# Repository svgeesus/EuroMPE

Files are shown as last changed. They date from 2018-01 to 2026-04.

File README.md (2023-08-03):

# EuroMPE

There are my notes-in-progress on a Eurorack MPE implementation (MIDI to control voltage). There are currently two parts:

- [Polyphonic](./Polyphonic/Design%20notes.md), 4 to 8 voices (historical)
- [Duophonic](./Duophonic/readme.md), 2 voices

The **polyphonic** one was the first thing I explored, but it was eventually abandoned for two reasons. Firstly an eight-voice polyphonic system would be very expensive to build, and the quality I wanted. But more importantly I realised the sheer impracticality of a four or eight voice polyphonic system in Eurorack. Yes, there are quad modules aplenty. But they all have to be set identically which also means, unless you are an octopus, that they all have to be wiggled in unison and that is just nt feasible. And freakishly expensive. So this was shelved.

Somewhat later, after I had got myself a duophonic synth (ARP Odyssey) I came to realise that **duophonic** is a separate thing from fully polyphonic and from monophonic. It makes sense to use two hands and multiple fingers, because as keys lift other notes sound and this is an entirely different playing style. And I figured that MIDI Polyphonic Expression (MPE), which had always interested me, would work well with that. So the [duophonic](./Duophonic) part is where all current development is happening.

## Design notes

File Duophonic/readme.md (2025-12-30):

# Eurorack Duophonic MIDI

Inspired by the use of duophony on the ARP 2600 and Odyssey,
this is a MIDI to CV Eurorack module
with twin outputs:
low-note priority and high-note priority.

Re-utilising designs from the polyphonic Euro-MPE project,
this aims to be a high-precison, flexible, and performance oriented
duophonic MIDI to Eurorack CV module.
It's MPE compatible, so there is independent expression on each of the two notes.

## MIDI connection

There are three MIDI inputs

1. DIN MIDI in
2. USB device in, for DAW
3. USB Host in, for USB keyboards

## Analog voice CV

There are two voice channels, each with:

- color LED for gate and to indicate note played (12 color scale)
- Gate and Trigger, see [Gate/LED](./Gate-LED.md).
- Tuning **input** (from oscillator), see [calibration](./calibration.md)
- Oscillator pitch CV, highly linear [18bit, low tempco DAC](./pitch-dac.md)
  - includes pitchbend (Glide) and any microtuning
  - See [Pitch DAC](./pitch-dac.md)
- Second (identical, but separately buffered) pitch CV output (for dual oscillator voices, or for filter cutoff)
- Four MPE-compatible expression outputs (14bit) per voice, see [Performance DAC](./performance-dac.md)
    1. Strike (attack velocity)
    2. Lift (release velocity)
    3. Slide (forward-back, CC 74)
    4. Press (aftertouch)

Any per-channel calibration curves are still applied, so in monophonic mode two different oscillators which have each been calibrated will play in unison.

## Analog general CC CV

There are also eight general CV outputs (14bit), re-using the same board design that produces the two channels of performance outputs. See [Performance DAC](performance-dac.md). Perhaps (considering mainly the Roli Seaboard):

Top row

- Slider1 (CC107)
- Slider2 (CC109)
- Slider3 (CC111)
- XY Pad X (CC114)

Bottom row

- Modulation Wheel (CC01+CC33)
- Expression Controller (CC11+CC43)
- Breath (CC02+CC34)
- XY Pad Y (CC113)

## MIDI Modes

Probably, only Duophonic MPE mode is needed. See [MIDI](./MIDI.md)

### Monophonic (unison MPE)

Last received note is output on channel one. Any new note overides the previous note.  Channel two duplicates channel one.
Monophonic is MPE-enabled, just outputting to a single voice.

### Monophonic (unison)

Configurable for MIDI channel, or all channels.

### Duophonic (duo MPE)

Lowest received note is output on channel one; highest received on channel two. Duo MPE is MPE-enabled,allocating MPE channels to voices based on lowest and highest note priority.

### Duophonic (duo)

Configurable for MIDI channel, or all channels.

### Harmonic

Like unison MPE, but channel two osc CV is offset (for exampe, by a fifth)

Not clear that the two non-MPE modes are needed. Better if the module accepts either MPE or non-MPE.

## Tuning

Like the original polyphonic EuroMPE, there is a [tuning input](./calibration.md) per channel, which displays the current note; an auto-tuning mode can use this to calculate a linearising calibration curve. Because this is setup not playing, it's okay to go to a menu for this.

?? Because the tuner is in the same module as the MIDI interface, it knows when the gates are low and can do auto-tuning for drift control after x minutes of inactivity ??

## Voltage reference

For the pitch DAC, a Max 6226 hermetic ceramic was originally planned, see [Vref MAX6226](./voltage-ref-MAX6226.md). As that prototype had problems, thee replacement is the [Vref LT1236](./voltage-ref-LT1236.md).

For the performance DACs, the internal reference on the octal DAC is easily sufficient.

## Main MPU board

See [MPU board](./MPU-board.md).

## Power

See [Power](./Power.md)

## Panel

Not settled, but this is the [current panel concept](./mock-channel-front-v2-bigscreen-wider.svg) (SVG)

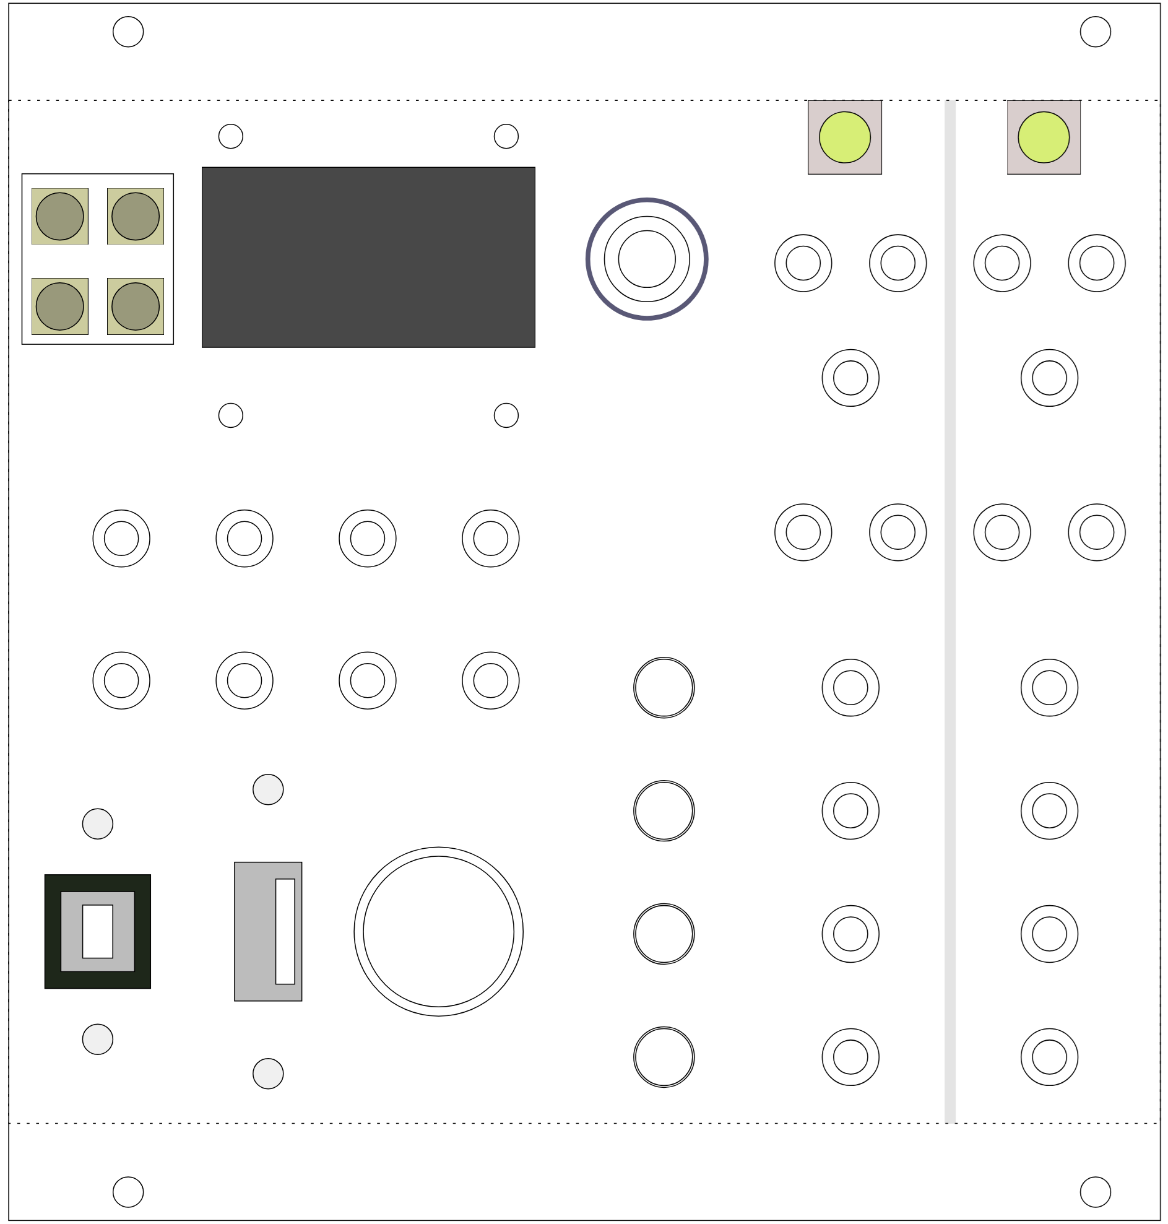
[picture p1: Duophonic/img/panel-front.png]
panel


and also [current panel with boards and components](./panel-layout.svg) (SVG)

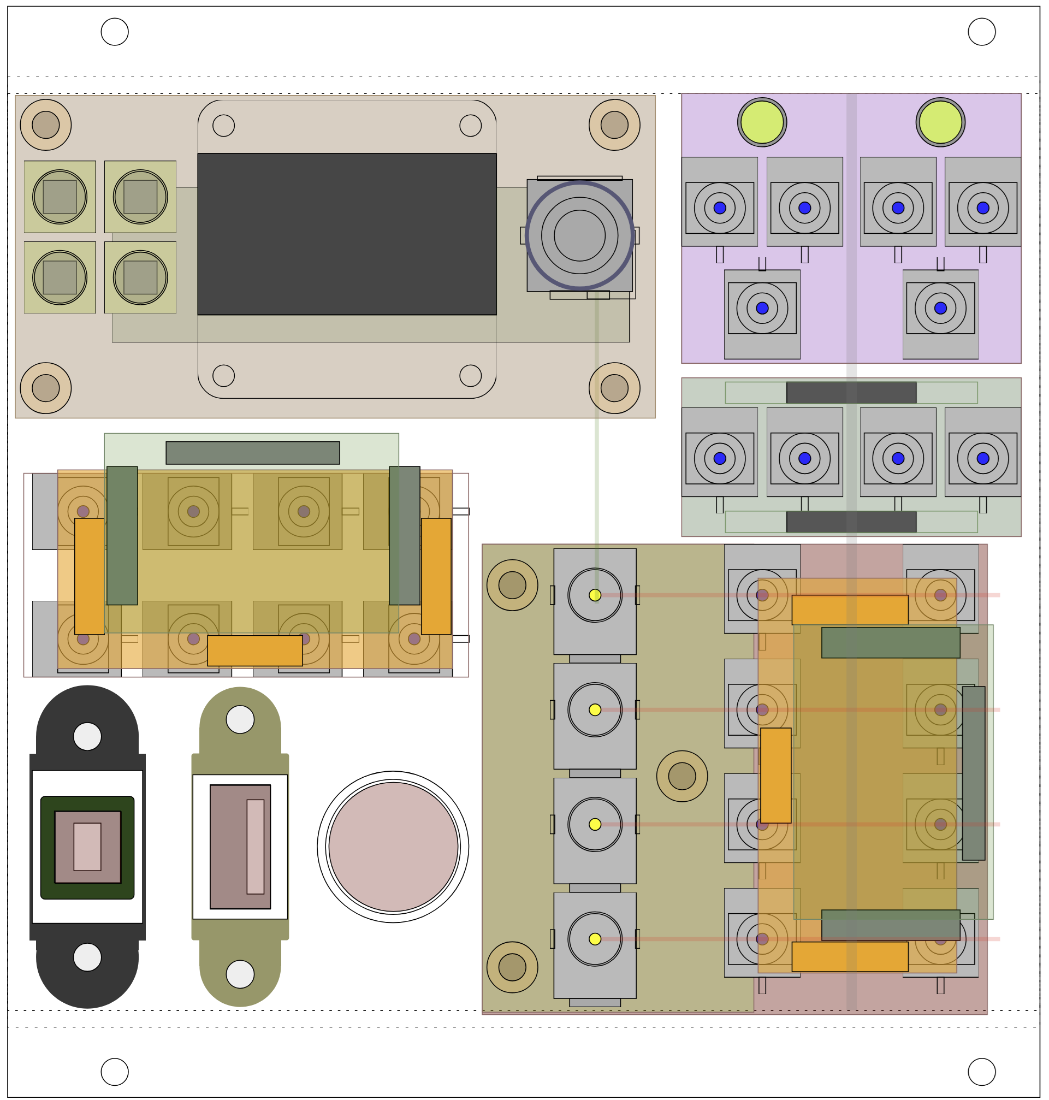
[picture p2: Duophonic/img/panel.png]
panel


## Notes

- [Slide: Absolute vs. Relative](https://support.roli.com/support/solutions/articles/36000025050-slide-absolute-vs-relative)

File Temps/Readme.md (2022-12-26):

# Temps

A multichannel temperature monitoring and datalogging module in 4HP (20mm) or 5HP (25mm). Reads sensors mounted directly on the back of oscillators.

Small, vertical-mounted screen displays currently selected value and stripchart of trend over time.

Pushbuttons select displayed channel. 6 for temps, plus +12V -12V +5V and a reset. Originally thought of RGB LED buttons, to give feedback on status. If non-illuminated then maybe a status RGB LED for green/amber/red temperature stability?

Teensy-LC is fine for the logging, SPI or I2C temp sensors plus display on the other SPI bus; RGB LEDs requires 27 pwm channels, seems like a lot? Depends on availability of RGB LED tact buttons.

Micro-USB on panel for serial datalogging of timestamped measurements.

- Six channels of temperature sensors (4 VCOs, PSU, case for example)
- Voltage monitoring of the three rails
- Relative humidity and atmospheric pressure (not on display, just logged)

## Display

Maybe [Monochrome 128x32 SPI OLED graphic display](https://www.adafruit.com/product/661). Board is 23mm so too wide for 4HP, fits in 5HP. 33mm long, so leaves 77mm for switches and USB. Actual display area 7mm x 25mm, 32x128 pixels, monochrome OLED. SSD1306 driver chip. Uses around 20mA.

## Buttons

Adafruit only has [non-illuminated tact switches](https://www.adafruit.com/category/759) or [huge illuminated switches](https://www.adafruit.com/category/758)

## USB

Maybe [Panel Mount Extension USB Cable - Micro B Male to Micro B Female](https://www.adafruit.com/product/3258) 25.3mm wide. Still not fitting in 4HP or even 5HP. Or [MUSB-K152-30 ](https://eu.mouser.com/ProductDetail/Amphenol-Commercial-Products/MUSB-K152-30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) 20mm wide, has 90-degree PCB mount connection.

## Temperature sensors

[TMP36 - Analog Temperature sensor](https://www.adafruit.com/product/165) $1.50

- analog, 10 mV/°C scale factor (20 mV/°C on TMP37)
- ±2°C accuracy over temperature (typ)
- ±0.5°C linearity (typ)

Needs analog input per channel, so 6 of them. Accuracy seems poor. Cheap.

[DS18B20 Digital temperature sensor](https://www.adafruit.com/product/374) $3.95

- digital (onewire)
- -55 to 125°C
- ±0.5°C from -10°C to +85°C
- 9 to 12 bit selectable resolution

Check the Dallas Temp library plus the Oneire library actually fits on a Teensy LC :(

## Relative Humidity

Maybe [Adafruit BME280 I2C or SPI Temperature Humidity Pressure Sensor](https://www.adafruit.com/product/2652) $19.95. Board is 19.0 x 18.0mm. Bosch BME280 sensor (I2C or SPI) has

- humidity with ±3% accuracy
- barometric pressure with ±1 hPa absolute accuracy, 12 Pascal resolution
- temperature with ±1.0°C accuracy (use for ambient case temp)

Or (humidity and temperature, no pressure)  [Adafruit Sensirion SHT31-D - Temperature & Humidity Sensor](https://www.adafruit.com/product/2857) $13.95. I2C, 2 addresses supported. Board 12.7mm x 18mm.

- relative humidity ±2% accuracy
- temperature  ±0.3°C accuracy

## Atmospheric pressure

Seems newer than BME280, also cheaper, but no humidity) [Adafruit BMP388 - Precision Barometric Pressure and Altimeter](https://www.adafruit.com/product/3966) $9.95. Board is 21.6mm x 16.6mm. Bosch BMP388 sensor (I2C or SPI) has

- barometric pressure with  ±1 hPa absolute accuracy, 8 Pascal resolution, 300 hPa to 1250 hPa
- temperature with ±0.5°C accuracy,  0-65°C

Looks like SHT31-D for humidity and temp, plus BMP388 for pressure (and check on temp) is best solution.

## Voltage rails

A 10V ref plus some op-amps to shift and scale to a 0 to 3V3 range. Jumpers to switch between rails and test points, for calibration. Software calibration based on known voltages. Interesting range is 12.5 to 11.0V

Duplicates functionality of an existing module, but may be better for logging.

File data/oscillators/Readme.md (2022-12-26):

# Oscillators

A study of the tuning accuracy and stability of several analog voltage controlled oscillators.

## Materials & Methods

* Keysight 34465A 6.5 digit bench multimeter
  * instrument ID 869657
  * Cal date: 28 Nov 2017
  * Cal type: Accredited 17025 with uncertainties
  * Cal temp: 23.0C
  * Cal humidity: 23.0% RH

## Notes

Expo converters will have their own errors, so will not give a perfect curve

Oscillators may display self-heating, especially at higher frequencies where currents through the expo converter are higher

Oscillators which use a voltage rail or a voltage regulator as a voltage reference will display very poor line regulations, which will manifest as stability drift over time.

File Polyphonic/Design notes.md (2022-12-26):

# Euro-MPE notes

Goal is a Multidimensional Polyphonic Expression (MPE) implementation for Eurorack, with a focus on
high precision CV generation (especially for pitch) and complete MIDI 1.0 & MPE implementation.

Secondary aim is one-control-per-function, avoiding menu diving for normal operation.

Per-note, that means:

- 16bit pitch CV (for oscillators) from NoteOn, accurate to better than 1 cent over 10 octaves. -3V to +8V
- secondary pitch output (for filters) with both global offset and per-note CV input
- gate and LED from NoteOn/NoteOff
- 4 x 14bit CV for Attack Velocity, Release Velocity, Aftertouch and Glide

Initial design gives four-note polyphony; expander adds another 4 notes to max of 8. (Spec limit is 15, but that seems way high for Eurorack). Plan to build as 4-voice.

## Pitch accuracy and error budget

MPE 14bit glide with 48 semitone range is 4800/16384 = 0.29 cent resolution (244μV).

At ±5V, 16bit, 1LSB = 152μV. 833μV is 1 cent at 1V/oct (5.4 LSB).
    Aim is better than 2LSB (300 μV, 60 ppm, 0.4 cent) overall system performance. Idealy 1 LSB so better than 0.29 cent, but that seems hard.

## Voltage ref

See [Voltage ref](voltage-ref-LM399.md) precise 5.000 0V ref, stable over time and temperature better than 25ppm (125 μV).

## DAC driving

Use one SPI channel for the pitch DACs and a second channel for the performance DACs. There is a third SPI channel, but it is inconvenient to use because it connects via the inner Teensy pads, not the outer pins.

## Pitch DAC

See [Pitch DAC](pitch-dac.md) 16-bit high linearity DAC per voice, with 10 octave (10V) range.

## Secondary pitch output

Global pitch shift (via another AD5542CRZ board) is combined [OP-glob-A, Vishay or LT .01% or .025% quad resistor array] with the main pitch output and a buffered [OP-glob-B, half a quad resistor array] per-note external input to give a secondary pitch output for driving filters.

Pitch shift selected by a rotary encoder with LED and pushbutton. Left to decrease, right to increase in 1 semitone steps and push to reset to zero. I2C is fine as this is low speed, manual use and not rapid use.
[Rotary Encoder - Illuminated (RGB)](https://www.sparkfun.com/products/10982)
[SparkFun Rotary Encoder Breakout](https://www.sparkfun.com/products/11722)
[Teensy Encoder Library](https://www.pjrc.com/teensy/td_libs_Encoder.html)
and an option for hardware quadrature decode
[Hardware Quadrature Code for Teensy 3.x](https://forum.pjrc.com/threads/26803-Hardware-Quadrature-Code-for-Teensy-3-x)

Ideally the external input would have an attenuator, except that needs to be the same value for all 8 voice channels. This can have a slightly more relaxed error budget. Options:

- include a per-note VCA, drive with the Teensy DAC out?
- use digital pots? No, only 5V operation
- rely on an external 2,4,6,8 channel VCA with a single DAC providing the CV to all VCAs. And external multichannel CV mixers.

Or, assuming one of the performance controls is connected to the external input, attenuate those instead:

- rely on digital-domain attenuation on the 14bit per-note outputs (probably sufficient).
- use digital pots? No, lots of pots (4 per note)

## Gate output

Requires 8-10V drive to a gate output; also switch to allow +5V to flow through an LED as indicator (both high side swiching, npn driving pnp). Driven from 3V3 logic high, transition should be 1.5 to 2V. 3-terminal variable regulator to give 6 to 10V from +12V rail.

- [Hinton two-transistor gate, no LED](https://www.muffwiggler.com/forum/viewtopic.php?p=2720659#2720659)
- [PNP high-side switching](http://www.w9xt.com/page_microdesign_pt12_hv_pnp_switching.html)
- [gate buffers](https://synthnerd.wordpress.com/2016/03/17/synth-diy-gate-buffer/)

Pirhana diffuse 5mm rgb, through hole, 7.6mm sq, 20mA max,  $9.95 for 10
experiment, likely good at half power. 3 pins per led.
fixed resistors better than pwm in terms of interference.
8 colors for the 8 voices, easier to set up in software to allow for 4-voice or 8-voice builds.
10mA is 320R red, 200R green & blue. Adjust for desired color.
Or use an external 16-channel PWM chip driven over I2C to offload PWMing the LEDs.

## Performance (Control Change) DAC

See [Performance DAC](performance-dac.md). Provides four performance controls per voice (attack velocity, release velocity, pressure, glide) with 0 to 5V at 12-13ENOB.

## Display, UI

Aim for direct manipulation style. Normal operation requires no menu diving.

Display used for tuning, calibration, and setting of uncommon options.

Simplest to use a second Teensy (LC, or possibly 3.2) to drive the display and handle user interaction. That keeps the code and control flow separate, also frees up an SPI bus for controlling the display. Use I2C or Serial to send commands to the main Teensy 3.6, primarily to go into calibration mode.

The 3.2/LC can also handle oven control duties if those are needed.

## MIDI

Full MIDI 1.0 (including tuning control) and MPE implementation at 14bit accuracy.
See [MIDI notes](midi-notes.md)

## Calibration

Initial setup (trimming), oscillator tuning. See [Calibration details](calibration.md).

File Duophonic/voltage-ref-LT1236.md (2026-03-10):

# Voltage ref

Linear LT1236LS8 has become the alternative to [MAX6226](./voltage-ref-MAX6226.md) which could not be made to work reliably.

[EEVBlog thread on LT1236LS8 internals](https://www.eevblog.com/forum/metrology/decapping-the-lt1236ls8/msg2933682/#msg2933682) and [detailed photos and description (in German)](https://www.richis-lab.de/REF05.htm)

Both use ceramic LS8 package with copper pads underneath the device. This gives improved stability, particularly to moisture and PCB flex, but makes soldering difficult without a reflow oven. Hot air tends to blow the lightweight ceramic chip off the board, so holding in place with tweezers is required.

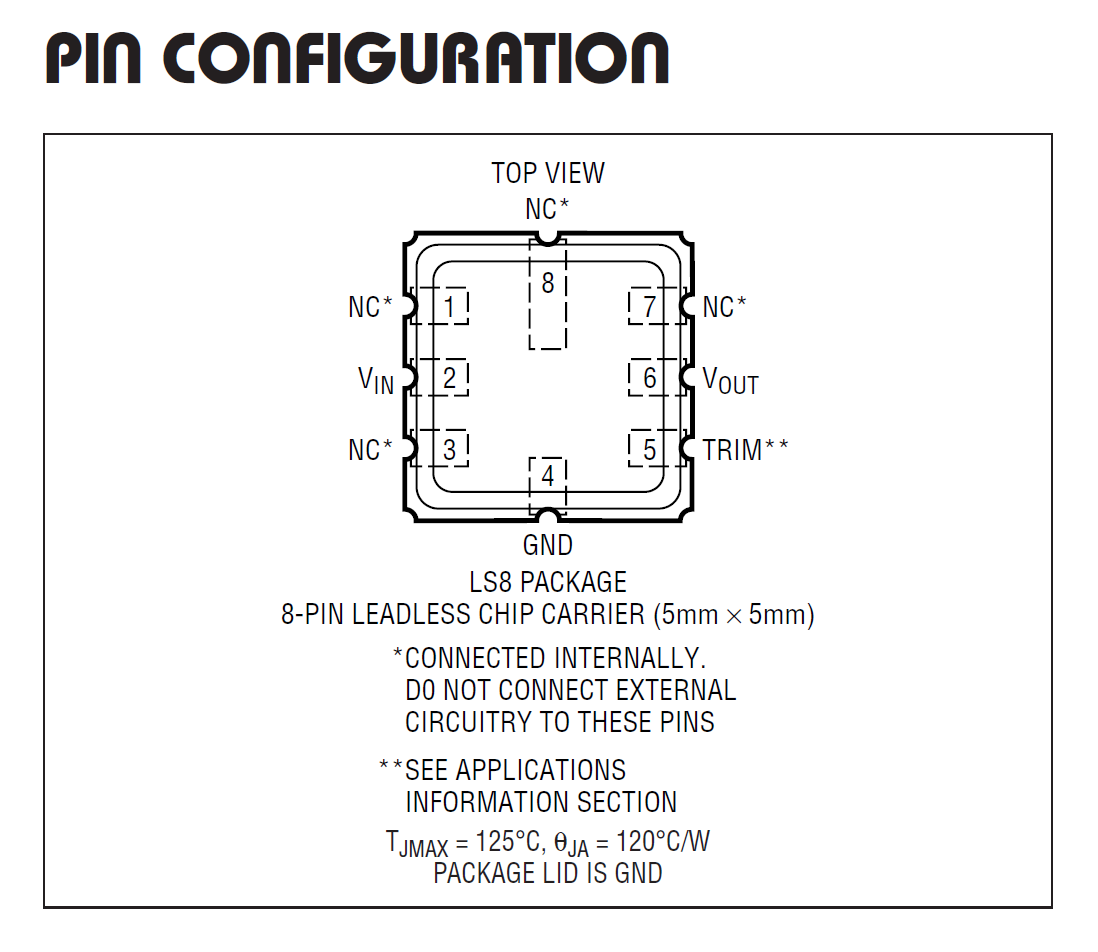
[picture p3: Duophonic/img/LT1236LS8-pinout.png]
pinout


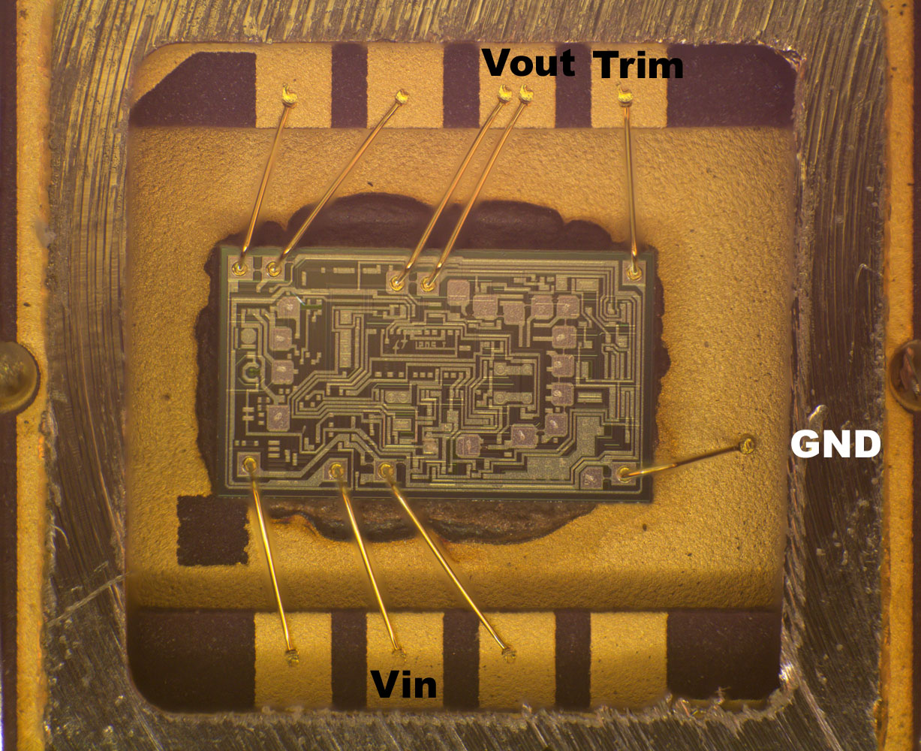
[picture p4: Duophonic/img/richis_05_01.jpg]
internals


Vref board needs to provide both +5V and -5V to drive the pitch DACs.

## Absolute initial accuracy

Good initial accuracy ±0.05% (±2.5mV) for A grade; although less good than MAX6226_50 ±0.02% (±1mV). But it **is** trimmable, using a resistor, diode and multiturn cermet trimmer.

Pin 5 is trim, unconnected if not used; different from MAX6226_50 where pin 5 is output sense.

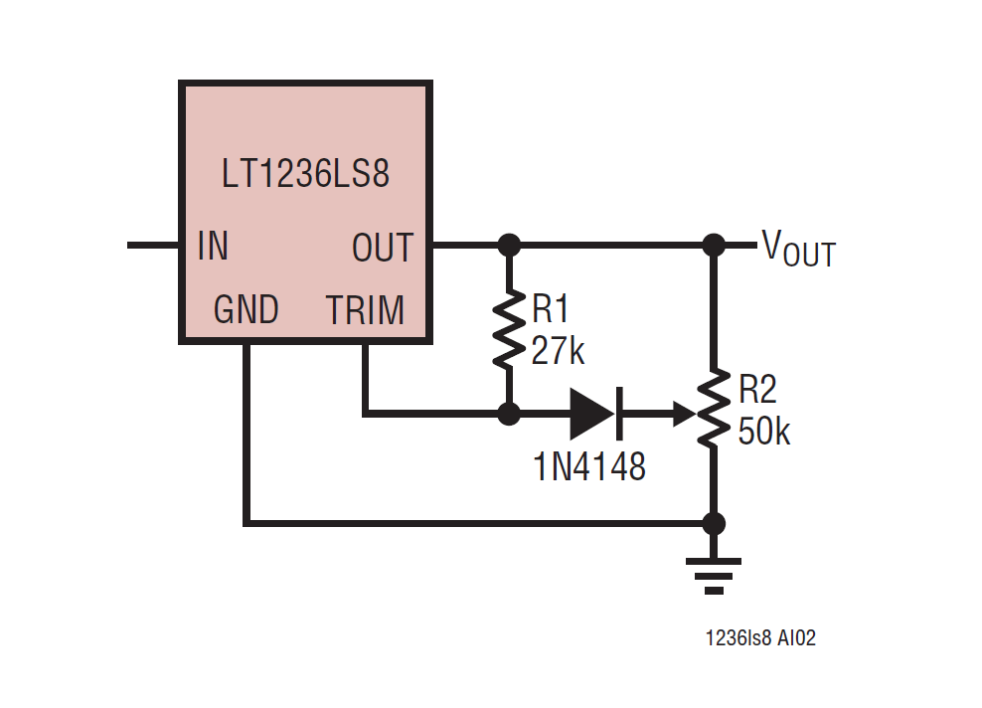
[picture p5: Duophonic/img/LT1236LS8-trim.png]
trim


## Temperature

Fairly good at 2ppm/°C typ, 5ppm/°C max, not as good as MAX6226_50 1ppm/°C typ, 3ppm/°C max.

So a 20C rise gives (5 × 20 / 1E6) × 5V × 1200 = 0.6 cents error, for the positive reference. Negative reference also has the tempco mismatch from the resistors; Susumu RG2012V-182-P-T1 0.02% is 5ppm, adding another 0.6 cents max error.

Bourns wirewound trimmers with 50ppm/°C are fearsomely expensive (3057Y-1-503 is $32.91/1) compared to the 100ppm/°C cermet types (3296P-1-503LF $2.42/1). As this application is ratiometric, the tempco effect should be diminished.

See [Bourns® Precision Trimming Potentiometers with Improved Linearity and Lower CRV](https://www.bourns.com/docs/technical-documents/technical-library/trimmers/technical-articles/bourns_custom_trimmer_white_paper.pdf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)

## Thermal Hysteresis

Very good at 3ppm.

## Long term drift

> The data sheets of many references specify long-term drift—typically about 25 ppm/1000 hr. This error is proportional to the square root of elapsed time, so 25 ppm/1000 hr ≈ 75 ppm/year. The actual rate is likely (but not certain) to be somewhat better than this as the ageing rate often diminishes after the first few thousand hours. So, again, we have a figure around 14 bits.
[Choosing Voltage References](http://www.analog.com/en/analog-dialogue/raqs/raq-issue-114.html)

20ppm/1k hr (100μV), less good than MAX6226_50 11ppm/1k hr (55μV). But trimmable after pre-ageing.

## Current / Load

Load regulation very good: ±25μV/mA max, and the load impedance is high and constant.

This design drives two DACs, so the lack of a kelvin connections is less of an issue.

The [DAC boards](./pitch-dac.md) provide their own force/sense buffers to drive the voltage reference inputs on each DAC.

## Line regulation

Good at 4 (typ) to 12 max μV/V for supply voltage between 7.2V and 10V.

So a [well-regulated supply](./Power.md) is helpful.

### Secondary regulation

Use same regulated +9.5V supply as pitch DACs. Off-board, to protect from thermal effects.

## Noise

**Spectral noise** is 3 μV p-p 0.1-10Hz
**Flicker noise** is 3.5 μV RMS (typ) at 10Hz-1kHz.

These specs are not directly comparable to MAX6226_50 due to different units and bandwidths.

## Buffering

A non-auto-zero, e-trim op-amp such as **OPA2192** is suitable, and input bias current is even lower.

> For the reference buffers, the AD8676 dual amplifier is recommended, based on its low noise, low offset error, low offset error drift, and low input bias currents.
>
> Egan, M. _The 20-Bit DAC Is the Easiest Part of a 1-ppm-Accurate Precision Voltage Source_

 <table>
 <tr><td></td><th>noise</th><th>offset error</th><th>offset error drift</th><th>input bias current</th></tr>
 <tr><th>AD8676B</th><td>125nV RMS</td><td>±12/50 µV</td><td>±0.2/±0.6 μV/°C</td><td>±4.5nA</td></tr>
 <tr><th>OPA2186</th><td>0.1μV (100nV) p-p</td><td>±1/±10 µV</td><td>±0.01/±0.04 μV/°C</td><td>±4.8nA</td></tr>
 <tr><th>OPA2192</th><td>4 μV p-p</td><td>±8/±50 μV</td><td>±0.1/±0.5 μV/°C</td><td><b>±5/±20 pA</b></td></tr>
 </table>

So the OPA2186 is comparable on some criteria and much superior on offset and offset drift. OPA2192 worse on offsets (still very good though) and better on input bias current.

> The input bias current specification of the reference buffers is important, as excessive bias currents will degrade the dc linearity. The degradation of integral nonlinearity, in ppm, as a function of input bias current, is typically:
>
> Extra INL error = (0.2 * Ibias) / (Vrefp - Vrefn)^2
>
> where IBIAS is in nA; VREFP and VREFN are in volts. For example, with a ±10-V reference input span, an input bias current of 100 nA will increase the INL by 0.05 ppm.
>
> Egan, M. _The 20-Bit DAC Is the Easiest Part of a 1-ppm-Accurate Precision Voltage Source_

OPA2192: 0.2 × 0.005 ÷ (10²) = 0.000,01 ppm

AD8676B: 0.2 × 4.5 ÷ (10²) = 0.009 ppm

Maybe try a non-autozero non-chopper op-amp. **OPA2192** looks suitable: Vos ±8μV typ, ±50μV max, drift ±0.1 typ, ±0.5 max μV/°C.

See figs 32 and 33 in the datasheet:

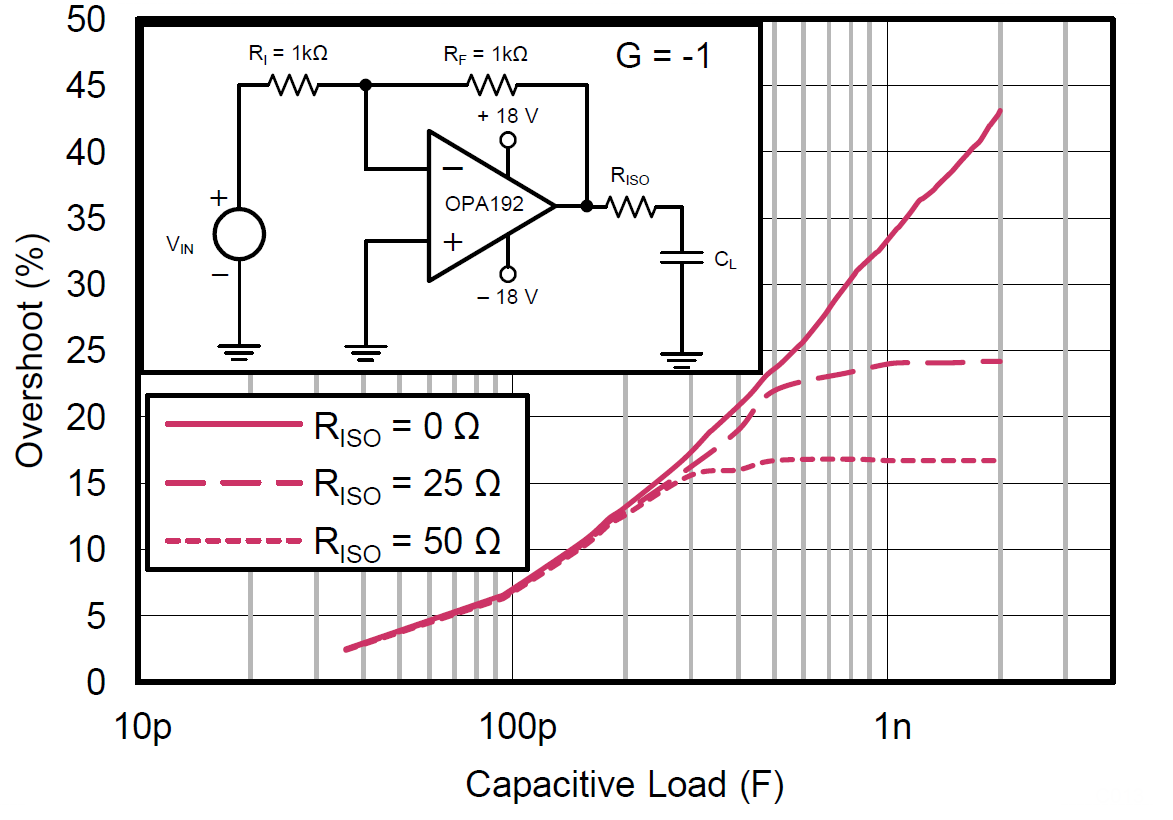
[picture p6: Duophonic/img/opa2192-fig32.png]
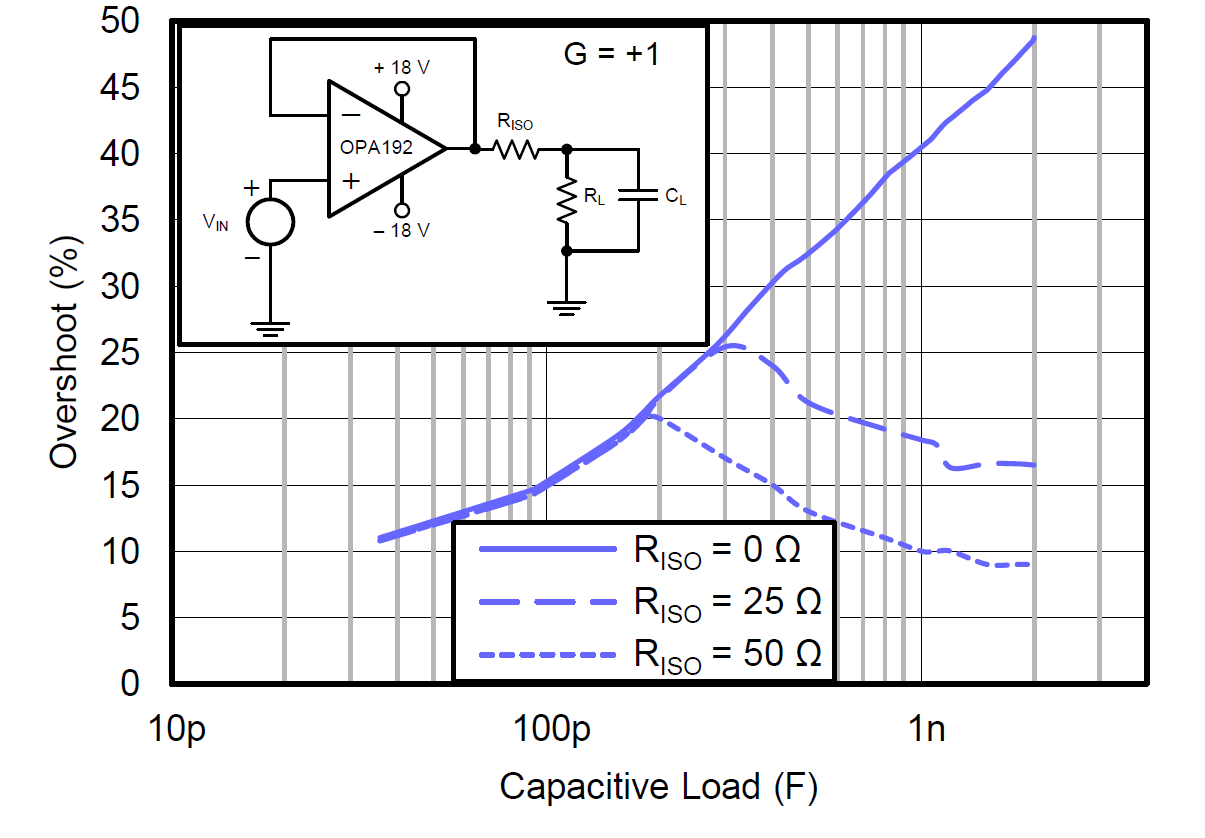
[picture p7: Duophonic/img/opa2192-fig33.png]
 

See Figure 69. Precision Reference Buffer in the datasheet (driving a 10μF capacitive load with great stability).

Pair of close-tolerance low thermal drift resistors for the VrefN op-amp.
Use of Vishay matched-pair resistors [suggested on EEVBlog](https://www.eevblog.com/forum/metrology/max6226-vref-and-ground-planes/msg4725761/#msg4725761) such as [these](https://www.mouser.com/ProductDetail/Vishay-Thin-Film/MPM2002QT3?qs=KOdD7VNvzR83jUiiLOdaaQ%3D%3D) 10k/10k 0.01% ratio, 25ppm/°C.
Is it feasible to make a board that accepts either?

Decoupling caps.

Use small serial resistors for the larger decoupling caps because too-low ESR of the ceramic caps might affect stability. Can test with either 5R resistors or solder bridge to see the effect.

## Schematic

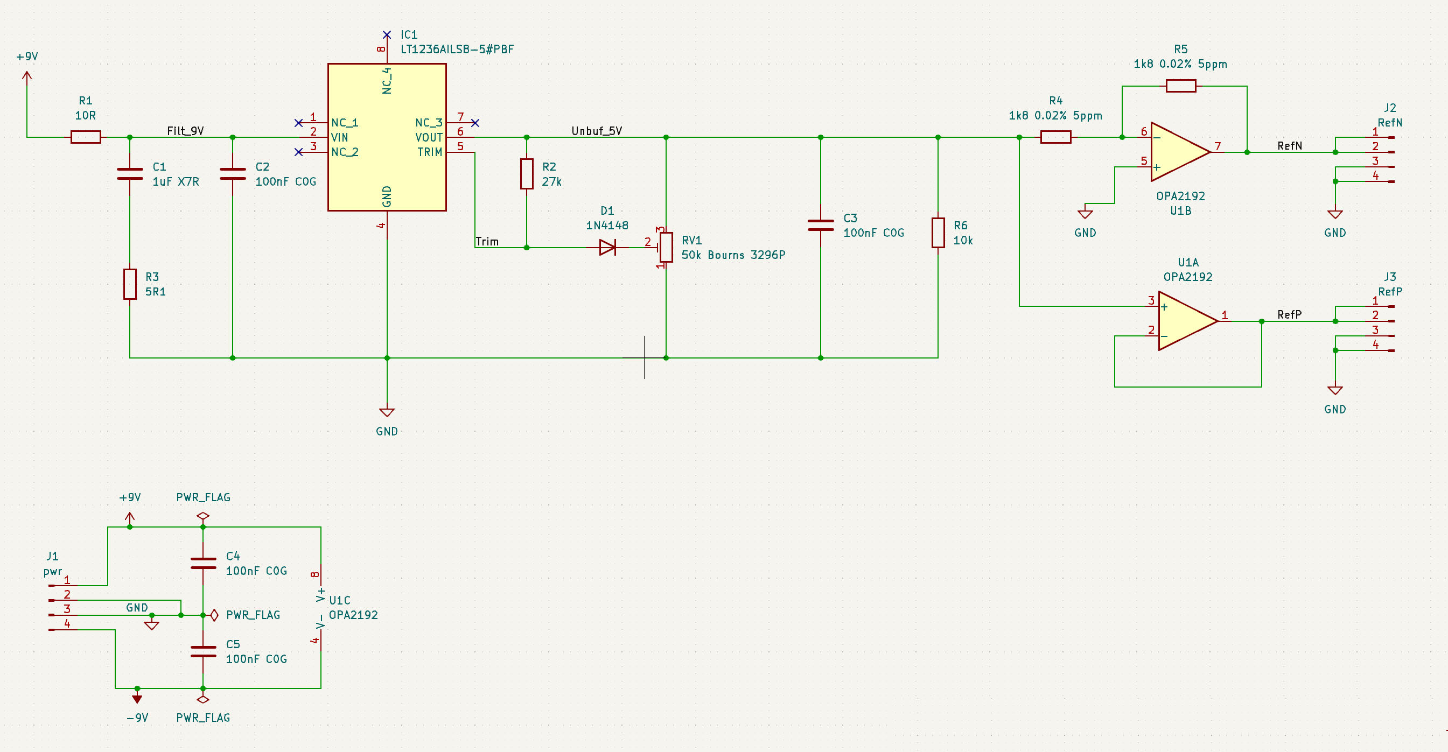
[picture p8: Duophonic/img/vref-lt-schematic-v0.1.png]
schematic


[schematic (PDF)](./vref-lt-schematic.pdf)

## Board design

Power input: 4 wires +9.5, 0V, 0V, -9.5.

1μF and 100nF input caps, 1μF (or less; that is a maximum) and 100nF output caps, all C0G ceramic. Later went for X7R on the 1μF for cost and footprint reasons.

> Because of internal current drain on the output, actual
worst-case occurs at ILOAD = 0. Significantly better load
transient response is obtained by moving slightly away
from these points. See Load Transient Response curves
for details
(Datasheet, "Capacitive Loading and Transient Response")

Thus, 10k load resistor draws constant 0.5mA from reference
(assuming drain from the op-amp input currents is negligible in comparison).

Voltage output: pair of 4-pin headers

- +5 +5 0V 0V
- -5 -5 0V 0V

Full bottom ground plane; top ground connections with vias by caps and GND connection, runs under device

Pin 1 of LT1236 is indicated by a circular mark and is aligned to the top-left corner on this board (indicated by small dot on silkscreen).

Pin 1 of OPA2186 is on the side with the bevel, and is aligned closest to J3 on this board.

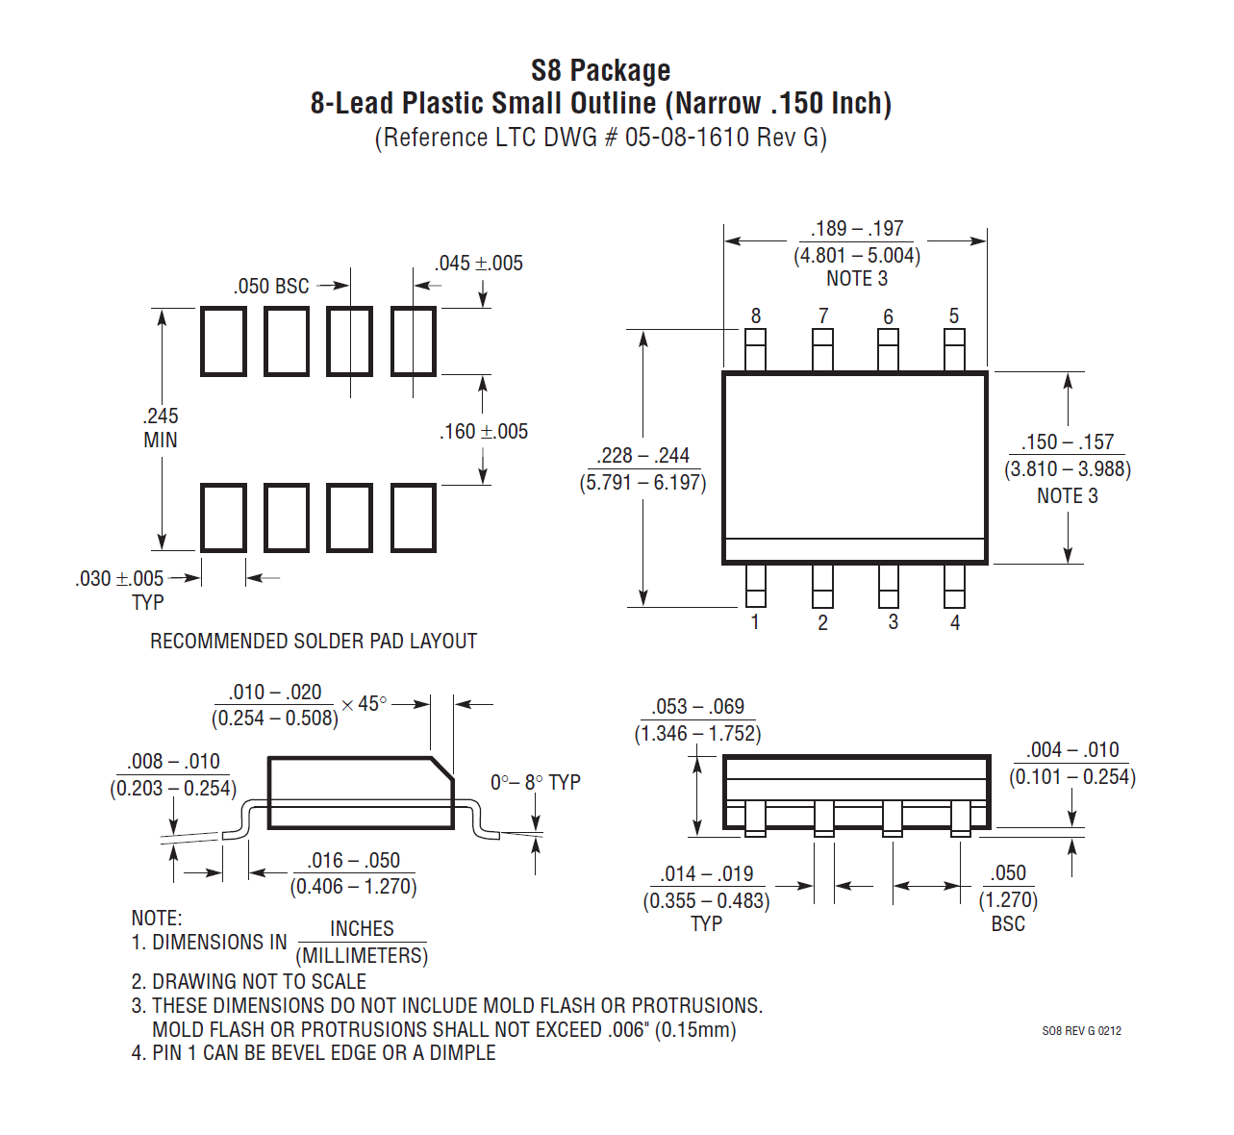
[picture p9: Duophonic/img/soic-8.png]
soic-8


Input cap has [5R serial resistance](https://www.eevblog.com/forum/metrology/yet-another-basic-10v-reference-tear-my-design-apart!/msg1666097/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) to avoid ringing. Electrolytics were better here than ceramics.

> In critical applications,
a 10μF solid tantalum capacitor with several ohms
in series provides optimum output bypass.
(Datasheet, "Capacitive Loading and Transient Response")

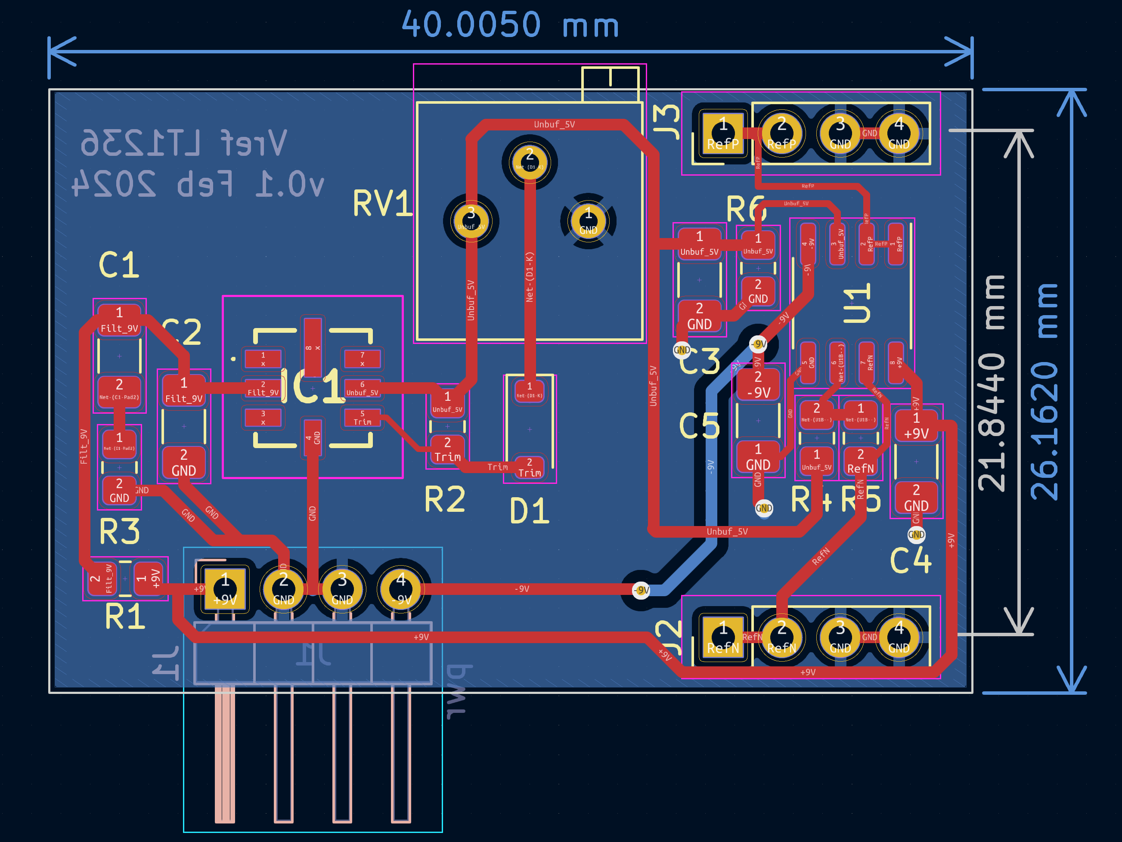
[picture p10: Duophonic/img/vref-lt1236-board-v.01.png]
Vref


2 layer board of 1.57 x 1.03 inches (40.0 x 26.2 mm) ordered 2024-02-10

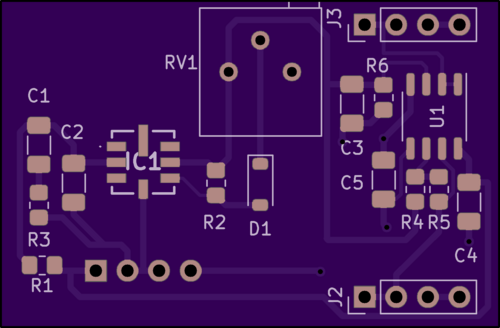
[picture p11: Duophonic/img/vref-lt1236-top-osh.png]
top
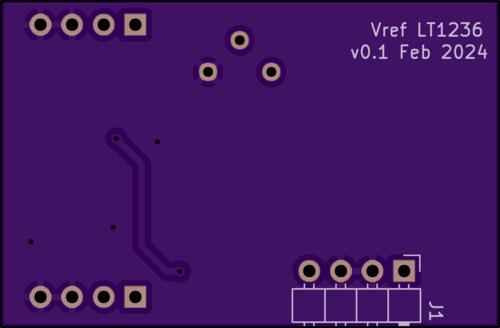
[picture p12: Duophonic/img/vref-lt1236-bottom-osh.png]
bottom
 top and  bottom

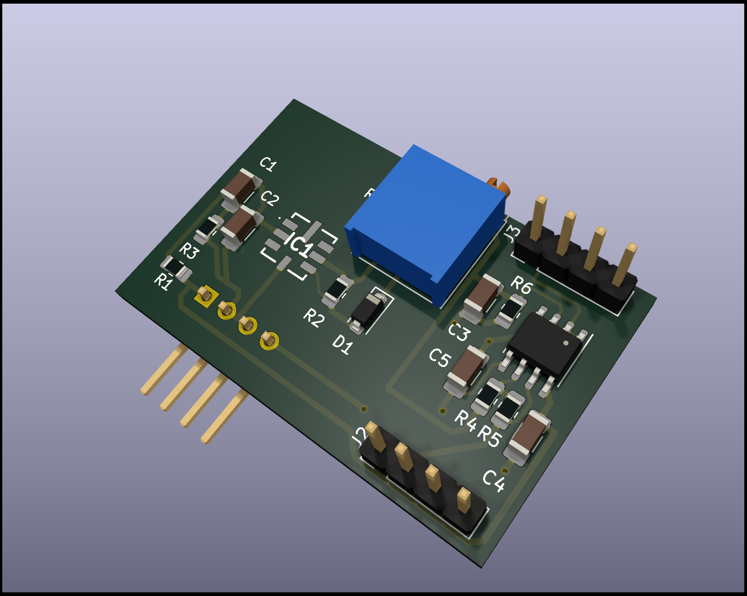
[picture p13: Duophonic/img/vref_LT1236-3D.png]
Vref 3D

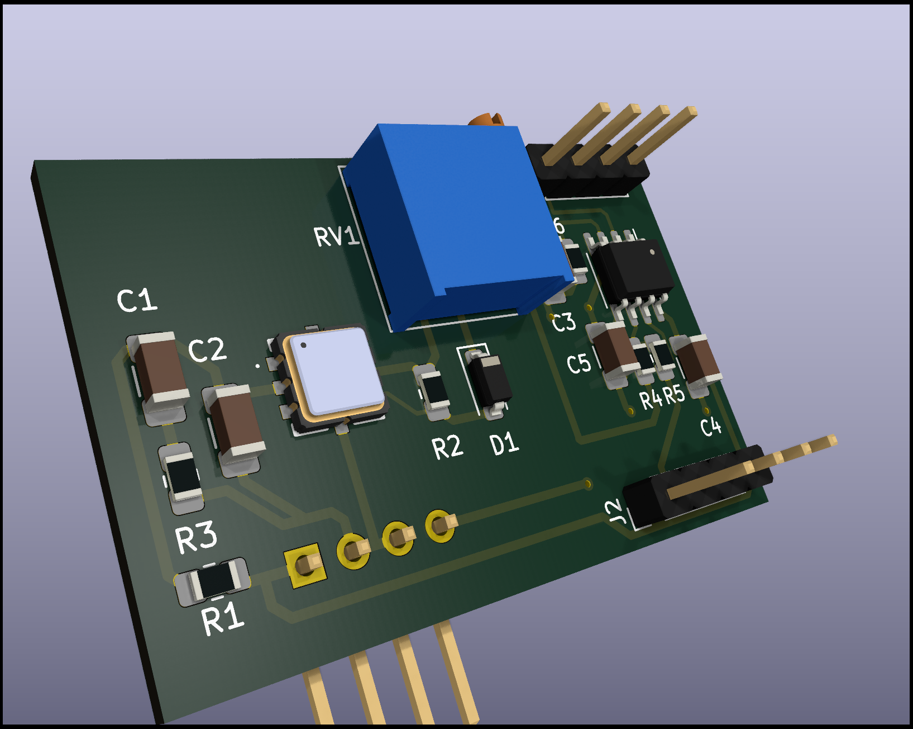
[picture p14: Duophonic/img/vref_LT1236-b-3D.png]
Vref 3D alternate view


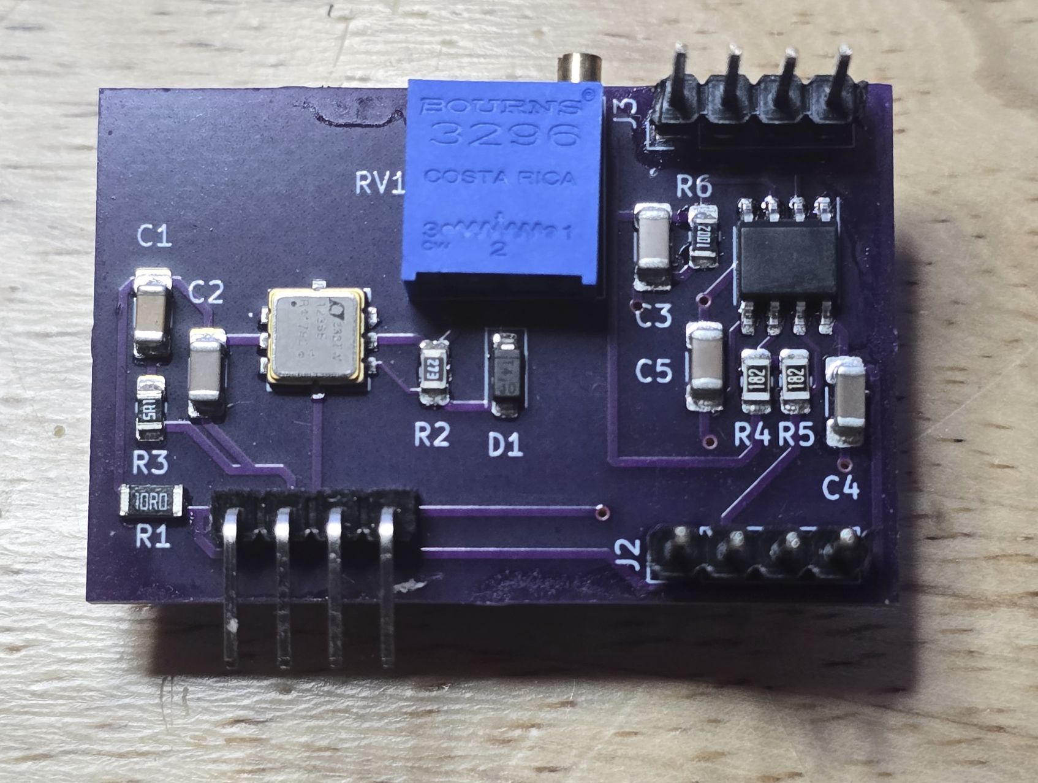
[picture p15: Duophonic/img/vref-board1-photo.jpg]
board1

Board 1, with Susumu 0.02% 5ppm resistors.

## BOM

### Voltage reference

(1) [LT1236AILS8-5#PBF ](https://www.mouser.com/ProductDetail/Analog-Devices/LT1236AILS8-5PBF?qs=ytflclh7QUXCvMb52%2F4eDQ%3D%3D) Ceramic LCC $11.77/1 = **$11.77** **GOT 4 24 Feb 2024**
IC1 now **$15.84/1** and **GOT 3 more 8 Feb 2026**

### Low Vos low Ibias precision op-amp (dual)

(1) TI [OPA2192IDR](https://www.mouser.com/ProductDetail/Texas-Instruments/OPA2192IDR?) SOIC-8 $4.63/10 = **$46.30** **GOT 10 Dec 2023**
U1

### Decoupling caps

(4) Kemet C1206C104K3GEC7210 25V 100nF C0G 1206 ceramics $0.051/100 = **$5.10 GOT**

### Bulk ceramic caps

(1) C2,C3,C4,C5 Kemet C1206X105K3RACTU  25V 1μF X7R 10% 1206 ceramic $0.839/10 = **$8.39 GOT**

or

(1) C1 muRata GRM31C5C1E474JE01L 25V 0.47μF G0G 5% 1206 ceramic $0.474/10 = **$4.74** **GOT 10 24 Feb 2024**

### Low-ppm close tolerance resistors

(2) R4, R5 Susumu RG2012V-182-P-T1 1.8k 0.02% 5ppm 0805 $2.30/10 = **$23.00 GOT** 6 ordered 8 Dec 2023 **GOT 6 more 24 Feb 2024**

OR

(2) R4, R5 Vishay Precision Group Y16292K50000T9R  2.5k 0.01% ± 0.2 ppm/°C 0805 foil $12.74/1 = **$25.48** at minimum (need more for multiple boards, for testing). **GOT 4 26 June 2025** and **GOT 4 more 8 Feb 2026** which were cheaper, **$8.53/1**
Note these are metalized _one side only_, difficult to hand-solder!

### Generic ESR-increasing, trimming, and load resistors

- (1) R3 Yaego RC0805JR-075R1L 5.1R 5% 0805 thick film $0.026/10 = **$0.26** **GOT 10 24 Feb 2024**
- (1) R1 Yaego RC0805FR-0710RL  10R 0805 $0.027/10 = **$0.27** **GOT 10 24 Feb 2024**
- (1) R2 Yaego RC0805FR-0727KL 27k 0805 $0.016/10 = **$0.16** **GOT 10 24 Feb 2024**
- (1) R6 Yaego RC0805FR-0710KL  10k 0805 $0.016/10 = **$0.16** **GOT 10 24 Feb 2024**

### Diode

(1) 1N4148 Diodes Incorporated 1N4148W-7-F SOD-123 $0.095/10 = **$0.95** **GOT 10 24 Feb 2024**

### Trimmer

(1) Bourns 3296P-1-503LF $2.13/10  or $2.42/1 get 5 = **$12.10** **GOT 5 24 Feb 2024**
(Currently out of stock at Mouser, oddly, until Nov 2025)

### PCB

Ordered OSH Park 10 Feb 2024. 3 more ordered 8 Feb 2026.

### Pin connectors

Right-angle 0.1" connectors
(1) Adafruit Break-away 0.1" 36-pin strip right-angle male header (10 pack) **$5.95**
https://www.adafruit.com/product/1540 **still** out of stock

Mouser [TE 9-103329-0 40-position](https://www.mouser.com/ProductDetail/TE-Connectivity/9-103329-0?qs=UDe5jPXu0mTGA7O7jC9MlQ%3D%3D) **$2.31/1** **GOT 3** 

Double ended connectors
Adafruit Extra-long break-away 0.1" 16-pin strip male header (5 pieces) **$3.00 GOT**
https://www.adafruit.com/product/400

pins are (measured with micrometer) 45.06 ÷ 2 = 22.53mm apart

## Work plan

- [x] Design v0.1 Vref board with dual op-amp
- [x] Fab v0.1 board
- [x] Check existing component inventory
- [x] order Vref, op-amp (same as pitch DAC uses)
- [x] Build, test
- [x] Burn-in
- [ ] Do stability analysis for innie OPA2192 with 2 R and 1 C
- [x] Design and fab temporary [power board](./Power.md) to test for ripple, noise, need for isolation resistors
- [x] Build second board, with Vishay metal film resistors
- [x] Burn-in and test second board
- [ ] Burn-in and test third board, sigh

## Test results - positive reference

### Power

Measured with Joranalogue Test3, combination of [power board](./Power.md) plus Vref is drawing (peak) 5mA on +12V, 4mA on -12V.

### Poem

From [EEVblog post](https://www.eevblog.com/forum/metrology/lt1236ls8-drift-on-power-restart-mechanism-of-action/msg6009147/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),
explaining why even a hermetic, ceramic package
shows medium and long term drift over power cycles:

> O fair silicon, child of heated breath,<br>
> Thy tender frame swells ‘neath the kindly flame;<br>
> Yet ceramic walls, cold in steadfast death,<br>
> Refuse thy plea, nor share thy swelling frame.<br>
> Now wires of silver strain as captives bound,<br>
> Their trembling strength bespeaks the coming woe;<br>
> A crack! — like ice that splits on frozen ground —<br>
> Proclaims that war ‘twixt heat and cold doth grow.<br>
> Thus physics writes in bonds both fierce and small,<br>
> The tale of love where neither side may bend;<br>
> And so within this package’s fragile wall,<br>
> Expansion meets resistance — and meets its end.<br>

### Initial power-up

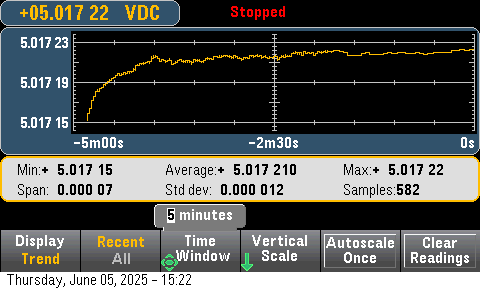
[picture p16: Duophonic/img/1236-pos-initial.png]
initial


Board #1 measured using Keysight 34465A, 10V range, 100PLC. Reference chip 1 **5.01721V**  (range 5.01715 to 5.01722). Climbed fractionally over first minute (chip warmup?) then stable.

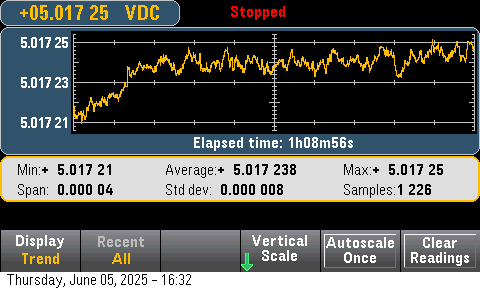
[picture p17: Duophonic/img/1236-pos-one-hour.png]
pos


Stable at **5.017 24V** over 1 hour (range 5.01721 to 5.01725)

### Trimmed

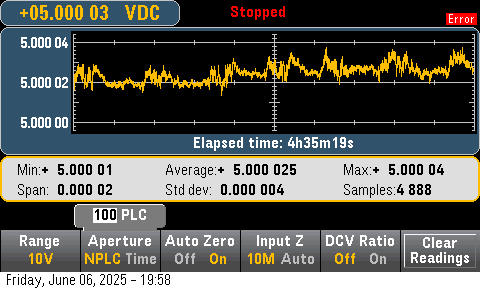
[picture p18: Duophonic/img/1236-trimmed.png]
trimmed


Board #1 trimmed to **5.000 025V** an error of 25μV or 0.03 cents.

### Burn-in

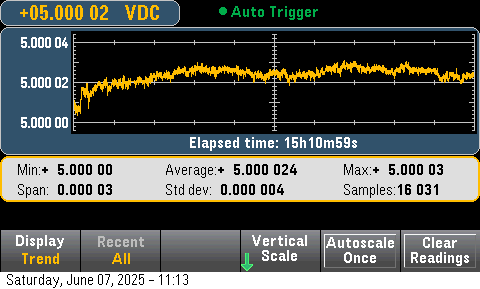
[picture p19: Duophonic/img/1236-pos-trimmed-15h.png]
trimmed-15h


Board #1 overnight, fairly stable at **5.000 024V** sd 4μV.

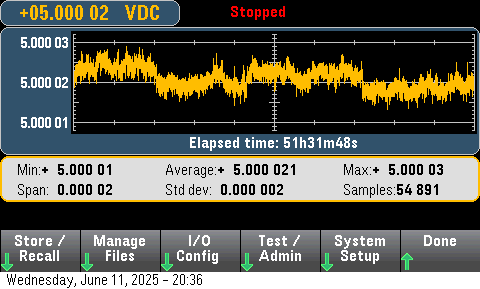
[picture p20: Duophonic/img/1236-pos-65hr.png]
56hr


Four days later, still stable at **5.000 021V** sd  2μV.

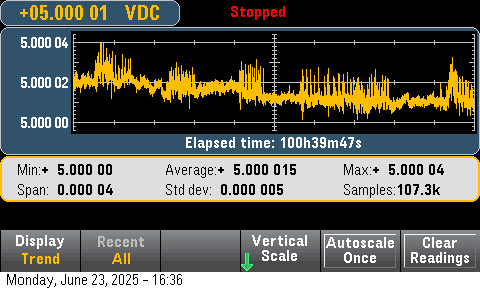
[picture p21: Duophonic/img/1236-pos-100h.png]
100h


Long-term monitoring (100 hours) slight downward trend as it matures and settles,
and small spikes due to air conditioning switching on and off during the day.
Mean is now **5.000 015V**. Reference has been on for over 400 hours now.

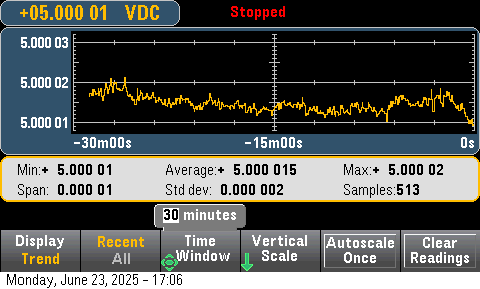
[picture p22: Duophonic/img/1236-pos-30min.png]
30min


The short term stability (air conditioning off) also looks good.
sd  2μV
Accuracy also looks great, 3ppm (15μV) high.

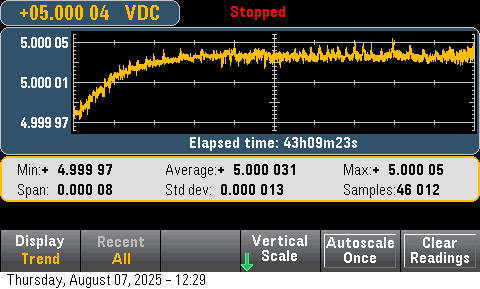
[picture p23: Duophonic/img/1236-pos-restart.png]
restart


Restarting the board #1 reference after a couple of weeks off, and discarding the first 10 minutes to allow for warmup, the value started 12ppm low and climbed over 12 hours to a steady-state value of **5.000 031V**

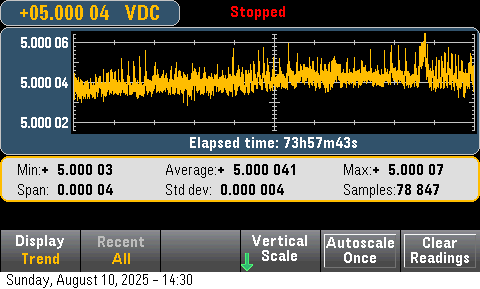
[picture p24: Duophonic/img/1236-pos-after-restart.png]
after restart


A further 72 hours after restart, **5.000 041** sd 4μV

### Board #2 (Vishay metal film)

board 2

Board #2 (untrimmed, after 160 hours burn-in) shows **4.976 508V** sd 2 μV.

board 2 trimmed

Board #2 after trimming. The early part of this trace shows the mechanical settling of the trimmer screw after trimming. The last portion shows the effect of air conditioning switching on and blowing gusts of cold air across the board. This indicates that the board should be insulated with wadding above and below. The central trace showed **4.999 999V** sd 2μV.

Board #2 after 3 months storage (unpowered) shows a small rise (17ppm)
to **5.000 087V** sd 1 μV.

### Board #1 (again)

100hr

After a one hour warmup, a hundred hour log shows a slow settling (perhaps die stress settling) from **5.000 04V** to **5.000 08V**. While noteworthy from a metrological perspective, this 40μV rise corresponds to 48 milli-cents and is thus musically insignificant.

## Test results - negative reference

neg

Board #1 stable at **-5.017 47V** over 2 hours with some cyclic drift (range -5.01749 to -5.01747).

neg 2

Board #2 inital startup **-4.976 49V** over 2 hours

### Burn-in

neg-trimmed

Board #1 positive ref trimmed as noted above. Negative ref is **-5.000 292V** implying the inverting op-amp has an actual gain of -5.000281 ÷ 5.000024 = **-1.000 054**, a mismatch of -0.0000535 × 100 = -0.00535% or 51ppm. Good result considering the pair of 0.02% resistors used.

later

Later, mean value drifted only fractionally, to **-5.000 293V**

even later

and a week later essentially identical, **-5.000 294V**

Used without correction (i.e. assuming the reference is -5V) 
board #1  gives an error of 0.000294 × 1,200 = **0.3528 cents**.

Drifting is likely caused by tempco of the matched resistor pair (Susumu RG2012V-182-P-T1 1.8k 0.02% 5ppm/°C) as it is not observed on the positive voltage output, only the negative. This rules out Vref tempto (2ppm/°C typ, 5ppm/°C max). Lacking simultaneous measurement of the positive and negative outputs (only one 6.5 digit DMM) this cannot be completely ruled out, however.

drifting

Board #1 160 hour monitoring still shows some overall drift and some temperature-relted cycling with the AC.

Plan to build a second board with the Vishay metal film resistors.

after restart

After shutting down board #1 for 4 days then restarting soak, a shift was observed then a gradual drift over two hours to the previous value.

over temp

Board #1 98 hour soak, second half with AC off and window open so larger temperature swing (18 to 26C) still variation is fairly small. Lowest **-5.000 29V** highest **-5.000 25V**

### Board #2 (Vishay metal film)

board 2

Board #2 still settling in for 20 hours, general trend is lower voltage over time. Total on-time around 24 hours for this board, not yet trimmed.

board 2 62hr

Board #2 after 100 hours total burn-in and one month powered off, measured for 62 hours, **-4.977 413V** sd 7μV. Again a gradual shift over the first 12 hours after power-off.

board2 30min

Board #2 short-term stability, **-4.977 419V** sd 2μV.

Resistor matching for board #2: gain is -4.977419 ÷ 4.976508 = -1.000 183 (183ppm error)

board 2 trimmed

After trimming of positive ref to 4.999 999V, negative ref shows 
**-5.000 897V** sd 3μV over 24 hours. 

This is slightly higher than expected given the previous estimate of gain. New gain estimate is -5.000 897 ÷ 4.999 999 = -1.000 179  (179 ppm error).

board 2 long term

Long-term 150 hour test (no air conditioning, so daily temperature fluctuations) after trim. **-5.000 892V** sd 4μV is _entirely consistent_ with earlier result.

board 2 short term

After that, a short-term 30-minute run has the same mean value **-5.000 895V** with of course a tighter spread: sd 1μV. These are very good results and the tempco-induced variation in the negative reference is way below musical relevance (4.8 millicents!).

Feb 2026: the negative reference now emits a zero voltage. Possibly the badly-soldered precision resistor pair? Removed then from the board, measured resistnce (hard to do on such tiny components) seemed ok and no obvious shorts.

Plan to make a third board from scratch because attempting to re-solder the resistors by hand was difficult with other large components already fitted.

### Board #1 (again)

board 1 restart

March 2026: A quick retest of board #1 shows a three-hour settling-in period followed by stability at **-5.000 297V**, similar to the previous value of **-5.000 269V**

board 1 longer term

Overnight test shows **-5.000 294V** sd 4μV.

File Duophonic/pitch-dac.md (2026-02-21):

# Pitch DAC

Initial plan was to use a very linear, well behaved 16-bit DAC per voice (so, two needed).

Over 10 octaves, at the desired precision, 16 bits is barely sufficient (0.2 cents). More bits would be desirable, to give finer precision and to allow for the loss of precision from using a calibration curve. However, 20bit or 18bit DACs can be expensive, and some are no better than 16bit INL; 24bit DACs are widely available and cheap, but tuned for audio AC performance not DC accuracy and linearity.

_AD5542CRZ_ (SOIC-14, now $52.61/1 in stock **got 6 Jan 2018** when they were $35), same as I used in my previous, mono, MIDI2CV project, provides bipolar ±Vref output (so, ±5V) with one bipolar-powered op-amp in the output loop. Power up to +5V5. INL ±0.5LSB (typ) ±1.0LSB (max, = 15ppm) for best (C) grade. DNL is ±1 LSB max = 15ppm. SPI needs 16bit transfer.

**AD5781ARUZ** (TSSOP-20, $40.96/1 no stock til 03 April 2023) 18bit. INL ±1 LSB (max, 5V vref, = 3.6ppm) for B grade, ±4 LSB (max, = 15ppm) for A grade. Better B grade is $56.04/1. A grade has more resolution, but same INL, as the 16bit AD5542CRZ. Digikey has A grade at $40.96, no stock_    DNL however is ±1 LSB max = 3.6ppm for _both_ grades. Bipolar ±Vref output, power up to ±16.5V. SPI needs 24bit transfer. Needs Schottky diode for power rail syncronization, see datasheet fig. 50. A grade is actually less expensive than AD5542CRZ, with better DNL.
**Got 1, May 2020**.

_AD5791BRUZ_ (TSSOP-20, $129.80/1 in stock) or _AD5791ARUZ_ (TSSOP-20, $80.46/1 in stock) 20bit, 1ppm linearity, bipolar ±Vref output, power up to ±16.5V. Very expensive. However they are exactly pin-for-pin compatible with AD5781 so could be swapped in if needed.

Conclusion: 18 bit **AD5781ARUZ** gives 16bit INL with 18bit DNL at slightly lower cost than the 16-bit AD5542CRZ.

DAC pinout

If I **totally** can't get this DAC to work then a possible (but inferior) option is MAX5719AGSD+ which is 20bit, though worse INL, limited to unipolar 0 to 5V5 so would need a "double voltage and subtract 5" stage which introduces resistor tolerances into the scheme. Has force, sense input for Vref and GND. It does have internal resistors for bipolar. Looks to be a "good 16/ok 18/we also make a 20" bit device. Midscale error is 80LSB which is 380μV !! **$41.49/1**.

>     However from a performance perspective, AD5791 beats the MAX5719.
> All day long.......
>
> AD5791ARUZ = £57+VAT
> AD5791BRUZ = £88+VAT
> MAX5719AGST = £33+VAT
> 
> The AD5791 has a much, much better INL, but is more complicated to use as it needs a split rail power supply. Believe me I tried back in the day but I just couldn't get the BOM cost numbers to work.......and sadly there wasn't really any other 20bit DAC's available in that class. I remember even trying a dual DAC prototype......but that gets quite complicated......I still have nightmares about it!
> 
> The MAX5719 is a great, GREAT compromise all things considered......IMHO.
> [Ian Johnson on EEVblog](https://www.eevblog.com/forum/metrology/new-pdvs2mini-dc-voltage-reference-from-ian-johnston-reviewed/msg6049215/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)

## Power

AD5781ARUZ Vdd and Vss abs max of 16.5V. Spec sheet assumes VDD = +12.5 V to +16.5 V, VSS = −16.5 V to −12.5 V. Optimal supply for lowest zero-scale and gain errors is ±9.5V (datasheet, figs 20 & 22, _noting results are given for 5V and for ±10V spans while I need a ±5V span_).

Voltage dependent zero-scale errors

> The AD5781 accepts a positive reference input in the range 5V to VDD – 2.5 V and a negative reference input in the range VSS + 2.5 V to 0 V.

So on ±9V5 positive Vref up to +7V and negative Vref -7V to 0V.

Advantage of ±12V-derived ±9V5 rails, compared to using Eurorack 5V power, is that filtering and smoothing can be applied, reducing switching PSU noise and increasing decoupling from the digital circuitry running on Eurorack 5V. Bipolar supply is required; enables bipolar output and for 0V output, Vss -2.5 or lower is needed.

## Digital interface

With Teensy 4.1, for AD5781ARUZ no level shifters needed.

Data is written to the AD5781 in a 24-bit word format, which sadly precludes SPI.transfer16() or SPI.transfer32(); however there is an [SPI.transfer(buffer, size)](https://docs.arduino.cc/language-reference/en/functions/communication/SPI/transfer/), where size would be 3, which might work, see [example](https://forum.pjrc.com/index.php?threads/spi-write-24bits.74194/#post-336450). Another option (without buffer overwrite) is [SPI.transfer(txBuffer, rxBuffer, cnt);](https://forum.pjrc.com/index.php?threads/spi-write-24bits.74194/#post-336456) where rxbuffer can be NULL

Datasheet says 35 MHz Schmitt triggered Digital Interface. However, minimum CS (SYNC) high time 48ns. SCLK min cycle time 40ns which is 25MHz. So use well below that (start at 10MHz).

dac register

To write directly to DAC register, the R/W bit is 0 (see datasheet Table 7) and the address bits are 0 0 1 (see Table 8). The 20 bit register data is 18 bit data, pad LSB two bits with zero, although the chip doesn't care. This is the same format as the 20-bit AD5791.

Demo sketch in [pitch_DAC18_explorer_01](sketches/pitch_DAC18_explorer_01).

To isolate from digital 0V noise, consider optical isolator. ISO724x high speed quad isolator (got 2, Jan 2018). MOSI, SCLK, CS/SYNC and ?LDAC however AD5781 has separate DGND, AGND pins. Also isolator would need separate, DAC-side 3V3 supply. So, NO.

[10k pullup on SPI CS line](https://www.pjrc.com/better-spi-bus-design-in-3-steps/).

Use series 100R on MOSI and CLK to reduce reflections and ringing; monitor waveform on a scope with 10x probe.

> After power-on, the AD5781 must be configured for normal
operating mode before programming the output. To do this, the
control register must be programmed. The DAC is removed
from tristate by clearing the DACTRI bit, and the output clamp
is removed by clearing the OPGND bit. At this point, the output
goes to VREFN unless an alternative value is first programmed to
the DAC register.

## Initial accuracy

1LSB is 10V / 2^18 = 38μV. At 1V/Oct, 12 tones per octave, 100 cents per tone, 1 Cent is 833μV so 1 LSB is about 1/20 cent.

**INL** is ±2 (typ) ±4 (max) LSB for worst (A) grade = 15ppm = ±153μV max (!!)

**DNL** at 5V vref is ±0.5 (typ) ±1.0 (max) LSB = 3.6ppm.

Linearity Error **Long-Term Stability** is 0.03 LSB after 1k hours at 100C.

**Gain error** (away from output voltage extremes) is 0.4ppm (typ) 20ppm FSR (max) = 2μV (typ) 100μV (max) with a gain error TC of ±0.04ppm FSR/C.

Poorly documented LIN COMP register applies third-order residual non-linearity compensation. See [EEBlog post on AD6791 LIN COMP](https://www.eevblog.com/forum/metrology/ad5791-based-dac-platform/msg4938403/#msg4938403)

> The specifications in this data sheet are obtained with LIN COMP = 0000 for reference spans up to and including 10 V and with LIN COMP = 1100 for a reference span of 20 V. The default value of the LIN COMP bits is 0000.

Maybe check the linear vs. R2R segmentation, like [this EEVBlog post](https://www.eevblog.com/forum/metrology/ad5791-based-dac-platform/msg4610125/#msg4610125)?

## Noise

**Spectral noise** 7.5 nV/√Hz at 1kHz, 10kHz and 100kHz.  Dwarfed by the Vref which is 10x noisier at 95 nV/√Hz even with the capacitor. **Flicker noise** 1.1 μV p-p, half that of the Vref.

Board shields SPI lines with digital ground.

## Line regulation

±1 LSB for  ΔVdd ±10%, nothing specal needed for Vdd regulation here but ensure supply is low noise.

Needs Schottky diode across power rails, see datasheet fig. 50.

## Load regulation

DAC output impedance is 3.4k for AD5781ARUZ so buffer with an op-amp on the output.

## Vref connection

See [The 20-Bit DAC Is the Easiest Part of a 1-ppm-Accurate Precision Voltage Source](https://www.analog.com/en/analog-dialogue/articles/20-bit-dac-and-accurate-precision-voltage-source.html) for general guidance (with the 20 bit version of this DAC, the AD5791); also
[AN-86: A Standards Lab Grade 20-Bit DAC with 0.1ppm/°C Drift](https://www.analog.com/en/resources/app-notes/an-86f.html)

A pair of op-amps (one non inverting for VrefP, one inverting for VrefN) then, per pitch DAC, a pair of unity gain buffers for (required) kelvin connections. DAC Vref input impedance is 5/6.6/? kΩ at midscale, but code dependent.

Low input bias is _specifically needed_ to achieve the rated performance.

AD5781 datasheet uses AD8676 (AD8676BRZ $6.89/1) dual op-amp for Vref buffers, which is 12uV typ 50uV max Vos, Ibias **±2 nA max** @25C, very low noise rail-to-rail. R/R does not seem to be needed for a 5V output on ±12 or ±9.5 rails.

_OPA2197ID_ (OPA2197ID $2.97/1) dual is 25uV typ 100uV max Vos, 5nA Ibias so twice as bad at half the price. (Quad OPA4197ID, got 10 May 2020)

**OPA2186D** another (OPA2186DR $2.22/10 newer, more available; SOIC-8) option. 1μV/10μV Vos as it is chopper stabilized. 4.8 max nA Ibias over temp, 55pA @25C. Check **slew rate 0.35 V/μs** is ok for slew limiter, if used. Quad version has _4x worse Vos_ so use duals. The _maximum_ power supply voltage for the OPAx186 is 24 V (±12 V). (Abs Max 26V). So running on ±9.5V looks good.

But the chopper op-amp was a PITA with the earlier Vref design, while the non-chopper OPA2192 worked great in the new Vref design. So:

**OPA2192** ($4.63/10) Vos ±8μV typ, ±50μV max, drift ±0.1 typ, ±0.5 max μV/°C. Input bias ±5 pA typ, **±20 pA** max @25C. So much better than the recommended AD5781.

OPA4187IPW (1μV/10μV TSSOP-14 $5.60/10 in stock) quad a bit expensive

## Output conditioning

With a ±5V ref and an output buffer in the "Unity Gain configuration" from the data sheet Fig. 51 this gives ±5V output (10 octaves) which includes Note-ON voltage, global pitchbend, and per-note pitchbend. Note that this does not cover the [full MIDI note range](./MIDI.md) of 128 notes = 10.66 octaves. Not an issue in practice.

Op-amps here need a max Vos of 38μV (1LSB at 18bits), preferably better. Input bias current however is not as crucial here (unless Vref buffers and output buffers use the same quad.) 

AD8675 is the Analog Devices recommendation (mouser only has the less good A grade).

OPA197 an alternative. Or use a quad OPA4197 for both vref buffers, output, and one left over for slew limit if desired (not a good idea for pitch) or to drive two outputs. All hinges on unstable availability and huge lead times!

Initial plan was **OPA2186D** same as v0.1 Vref drivers, with Vos = ±1μV typ ±10 µV max. Given how the chopper amp destabilized the voltage reference and required extensive resistive decoupling from power supplies, inputs and outputs it seems better to go for a non-chopper design.

**OPA2192** as used in v0.2 voltage reference, with Vos ±8μV typ, ±50μV max, drift ±0.1 typ, ±0.5 max μV/°C still seems good so try it here too.

Because the OPA2186D has a low input bias of ±4.8nA the Fig. 52 Output Amplifier in Unity Gain with Amplifier Input Bias Current Compensation was not used on the first board revision. Also there are [reports](https://www.eevblog.com/forum/metrology/ad5791-based-dac-platform/msg4965718/#msg4965718) that this compensation has little effect:

> In the last two versions of AD5791-based multifunction calibrators, I have included support for both DAC modes (Gain 1x with Ib compensation and Gain 2x) to implement unipolar and bipolar ranges. During the tests, I did not find any measurable differences. Even the INL curve matches up to 0.1 ppm.

Note:

> This unity-gain difference amplifier (equal resistors) causes the input difference voltage (V2-V1) to be impressed on R5; the resulting current flows to the load. The offset voltage, however, is applied directly to the noninverting input and is amplified by +2 – like a noninverting amplifier (G = 1 + R2/R1). Thus, a 10-mV offset voltage creates 20 mV across R5, producing a 20mA output current offset. A -10-mV offset would create a -20-mA output current (current sinking from the load).

Should the output buffer be able to drive a capacitive load (so, two resistors and cap in feedback loop). Chosen values (4k7, 3n3) give a 10kHz cuttoff which seems ample.

DAC has a 3k4 output resistance so the feedback resistance [should be the same](https://eng.libretexts.org/Bookshelves/Electrical_Engineering/Electronics/Operational_Amplifiers_and_Linear_Integrated_Circuits_-_Theory_and_Application_(Fiore)/05%3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) to reduce the effect of the input bias current. It is now 3k4, although the input bias of this op-amp is very low.

capacitive load circuits

[Understanding stabilization capacitors](https://northcoastsynthesis.com/news/understanding-stabilization-capacitors/)

[The Tale Of The 1 kΩ Output Resistor](https://www.njohnson.co.uk/index.php?menu=2&submenu=2&subsubmenu=16)

### Simulation results

Initial simulation was a 1nF load (guess at cable capacitance) in parallel with 100k (for the input module). Pulse input was

`y1=0 y2=5 td=1m tr=100n tf=1u tw=1 per=1`

where the pulse starts at 1ms (td), tr is the rise time, tf is the fall time (of less interest here) and pw is the pulse width.

With 2.2nF, overshoot on a 5V step is 95mV, without ringing, and falling to desired output level after 50 μs.

2.2nF

With 4.7nF, overshoot on a 5V step is 40mV, without ringing, and falling to desired output level after 120 μs.

4.7nF

However the typical eurorack patch cable is around 100pF per meter, so the load was reduced to 200pF.

With 4.7nF, overshoot on a 5V step is then 54mV, with some ringing, and falling to desired output level after 260 μs.

4.7nF with 200pF load

Even increasing the compensation cap to 100nF (!) still leaves the offshoot at 52mV, and slowly rising to correct output level after 920 μs. So at this point it is doing more harm than good in terms of settling time.

Reducing now to 1.0nF, overshoot is 116mv!

1.0nF with 200pF load

I also wonder if the simulation, with an high slew rate step, is no longer accurately representing the actual rise time of the DAC; the datasheet slew rate is 50V/μs (Unbuffered output, 10 MΩ||20 pF load) so for a 5V step thae rise time would be 100ns which is what the simulation shows.

## Schematic

Should CLR and RESET have been tied high? YES oops v.01 board does not, fixed in v.02:

> If the RESET pin is not used, it should be hardwired to IOVCC.

Diode is between V<sub>DD</sub> (positive analog) and **V<sub>CC</sub>** ie positive digital power
**not** V<sub>DD</sub> (positive analog) and **V<sub>SS</sub>** negative analog power. Broken in V0.2 board, fixed in V0.3

I guess that gave the opportunity to port from Eagle to KiCad at the same time.

Schematic ([Schematic in PDF](./pitchdac-schematic-v04.pdf))

Connecting DGND and AGND, see TI white paper [Grounding in mixed-signal systems demystified, Part 1](https://www.ti.com/lit/an/slyt499/slyt499.pdf)

## Board

Separate digital and analog ground planes.

- Board v0.1 [ordered at OSH Park](https://oshpark.com/shared_projects/gQY5hg1l) 31 Mar 2023. GOT.
- Board v0.2 with missing traces from CLR and RESET, [ordered at OSH Park](https://oshpark.com/shared_projects/UpIebEcc) 15 Oct 2023. GOT.
- Board v0.3 [ordered at OSH Park](https://oshpark.com/projects/GQX9tlid/view_design) 13 June 2025.
- Board v0.4 relocates diode, adds 0R between DGND and AGND

3d-front
3d-back

> We detected a 2 layer board of 2.36 x 1.17 inches (59.9 x 29.7mm)
> 3 boards will cost $13.75

osh
osh back

### Jacks board

Spacing of the two pitch DC boards may vary due to tolerances on trimming the upper and lower connectors from the [Vref board](./voltage-ref-LT1236.md) and so the front panel jacks board should make connections using drilled slots rather than round holes. These re natively supported in KiCad (unlike Eagle) and supported by OSH Park ([details](https://docs.oshpark.com/submitting-orders/slots/)).

### Sizing

headers

Stack of PitchDac | pin socket | double pin header (on vref) | pin socket | PitchDAC is way too big: 27.8mm across the outer PitchDAC PCBs. Space on [current mockup](./panel-layout.svg) is 18.7mm!

no headers

With connectors directly soldered together much slimmer, 12.8mm across the outer PitchDAC PCBs. But then very difficult to modify or repair once assembled. Would need to be soldered in place even for testing.

Maybe [low-profile headers](https://protosupplies.com/product/header-set-low-profile-1x24/) like on the ProtoSupplies Teensy boards **ordered 14 July 2025**, and cut-down double-ended pin headers?

## BOM (per DAC board, need 2)

### DAC

(1) Analog Devices [AD5781ARUZ](https://www.mouser.com/ProductDetail/Analog-Devices/AD5781ARUZ) $40.96  = **$40.96 GOT** has 1 already, got another 1 for now. Might be enough if no errors :) **GOT 1 more 8 Feb 2026**

### Stabilization film caps

(2) Cornell Dubilier FCP0805H101J-J1 100pF 0805 $0.526/10 = **$5.26 GOT** [Mouser](https://www.mouser.com/ProductDetail/Cornell-Dubilier-CDE/FCP0805H101J-J1)

**need to get the stabilization cap value finalized!**

### Bulk ceramic caps

(7) Samsung CL31B106KAHNFNE  25V 10μF X7R 10% 1206 ceramic $0.094/10 = **$1.88 GOT**  [Mouser](https://www.mouser.com/ProductDetail/Samsung-Electro-Mechanics/CL31B106KAHNFNE) get 20

### Decoupling and NR caps

(7) Kemet C1206C104K3GEC7210 25V 100nF C0G 1206 ceramics $0.051/100 = **$5.10 GOT**

### Resistors

(2) Susumu [RR1220P-472-D](https://www.mouser.com/ProductDetail/Susumu/RR1220P-472-D) 0805 4k7 0.5% 25ppm $0.13/10 = **$1.30 GOT** 

(2) Susumu [RR1220P-221-D](https://www.mouser.com/ProductDetail/Susumu/RR1220P-221-D) 0805 220R 0.5% 25ppm $0.127/10 = **$1.27 GOT** changed to 47R for assembly of first board

(1) Any 0805 10k will do for the pullup. Susumu RR1220P-103-D **GOT**

### Op-Amps

(2) TI [~~OPA2186DR~~](https://www.mouser.com/ProductDetail/Texas-Instruments/OPA2186DR) $2.22/10 = **$22.20 GOT**

but no those choppers are a _pain in the ass,_ so

(2) TI [OPA2192IDR](https://www.mouser.com/ProductDetail/Texas-Instruments/OPA2192IDR?) SOIC-8 $4.63/10 = **$46.30** ordered 8 Dec 2023

### Schottky diode

(1) Kyocera [SD0805S040S0R5](https://www.mouser.com/ProductDetail/KYOCERA-AVX/SD0805S040S0R5) 0805 40V $0.44/1 = **$1.32 GOT 4**

## Work Plan

- [x] Have two DACs.
- [ ] Check slew rate and corner freq for 10k, 220R, 33pF; breadboard with TL074 to check. (Nope, oscilloscope busted)
- [x] Get OPA2186DR, other components for one board
- [x] Get OPA2192IDR
- [x] Lay out v0.1 board, fab
- [x] Lay out v0.2 board
- [x] Lay out v0.3 board in KiCad (!)
- [x] Fab v0.2 board and get stencil, too
- [x] Fab v0.3 board and get stencil, too
- [x] Order low-profile headers to reduce stacked height
- [ ] SPI:
  - [ ] Breadboard a known working SPI device such as an oled display
  - [ ] Use scope to capture the SPI clock (without interpretation)
  - [ ] Use scope with SPI decoding to capture cs, clock and data
  - [ ] Capture SPI from pitchdac, at same clock speed
- [ ] Lay out jacks board for panel, to check connector spacing for DAC boards
- [ ] Build and test one DAC board with (previously tested) VREF board.
- [ ] If all okay, order 2 more DAC and components for other board. Else refine, redo board.

## Build

on hotplate

Initial attempt on MHP50 hotplate discouraging. Plate is too small, required shifting the board with tweezers during melt phase.

right
right

Too thick solder paste so some bridges on the TSSOP-20 DAC, which were fixed with solder wick then checked with multimeter. Diode did not solder, so fixed with an iron.

built

Completed board with through-hole connectors added.

Initial test gave no output from DAC. Re-checked for shorts. Realised there was no connection from DGND to AGND so added a bodge wire. Re-did breadboard wiring to PitchDC board, added 100R resistors in MOSI and SCLK. Reflowed DAC, which may have been a bad idea (perhaps caused a short in the solder?).

Retest showed rapidly climbing current consumption, up past 100mA so switched off/ No obvious short on digital pins, hard to access analog pins. Next step is to build a second bord for testing.

built 2

Completed board #2 draws 12mA on +12 and -12 (power board, one PitchDAC, one Vref board). Diode did not reflow, testing without for now. DAC pins look cleaner than board #1,

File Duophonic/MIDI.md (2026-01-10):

# MIDI implementation

## Libraries

Low level, collect data and dispatch to handlers

- Francois Best [MIDI Library](https://www.pjrc.com/teensy/td_libs_MIDI.html) (version 5 on [GitHub](https://github.com/FortySevenEffects/arduino_midi_library) but 4 may be simpler to use here)
- Paul Stoffregen USB MIDI Host using [USBHost_t36](https://github.com/PaulStoffregen/USBHost_t36)
- Teensyduino [USB MIDI](https://www.pjrc.com/teensy/td_midi.html)

Note that [Arduino USBMIDI](https://github.com/lathoub/Arduino-USBMIDI) claims to support Teensy 4.1 but does not support USB Host.

Note [bug in MIDI.hpp re system common messages](https://forum.pjrc.com/threads/73743-midi-tune-select-problem?p=333274&viewfull=1#post333274)

Detect devices connected to USB host:

> myusb.task() is what polls for a connected USB device.

High level, implement MIDI 1.0, HRV and and MPE specifications

- My own library.

Doesn't yet exist as a library but verious sketches implement parts.

Voice allocation is not in that library, module specific.

Useful [addition for usbMIDI to control Note On 0 handling](https://forum.pjrc.com/index.php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) could also be added to usb host MIDI.

## Note range

Range of [musical frequencies for MIDI notes](https://www.inspiredacoustics.com/en/MIDI_note_numbers_and_center_frequencies) assuming :

- Equal temperament tuning
- MIDI 60 is C4, middle C (thus MIDI 69 is A4, concert A)
- A4 is 440Hz
- C4 is by default 0V, Doepfer Eurorack standard (thus tuning to 440Hz needs 0.75V)
- pitch CV range +5V to -5V
- DAC verification should avoid the note extremes to minimize linearity error
- With pitchbend, note numbers are non-integer

Formula

Voltage = 0.75 + (n - 69)/12

| MIDI 	| Name 	| Voltage  	| Frequency 	|
|---	|---	|---	|---	|
| _127_  	| G9 	| 	| 12,543.85 	|
| _120_  	| C9 	| 5V 	| 8372.02 	|
| _119_  	| B8 	| 4 11/12V 	| 7902.13 	|
| _117_  	| **A8** 	| 4.75V 	| 7040.00 	|
| 108  	| C8 	| 4V 	| 4186.01 	|
| 105  	| **A7** 	| 3.75V 	| 3520.00 	|
| 93 	| **A6** 	| 2.75V 	| 1760.00 	|
| 81 	| **A5** 	| 1.75V 	| 880.00 	|
| 69 	| **A4** 	| 0.75V 	| 440.00 	|
| 60 	| C4 	| 0V 	| 261.63 	|
| 57 	| **A3** 	| -0.25V 	| 220.00 	|
| 45 	| **A2** 	| -1.25V 	| 110.00 	|
| 36 	| C2 	| -2V 	| 65.41 	|
| _33_ 	| **A1** 	| -2.25V 	| 55.00 	|
| _24_ 	| C1 	| -3V 	| 32.70 	|
| _21_ 	| **A0** 	| -3.25V 	| 27.50 	|
| _16_ 	| E0 	| 	| 20.60 	|
| _9_ 	| **A-1** | -4.25V | 16.35 	|
| _0_ | C-2 |  -5V | 8.18 |

Frequencies for the A notes are _exact_, others are rounded.
MIDI notes outside 88-key piano range are in italics.

Note that:

- A8 is a convenient 4.750 V corresponding to an exact integer frequency 7040 Hz
- C8 is a convenient 4v for testing, and also corresponds to the _highest_ note on an 88-key piano
- C2 is -2V and also the _lowest_ note on an 88-key piano
- A2 is a convenient -2.250 V corresponding to an exact integer frequency 55 Hz
- E0 is the lower limit of audibility
- A-1 is -4.25V and exact 16.350 Hz, useful for auto tuning
- MIDI notes 121 to 127 are unreachable with a ±5V DAC swing if the C4 = 0V Doepfer tuning is maintained. Also not musically useful notes.
- MIDI notes 0 to 15 inaudible, so not musically useful

## Duophony

- [Duophony on SoS](https://www.soundonsound.com/techniques/duophony)

## Key tracking

- [Keeping track of held MIDI notes?](https://forum.pjrc.com/index.php?threads/keeping-track-of-held-midi-notes.77191/)

## Note priority

Dispatching key events to the two channels: first one is lowest note priority, second channel is highest note priority. So can be used as one of two popular monosynth styles, as well as duophonic.

- [Priorities & Triggers](https://www.soundonsound.com/techniques/priorities-triggers)

## Smoothing and update rate

DIN MIDI is 31,250 baud with 10 bits (1 start, 8 data, 1 stop, no parity) per byte transferred = 3,125 bytes/sec. 3 bytes per MIDI CC means max update rate (for a single CC using all the bandwidth) is ~1000 CC per second.

Interesting quote [from Haken MPE+](https://www.hakenaudio.com/mpe):

> Data smoothing is not a bad thing for the synthesizer to do — in fact, the Sampling Theorem tells us that smoothing is always necessary to avoid aliasing!  Aliasing is not a problem unique to audio sample streams, but also X,Y,Z control streams encoded in Midi. The common sample rates for audio are 44.1, 48, or 96 kHz.  The effective sample rate for the most popular MPE controllers’  Z data is ~25 Hz, and ~500 Hz for the Continuum Fingerboard. MPE+ lets the controller specify the best amount of smoothing to avoid update noise (aka zipper noise or aliasing) but still retain the finger motion information in the data.  [Clarification: The Continuum internally has an effective sample rate of ~3 kHz for Z; this data is processed to create the optimized ~500 Hz effective sample rate control stream for Midi transmission.]

and, from the [Sound on Sound review of the Expressive-E Osmose](https://www.soundonsound.com/reviews/expressive-e-osmose):

> The Osmose’s internal control scheme is not based on MPE MIDI but an extension of it termed MPE+ that improves resolution in the domains of time (for very quick response) and magnitude (for very smooth). Interestingly, it does away with the concept of key velocity (or, in MPE terms, Strike Value) completely, and instead derives note onset information from ‘attack trajectory’, a much more precise assessment of key travel over time that can take into account key dip as well as rate and acceleration.

> However, the Osmose will function perfectly well as an MPE or basic MIDI controller. It does that by deriving velocity data (or MPE Strike Value) from the initial key touch, and various types of channel or polyphonic pressure from the aftertouch. An ‘Ext MIDI’ mode, with a dedicated button, toggles the Osmose’s interface entirely over to MIDI control functions. And then a handful of dedicated MIDI control profiles are provided, including a full MPE implementation, ‘classic keyboard’ (which turns off all expressive features except velocity and channel aftertouch), and ‘poly aftertouch’ (which gives good compatibility with synths like the Oberheim OB‑6 that offer this response, but not full MPE). The point in the key dip at which notes trigger varies between modes: higher/earlier for MPE, and lower/later for ‘classic keyboard’. That’s some real sophistication, and very nicely considered.

See also the section [**14-bit Controllers are Flawed**](https://www.hakenaudio.com/mpe) and [Control Voltage Converter (CVC) for Analog Synthesizers](https://www.hakenaudio.com/voltage-converter) which has W,X,Y,Z outputs on four channels (using I2C, oddly), and similar [Evaton Technologies µCVC](https://www.evatontechnologies.com/mcvc).

Useful discussion on [Osmose, CC87, CC74 for 14-bit output](https://community.vcvrack.com/t/osmose-expressive-e/19100/9)

[MIDI BigBuffer to avoid losing data with high throughput](https://forum.pjrc.com/threads/70227-USBhost_t36-MIDI-losing-midi-note-on-off-events-(Teensy-3-6)-during-modwheel-change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)

[class MIDIDevice_BigBuffer ](https://github.com/PaulStoffregen/USBHost_t36/blob/b6f94f7605b3f6cb57a10e41cab51b25b47f7736/USBHost_t36.h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) required for 480 speed.

## Tunings, and Microtuning

- [MICROTUNING VIRTUAL AND ELECTRONIC HARDWARE INSTRUMENTS: AN OVERVIEW OF FORMATS AND METHODS FOR USING ALTERNATIVE INTONATION SYSTEMS](https://midi.org/microtuning-and-alternative-intonation-systems)

> There are countless other such examples of historical and contemporary musical instrument intonation systems that would be able to easily illustrate the glaring shortcomings of being restricted to only 12 notes repeating at the 2/1. For musicians and composers to be able to encompass the full range of expression and compositional possibilities of using alternative intonation systems in their music – including, but not limited to, 12 Note Octave Repeating Microtunings – it is advised to support those visionary developers who have implemented full-keyboard microtuning in their instruments. With correctly implemented full-keyboard microtuning functionality, there is no compromise in the way that one may microtune their hardware or virtual instruments.

> Virtual instruments that can more easily achieve high-precision full-controller microtuning are those where developers have implemented the use of either the **TUN** or **MTS (MIDI Tuning Standard)** microtuning formats, which enable saving all of the microtuning mapping information into a single tuning data file that may be loaded directly into the instruments, or in the case of MTS, also be transmitted from the timeline of DAWs that allow transmitting SYSEX, such as for example REAPER and Bitwig.

- [How to create a .tun file in Scala](https://sevish.com/2014/how-to-create-a-tun-file-in-scala/) also describes mts
- [MIDI tuning frequency data format](https://en.wikipedia.org/wiki/MIDI_tuning_standard#Frequency_Data_Format)

TUN (.tun) is textual, one line for each of the 128 notes, while MTS (.mid) is binary, 3 bytes per note.

- [Mapping microtonal scales to a MIDI keyboard in Scala](https://sevish.com/2017/mapping-microtonal-scales-keyboard-scala/)
- [re-tuned - same melodies in different tunings](https://sevish.bandcamp.com/album/re-tuned)
- [scale workshop](https://sevish.com/scaleworkshop/?version=2.5.7) browser-based scale generator
- [Intro to Microtonality](https://theproaudiofiles.com/microtones/)
- [My Idiosyncratic Reasons for Using Just Intonation](https://www.kylegann.com/JIreasons.html)
- Book [The Arithmetic of Listening](https://www.press.uillinois.edu/books/?id=p084416)

## Combining data sources

The SoS [review of the Arturia Polybrute 12](https://www.soundonsound.com/reviews/arturia-polybrute-12) mentions Pluck (short AD) and Touch (key position modified by ADSR) to control filter and VCA.

> The third mode is FullTouch Env > AT, and this is the one that’s going to cause confusion, not least because the manual doesn’t describe it fully. (A lack of detail was a fault with the original PolyBrute manual, too.) Having spent hours trying to work out what was happening, I admitted defeat and contacted Arturia. It turns out that, when designing sounds to take advantage of FullTouch AT and FullTouch AT > Z, the developers found that they were leaving the filter and amplifier open so that they could use FullTouch to control other aspects of note development, timbre and modulation. So they designed a mode in which the VCF and VCA envelopes no longer act as ADSR contour generators, but are replaced by modulation values that are determined by the key velocity and vertical position. Having decided upon the basis of the system, they then decided to make each of those values the sum of two new signals. The first of these is called Pluck, and this is a simple AD transient. Its fastest attack rate is quoted as below 4ms, but it can be lengthened a little by increasing the value of the attack fader of the appropriate envelope generator. The decay rate is then controlled by the decay fader, and the maximum amplitude of the transient is controlled by the velocity fader, although there’s a lower velocity threshold that helps to ensure that you don’t generate a Pluck by accident. The second signal is called Touch, which is a contour determined by the position of the key at any given moment. However, the ADSR faders in each of the VCF and VCA envelope panes also affect this. The attack and decay faders determine the slew rate when the key moves down or up, respectively. The Sustain value is more complex. When positioned below 50 percent, the generated values are lower than they would otherwise be, lowering the relative amplitude of the Touch and emphasising the Pluck to create, well, plucked sounds. But when the Sustain is positioned above 50 percent, the Touch signal remains high. This was implemented so that the VCA can be kept open even while a key is being moved up and down to control the filter. The release fader then controls the release time as you would expect. Finally, the aftertouch sensor at the bottom of the key’s travel is again active, so you can still lean into a note and generate Poly‑AT in addition to all of the above.

## Reading MIDI data

Setup:
```
#include <USBHost_t36.h>
#include <MIDI.h>

USBHost thisUSB;
USBHub hub1(thisUSB);
MIDIDevice_BigBuffer usbhostMIDI(thisUSB);

MIDI_CREATE_DEFAULT_INSTANCE();
```

And then in the loop:
```
    MIDI.read();
    usbMIDI.read();
    thisUSB.Task();
    usbhostMIDI.read();
```

## Host port current

> The USB host port has a [TDP3S014](https://www.ti.com/product/TPD3S014) current limit chip. 
> So the maximum current is either the limit this chip imposes (~850mA), 
> or the remaining amount of current available from whatever 
> power source is powering Teensy 4.1. <br>
> [PaulStoffregen](https://forum.pjrc.com/index.php?threads/usb-host-teensy-4-1-current-limit.76302/#post-353611)

This also provides D+ D- ESD protection.

## Controllers

### Roli Seaboard Rise 1

Roli

The three sliders are by default (in MPE mode) set to CC 107, 109, 111 while the touchpad is set to x-axis CC 113, y-axis CC 114. However they seem to generate SysEx F0 instead.

```
 TIMESTAMP IN PORT STATUS DATA1 DATA2 CHAN NOTE EVENT               
 Opened MIDI Input
 Closed MIDI Input
 Opened MIDI Input
 00000BE7   2  --     F0  Buffer:     9 Bytes   System Exclusive      
 SYSX: F0 00 21 10 78 3D 17 06 F7
 00000C0F   2  --     F0  Buffer:     9 Bytes   System Exclusive      
 SYSX: F0 00 21 10 78 3D 17 0A F7
 00000C37   2  --     F0  Buffer:     9 Bytes   System Exclusive      
 SYSX: F0 00 21 10 78 3D 17 1C F7
 00000C60   2  --     F0  Buffer:     9 Bytes   System Exclusive      
 SYSX: F0 00 21 10 78 3D 17 27 F7
```

And for keys (remembering in MPE 74 Brightness is used for front-back Slide)

```
 TIMESTAMP IN PORT STATUS DATA1 DATA2 CHAN NOTE EVENT               
 Opened MIDI Input
 0005534E   2  --     B1    4A    08    2  ---  CC: Brightness        
 0005534E   2  --     E1    00    40    2  ---  Pitch Bend            
 0005534E   2  --     91    39    1E    2  A  3 Note On               
 00055358   2  --     B1    4A    06    2  ---  CC: Brightness        
 0005535B   2  --     E1    00    40    2  ---  Pitch Bend            
 00055362   2  --     D1    37    --    2  ---  Channel Aft           
 00055369   2  --     D1    39    --    2  ---  Channel Aft           
 00055370   2  --     D1    3B    --    2  ---  Channel Aft           
 00055377   2  --     D1    3D    --    2  ---  Channel Aft           
 0005537E   2  --     D1    3F    --    2  ---  Channel Aft           
 00055384   2  --     D1    41    --    2  ---  Channel Aft           
 0005538B   2  --     D1    43    --    2  ---  Channel Aft           
 0005538B   2  --     B1    4A    05    2  ---  CC: Brightness        
 00055392   2  --     D1    45    --    2  ---  Channel Aft           
 00055399   2  --     D1    47    --    2  ---  Channel Aft           
 000553A0   2  --     D1    49    --    2  ---  Channel Aft           
 000553A5   2  --     B1    4A    04    2  ---  CC: Brightness        
 000553A7   2  --     D1    4B    --    2  ---  Channel Aft           
 000553AE   2  --     D1    4D    --    2  ---  Channel Aft           
 000553B5   2  --     D1    4F    --    2  ---  Channel Aft           
 000553BC   2  --     D1    51    --    2  ---  Channel Aft           
 000553C3   2  --     D1    53    --    2  ---  Channel Aft           
 000553CA   2  --     D1    55    --    2  ---  Channel Aft           
 000553D1   2  --     D1    57    --    2  ---  Channel Aft           
 000553D8   2  --     D1    59    --    2  ---  Channel Aft           
 000553DF   2  --     D1    5B    --    2  ---  Channel Aft           
 000553E7   2  --     D1    5D    --    2  ---  Channel Aft           
 000553ED   2  --     D1    5F    --    2  ---  Channel Aft           
 000553F3   2  --     B1    4A    05    2  ---  CC: Brightness        
 000553FB   2  --     D1    60    --    2  ---  Channel Aft           
 00055409   2  --     D1    61    --    2  ---  Channel Aft           
 00055418   2  --     D1    62    --    2  ---  Channel Aft           
 0005541B   2  --     B1    4A    06    2  ---  CC: Brightness        
 000554B8   2  --     D1    61    --    2  ---  Channel Aft           
 000554BF   2  --     D1    60    --    2  ---  Channel Aft           
 000554C6   2  --     D1    5E    --    2  ---  Channel Aft           
 000554CD   2  --     D1    5D    --    2  ---  Channel Aft           
 000554D3   2  --     E1    10    40    2  ---  Pitch Bend            
 000554D4   2  --     D1    5F    --    2  ---  Channel Aft           
 000554DC   2  --     D1    61    --    2  ---  Channel Aft           
 000554DE   2  --     B1    4A    07    2  ---  CC: Brightness        
 000554E1   2  --     E1    24    40    2  ---  Pitch Bend            
 000554E3   2  --     D1    63    --    2  ---  Channel Aft           
 000554EA   2  --     B1    4A    05    2  ---  CC: Brightness        
 000554EE   2  --     E1    41    40    2  ---  Pitch Bend            
 000554F1   2  --     D1    61    --    2  ---  Channel Aft           
 000554FB   2  --     E1    51    40    2  ---  Pitch Bend            
 000554FF   2  --     D1    5F    --    2  ---  Channel Aft           
 00055505   2  --     D1    5D    --    2  ---  Channel Aft           
 00055507   2  --     E1    0E    41    2  ---  Pitch Bend            
 0005550C   2  --     D1    5F    --    2  ---  Channel Aft           
 00055512   2  --     B1    4A    04    2  ---  CC: Brightness        
 00055514   2  --     D1    61    --    2  ---  Channel Aft           
 00055515   2  --     E1    1D    41    2  ---  Pitch Bend            
 0005551B   2  --     D1    63    --    2  ---  Channel Aft           
 00055522   2  --     D1    65    --    2  ---  Channel Aft           
 00055522   2  --     E1    2A    41    2  ---  Pitch Bend            
 00055529   2  --     D1    66    --    2  ---  Channel Aft           
 0005552C   2  --     B1    4A    06    2  ---  CC: Brightness        
 0005552F   2  --     E1    39    41    2  ---  Pitch Bend            
 00055530   2  --     D1    64    --    2  ---  Channel Aft           
 00055537   2  --     D1    62    --    2  ---  Channel Aft           
 0005553B   2  --     E1    7D    41    2  ---  Pitch Bend            
 0005553D   2  --     D1    60    --    2  ---  Channel Aft           
 00055544   2  --     D1    62    --    2  ---  Channel Aft           
 00055545   2  --     B1    4A    03    2  ---  CC: Brightness        
 00055548   2  --     E1    4D    42    2  ---  Pitch Bend            
 0005554B   2  --     D1    64    --    2  ---  Channel Aft           
 00055552   2  --     D1    66    --    2  ---  Channel Aft           
 00055555   2  --     E1    54    42    2  ---  Pitch Bend            
 00055559   2  --     D1    68    --    2  ---  Channel Aft           
 0005555F   2  --     B1    4A    04    2  ---  CC: Brightness        
 00055560   2  --     D1    66    --    2  ---  Channel Aft           
 00055562   2  --     E1    6C    42    2  ---  Pitch Bend            
 00055567   2  --     D1    68    --    2  ---  Channel Aft           
 0005556D   2  --     B1    4A    05    2  ---  CC: Brightness        
 0005556F   2  --     D1    66    --    2  ---  Channel Aft           
 00055570   2  --     E1    0C    43    2  ---  Pitch Bend            
 00055576   2  --     D1    64    --    2  ---  Channel Aft           
 00055579   2  --     B1    4A    04    2  ---  CC: Brightness        
 0005557C   2  --     D1    66    --    2  ---  Channel Aft           
 0005557C   2  --     E1    26    43    2  ---  Pitch Bend            
 00055583   2  --     D1    68    --    2  ---  Channel Aft           
 00055589   2  --     E1    2C    43    2  ---  Pitch Bend            
 0005558A   2  --     D1    66    --    2  ---  Channel Aft           
 00055591   2  --     D1    64    --    2  ---  Channel Aft           
 00055593   2  --     B1    4A    08    2  ---  CC: Brightness        
 00055596   2  --     E1    51    43    2  ---  Pitch Bend            
 00055598   2  --     D1    62    --    2  ---  Channel Aft           
 000555A0   2  --     D1    64    --    2  ---  Channel Aft           
 000555A0   2  --     B1    4A    07    2  ---  CC: Brightness        
 000555A3   2  --     E1    71    43    2  ---  Pitch Bend            
 000555A6   2  --     D1    63    --    2  ---  Channel Aft           
 000555AD   2  --     D1    65    --    2  ---  Channel Aft           
 000555AE   2  --     B1    4A    06    2  ---  CC: Brightness        
 000555B0   2  --     E1    7C    43    2  ---  Pitch Bend            
 000555B4   2  --     D1    67    --    2  ---  Channel Aft           
 000555BB   2  --     B1    4A    07    2  ---  CC: Brightness        
 000555BB   2  --     D1    69    --    2  ---  Channel Aft           
 000555BD   2  --     E1    00    44    2  ---  Pitch Bend            
 000555C2   2  --     D1    6B    --    2  ---  Channel Aft           
 000555C7   2  --     B1    4A    08    2  ---  CC: Brightness        
 000555CA   2  --     D1    6D    --    2  ---  Channel Aft           
 000555D0   2  --     D1    6F    --    2  ---  Channel Aft           
 000555D7   2  --     D1    71    --    2  ---  Channel Aft           
 000555DF   2  --     D1    73    --    2  ---  Channel Aft           
 000555E6   2  --     D1    74    --    2  ---  Channel Aft           
 000555ED   2  --     D1    73    --    2  ---  Channel Aft           
 000555EF   2  --     B1    4A    09    2  ---  CC: Brightness        
 00055602   2  --     D1    72    --    2  ---  Channel Aft           
 00055616   2  --     B1    4A    08    2  ---  CC: Brightness        
 0005562C   2  --     D1    71    --    2  ---  Channel Aft           
 00055647   2  --     D1    70    --    2  ---  Channel Aft           
 0005565C   2  --     D1    6F    --    2  ---  Channel Aft           
 00055663   2  --     D1    6E    --    2  ---  Channel Aft           
 0005566A   2  --     D1    6D    --    2  ---  Channel Aft           
 00055671   2  --     D1    6B    --    2  ---  Channel Aft           
 00055678   2  --     D1    69    --    2  ---  Channel Aft           
 0005567D   2  --     B1    4A    07    2  ---  CC: Brightness        
 0005567F   2  --     D1    67    --    2  ---  Channel Aft           
 00055686   2  --     D1    65    --    2  ---  Channel Aft           
 0005568D   2  --     D1    63    --    2  ---  Channel Aft           
 00055694   2  --     D1    61    --    2  ---  Channel Aft           
 00055697   2  --     B1    4A    08    2  ---  CC: Brightness        
 0005569B   2  --     D1    5F    --    2  ---  Channel Aft           
 000556A2   2  --     D1    5D    --    2  ---  Channel Aft           
 000556A9   2  --     D1    5B    --    2  ---  Channel Aft           
 000556B0   2  --     D1    59    --    2  ---  Channel Aft           
 000556B7   2  --     D1    57    --    2  ---  Channel Aft           
 000556BE   2  --     D1    55    --    2  ---  Channel Aft           
 000556C5   2  --     D1    53    --    2  ---  Channel Aft           
 000556CC   2  --     D1    51    --    2  ---  Channel Aft           
 000556D4   2  --     D1    4F    --    2  ---  Channel Aft           
 000556D6   2  --     81    39    39    2  A  3 Note Off              
 0005DB72   2  --     F0  Buffer:     9 Bytes   System Exclusive      
 SYSX: F0 00 21 10 78 3E 28 06 F7
```

The short SysEx seems to be sent periodically as a sort of keep-alive? 00H 21H 10H is registered to ROLI Ltd. Presumably 78 is the [device ID](https://www.2writers.com/eddie/MidiGlossary.htm#DeviceId) and 3E is the Seaboard Rise 1 Model ID? Although the earlier trace had 3D. Thus, 28 06 is the actual data.

- [Starting and ending SysEx](http://midi.teragonaudio.com/tech/midispec/sysex.htm)
- [SysEx IDs](https://midi.org/sysexidtable)

- [Reaper: Using the Seaboard RISE & GRAND with Reaper](https://support.roli.com/support/solutions/articles/36000024635-reaper-using-the-seaboard-rise-grand-with-reaper)
- [OBLVYN’s tips and tricks for Seaboard RISE 2](https://roli.com/stories/oblvyns-tips-and-tricks-for-seaboard-rise-2?mc_cid=4fa71d55d9)

### Polybrute 12 MPE

> I should also mention that, in addition to all of the above, the PolyBrute 12 supports MPE. When sending, all of the aftertouch modes send channel pressure on a per‑note basis, with the FullTouch Env > Z and FullTouch Env > AT modes sending MIDI CC74 as the secondary parameter when a key is pushed into the aftertouch sensor at the bottom of its travel. When receiving, channel aftertouch, poly aftertouch, FullTouch AT and FullTouch AT > Z are each routed to aftertouch and MIDI CC74 on a per‑note basis, while FullTouch Env > AT is routed to the VCF envelope and aftertouch respectively.

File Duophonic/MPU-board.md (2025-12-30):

# Duophonic MPE MIDI - Main MPU board.

## Power

Driven by 5V from [power board](./Power.md), which in turn derives from Eurorack 5V power; generates logic 3V3 Vdd (from Teensy onboard, <250mA). This powers the Teensy itself (up to 100mA), anything driven from 3V3 such as the fader pots and display, and also the 5V for USB host (fuse limited to 500mA minus whatever the Teensy draws).

## MCU choice

MPU needs USB host and hardware floating point, so ~~Teensy 3.6~~ (now discontinued) or **Teensy 4.1**. Both are 3V3-only.

T4.1 ($26.85) is somewhat overpowered but has 480Mbit/s on both USB and Host so potentially lower latency (T3.6 was 480 on Host only). T4.1 has 100mA power consumption at full clock speed (or [68mA if you switch off the orange LED and don't use USB Serial](https://forum.pjrc.com/index.php?threads/the-power-consumption-of-teensys-processor.74442/#post-338912)).

[T4 power consumption](https://forum.pjrc.com/threads/69159-Teensy-4-0-at-24Mhz-still-drawing-100mA-Why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):

| freq  | current |
|---|---|
| 24 |  60mA |
| 150 |  80mA |
| 600 |  100mA  |

Unlikely to save much here, as adequate performance likely requires full or near-full clock speeds.

T3.6 ($29.25) had less memory, has 2 DAC outs (not needed here), power draw unspecified (@@measure it) but less than 4.1. Unobtainable due to NXP parts shortage, was discontinued along with 3.5, 3.2 and LC!

Teensy 4.1

Ensure USB cable plugged into the micro-USB (which leads to the panel-mount USB socket) clears the back of the [Gate LED board](./Gate-LED.md).

Use [ProtoSupplies low-profile headers](https://protosupplies.com/product/header-set-low-profile-1x24/) to connect Teensy 4.1 to the MPU board [as seen here](https://forum.pjrc.com/index.php?threads/construction-suggestions-for-midi-synth-project.77136/#post-359959). Also [available pre-soldered to Teensy 4.1](https://protosupplies.com/product/teensy-4-1-low-profile/) with modifications:

- The VUSB/VIN trace is cut
- An SMD 1A Schottky diode is placed across the VUSB / VIN pads

## MIDI

For software details, see [EuroMPE MIDI](./MIDI.md). This section relates to the input hardware portions on the MPU board, only.

### DIN MIDI

MIDI hardware spec states < 5mA to turn on, < 2μs rise and fall times. Also pin 2 and shield go from not connected, to connected by 100nF caps for RF purposes.

[DIN MIDI](https://www.pjrc.com/teensy/td_libs_MIDI.html) in needs serial input and 6N138 optoisolator with [1k pulldown](https://forum.pjrc.com/threads/54891-MIDI-serial-(DIN)-to-usbMIDI-issues-got-weird-MIDI-messages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)
and [4.7-10 kΩ base-emitter resistor](https://forum.pjrc.com/index.php?threads/midi-5-pin-din-and-trs-swiching-circuit.71303/#post-343562). 

6N139 is lower-current (0.5mA) version of 6N138 (1.6mA).  

Avago Max propogation delay to low: 6N139 25μs, 6N138 10μs. To high, 6N139 60μs, 6N138 35μs.

Fairchild is worse, max propogation delay to low: 6N139 30μs, 6N138 15μs. To high, 6N139 90μs, 6N138 50μs.

Vishay 6N137 max propogation delay to low: 75ns; to high: 75ns.

NO use 6N137, with transistor for level shift and inversion.

> The PC900 suggested by the specification is still a good choice. (Well, it's discontinued, but "PC900" was just Sharp's way of spelling "H11L1", and the H11L1 is still made by many manufacturers.)
> The original 6N137 works only at 5 V. LiteOn's model also works at 3.3 V, while other manufacturers offer a separate 3.3 V variant, for a higher price: HCPL-260L, FOD260L, TLP2962. If you do use the LiteOn 6N137, you should ensure that nobody tries to substitute a different 6N137 model later. [source](https://midi.org/community/midi-hardware/best-optoisolator-for-3-3v#post-2419)

Apparently 6N138 and or H11L1 are too slow per MIDI spec and 6N137 is better. These are not drop-in replacements, the support circuitry differs.

> _(6N137 with)_ An NPN transistor with the collector pulled up to 3.3V. This will also give you a second inversion. The diagram below shows my circuit. The difference is you would have R41 pull up to 3.3V (not isolated 5V as in mine). I would probably make it 10K. C2 is a bypass cap, the datasheet recommends it. Put it as close to pins 8 and 5 as you can. [source](https://forum.pjrc.com/threads/66877-Teensy-4-0-serial-optocoupler-6n137s?p=276314&viewfull=1#post276314)

6N137

- [Opto-couple confusion – 6N137 or 6N138?](https://gr33nonline.wordpress.com/2019/05/15/opto-couple-confusion-6n137-or-6n138/)
- [Teensy 4.0 serial optocoupler 6n137s](https://forum.pjrc.com/threads/66877-Teensy-4-0-serial-optocoupler-6n137s)
- [MIDI Input with 6N137, 6N138, or 6N139](https://www.kieranreck.co.uk/blog/midi-input-with-6n137-6n138-or-6n139)
- [Optocouplers: Defending Your Microcontroller, MIDI, And A Hot Tip For Speed](https://hackaday.com/2018/05/09/optocouplers-defending-your-microcontroller-midi-and-a-hot-tip-for-speed/) especially the comments
- [speeding up 6N138 with a pull-down resistor](https://electronics.stackexchange.com/questions/165255/midi-in-many-circuits/165267#165267)

[Vishay 6N137](https://www.mouser.com/ProductDetail/Vishay-Semiconductors/6N137?qs=xCMk%252BIHWTZMrQz4FyDXhMg%3D%3D) PDIP8, $1.76/1.

[OnSemi 6N137TSVM](https://www.mouser.com/ProductDetail/512-6N137TSVM) ordered 4, **GOT** 6 Aug 2025

### MIDI tester board

Proof of concept, before squeezing onto MPU or MPU-display board.

midi tester schematic

midi tester board

3d

- 00 RX1

### USB MIDI (device)

[USB MIDI](https://www.pjrc.com/teensy/td_midi.html) 

### USB MIDI (host)

 [USB Host MIDI](https://github.com/PaulStoffregen/USBHost_t36).- [Multiple USB MIDI on USBHost](https://forum.pjrc.com/index.php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)

> You need 2 MIDIDevice_BigBuffer. Each MIDI instrument/controller/device you connect gets serviced by 1 of those. To use 2 devices, you need 2 instances.
> You only need 1 USBhost. In fact, you can't use more than 1, because Teensy has only 1 USB host port.

## SPI

Two [SPI](https://www.pjrc.com/teensy/td_libs_SPI.html) outputs for DACs (use SPI0, the faster FIFO one, for the  pitch DAC, because MPE pitchbend messages send a lot of data; use SPI1, the second one, for the octal performance DAC and octal CC DAC) with associated chip selects. Or maybe, if the perf dacs are being updated at high frequency to do smoothing in software, they would be better on the FIFO one.

SPI Display is also on SPI1.

### SPI 0

- 8 CS-Pitch2 (not 9 which is used for FreqCount)
- 10 CS-Pitch1 (any convenient)
- 11 MOSI pitchDACs
- _12 MISO not needed_
- 13 SCLK pitchDAC

The three connectors for SPI 0 are 6-pin whose pinout is (pin1 is square pad)

- GNDD (digital ground)
- SYNC (CS)
- MOSI
- SCLK
- 3V3
- GNDD

### SPI 1

- 26 MOSI1 perfDACs
- _39 MISO1 not needed_
- 27 SCLK1 perfDACs
- 30 CS1-Perf (any convenient)
- 31 CS2-CC  (any convenient) 
- 32 spare
- 33 CS3-Display  (any convenient)
- 34 RST-Display  (any convenient)
- 35 DC-Display (any convenient)

The three connectors for SPI 1 are 8-pin whose pinout is (pin1 is square pad). The two for PerfDAC are:

- GND
- 3V3
- LDAC
- CS
- MOSI
- SCLK
- 3V3
- GND

The one for display differs (still 8 pins):

- GND
- 3V3
- MOSI
- SCLK
- DC
- RST
- CS
- GND

The two for PerfDAC go off-board with ribbon cables while the third, for the [display board](./display-board.md), connects under the Teensy to the display, encoder, buttons board.

[Display](./display.md) also uses two more pins, DC and RST.

Use pull-up resistors on chip selects, per 
[Better SPI Bus Design in 3 Steps](https://www.pjrc.com/better-spi-bus-design-in-3-steps/)

Use anti-ringing resistors at the transmit end of SCLK and MOSI:

> The rising and falling edges of the SPI clock have very high bandwidth, even though the actual clock rate is only 1 MHz. High bandwidth signals on long cables have all sorts of difficult problems when the source impedance isn't matched to the cable's characteristic impedance. The most common solution is to place a resistor in series close to Teensy pin 13 (SCK). Same of MOSI. [Paul Stoffregen](https://forum.pjrc.com/index.php?threads/weird-spi-clock-signal-on-teensey-4-1-pin-13.74169/#post-336114)

Experiment with different resistance values for clock and data lines, and monitor with scope to find optimal values for the cable length in use. Around 50 to 100 ohm seems like a good start.

also (same forum post):

> Bursts of 8 clocks is very common for SPI. The gaps between are software overhead. You can usually minimize this with SPI.transfer(buffer, size) rather than calling SPI.transfer(byte) for each individual byte.

## Mode switch(es) ?

Unclear if MPE/non-MPE is needed. Could be a menu option.

Duophonic/Unison switch at minimum, perhaps Duophonic/Unison/Harmonic or use another switch (plus the encoder) for Harmonic. Double press to reset.

### Non-MPE channel selector ?

Could hide this in a menu; main usage is MPE. Also hide MPE behaviour on split (unlikely) in a setup menu.

## Frequency measurement

Frequency measuring circuitry for auto calibration. How to select channel? Should there be a 440Hz reference output?

> FreqCount: best for 1 kHz to 8 MHz (up to 65 MHz with Teensy 3.0 & 3.1)

> FreqMeasure: best for 0.1 Hz to 1 kHz

Test how low FreqCount can go, or connect both circuits and choose between inputs depending on result.

- 9 [FreqCount](https://www.pjrc.com/teensy/td_libs_FreqCount.html)
- 22 [FreqMeasure](https://www.pjrc.com/teensy/td_libs_FreqMeasure.html)

> (for FreqMeasure) At relatively low frequencies, under 1 kHz, only minimal CPU time is used. However, as the frequency increases, the interrupt demands more CPU time. A hardware low-pass filter is recommended if the input frequency could possibly be much higher than several kHz.

For [FreqMeasureMulti](https://github.com/PaulStoffregen/FreqMeasureMulti) the supported pins on Teensy 4.1 are:

0-9, 22-25, 28, 29, 33, 36, 37, 42-47, 48-50(dups), 51, 52-53 (dups), 54

- 2 FreqMeasureMulti Low (FlexPWM4.2)
- 3 FreqMeasureMulti High (FlexPWM4.2)

Useful frequency range for calibration (see [MIDI](./MIDI.md)) is 16.35Hz to 7040.00Hz, and for oscillator tuning and musical use is 65.41 Hz to 4186.01 Hz.

**Check** pin 7 [conflicts with PWM timers](https://www.pjrc.com/teensy/td_pulse.html), maybe swap the two Gate outs with the two FreqMeasureMulti to avoid.

[fast rising edges](https://forum.pjrc.com/index.php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) perhaps use 74LVC14.

Input signals are audio frequency, Eurorack so typically ±5V but could reach ±12 in theory. Input frequencies will be in the range 16Hz to 7040Hz (musical notes A-1 to A8); this is for a two-voice MIDI-to-CV autotune function.

To avoid any interference with the frequency counter, I was thinking a low pass filter at about 10k would be needed. So I start with a second-order Sallen-Key built around the usual TL072 op amp, running off ±12V. Then to clip the waveform to a safe 0 to 3V3 range, after wondering about more complex solutions with clamping diodes, I came across a super simple solution on EEVBlog involving just a current-limiting input resistor feeding a rail-to rail (input and output) fast recovery op-amp such as OPA2365, running on a unipolar 3V3 supply. (Yes, I know this is basically using an op-amp as a comparator). Lastly to firm up the edges a Schmitt-trigger buffer, here 74LVC2G17, again running on unipolar 3V3. That should give a nice square wave for the frequency counters.

tune-input

## Gate and Trigger outs

Gate logic outputs. Any convenient pins can be used.

- 04 Low Trigger
- 05 High Trigger
- 06 Low Gate
- 07 High Gate

But maybe better to group these closer to the RGB LED outs as they all get routed to the same [Gate-LED](./Gate-LED.md) board.

### RGB LED control

Now using 2 Neopixels, see [Gate LED](./Gate-LED.md). Needs 3V3, GND and any two data pins.

### "Fader" pots

Four 10k low-rise trimmer pots for the four performance outputs. These are read by Teensy ADC and used to digitally fade down the perfDAC values on both channels of that output. Set pinMode to INPUT ([ADC pinmode input check](https://forum.pjrc.com/threads/68621-ADC-voltage-measurements-wrong-and-jumping-on-Teensy-4-1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)).

Current draw for four 10k pots on 3V3 is 13.2 mA which seems fine.

[1nF between wiper and AGND](https://forum.pjrc.com/threads/73545-Solutions-for-Erratic-Potentiometers?p=331814&viewfull=1#post331814) for each pot. But [values are hard to predict](https://forum.pjrc.com/threads/67463-Suitable-op-amp-for-driving-the-teensy4-ADC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) and [20x the value of the 1.5pF ADC internal cap, ie 30-40pf](https://forum.pjrc.com/threads/67463-Suitable-op-amp-for-driving-the-teensy4-ADC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) is also recommended.

_Might_ need low-pass RC filter or op-amp buffer but try the software solution first.

[ResponsiveAnalogRead](https://github.com/dxinteractive/ResponsiveAnalogRead) for the values. 10bit is sufficient. Use [pinMode(pin, INPUT_DISABLE)](https://forum.pjrc.com/threads/69671-Teensy-4-0-4-1-web-pages-need-a-warning-about-INPUT_DISABLE-on-Analog-Inputs)

> pinMode(A0, INPUT_DISABLE);

- 38 (A14)
- 39 (A15)
- 40 (A16)
- 41 (A17)

- [GND vs. AGND on Teensy 4.1 and 3.6](https://forum.pjrc.com/index.php?threads/teensy-4-1-agnd-retired.65599/#post-319809)

So treat the GND between pins 13 and 41/A17 as AGND and the one between Vin and 3V3 as DGND seems prudent.

## Digital outs?

**No** Two pedal logic outputs, if desired. ?Not really needed?

- ?? Pedal 1
- ?? Pedal 2

## Case & Osc temp monitoring (?)

Could need analog ins, or I2C, depending on hardware. Not _at all_ a must-have.

Consider [Stemma QT](https://learn.adafruit.com/introducing-adafruit-stemma-qt/technical-specs) aka JST SH 4-pin:

  1. Black for GND
  2. Red for V+ (3V3 or 5V5)
  3. Blue for SDA
  4. Yellow for SCL

Stemma QT

stemma qt

- [The JST-SH buddies](https://hackaday.com/2022/05/04/the-connector-zoo-i2c-ecosystems/)

## Overall pinout

_Italic_ items are not immediately needed but, if used, need specific pins, so they are reserved in case.
Depending on testing of [PerfDAC](), an additional pin for LDAC might be needed.

pinout

## Schematic

Few components on the board, mainly breaking out to multi-pin connectors to other boards.
The Eurorack power connector is now on a separate [power board](./Power.md).

MPU

[MPU on socket in KiCad](https://forum.kicad.info/t/advise-one-choosing-components/51516/5)

## Board

From the front panel mockup, dimensions are tight: 77mm wide by 39.5mm high. Could expand _one mm_ wider before colliding with the [Gate, LED, Tune](./Gate-LED.md) board, but needs enough room for the micro USB cable (unless using the D+, D- pads) or a right-angle connector. Could expand _very slightly_ higher, constraints are staying within safe rack rail distances and not coliding with or pushing down the [PerfDAC2 (MIDI CC)](./performance-dac.md) board.

Curent in-progress mockup is 75.9mm by 38mm so just fits within that. However, SD slot is obstructed.

front

Connectors on back of board go to the display/buttons/encoder/pots board.

back

board

Board stacks with the sam-size [MPU-display](./MPU-display.md) board, via 4 stand-offs and the pin connectors. Stand-offs also anchor these boards to the front panel.

## BOM

## Development & Testing plan

- [ ] T4.1 on breadboard, power from +5V, measure current consumption at various clock speeds.
- [ ] 10k pot, ADC, ResponsiveAnalogRead
- [ ]  Create comparative DIN-MIDI input board with several alternatives, for testing.
- [ ] Test DIN MIDI input
- [ ] ~~Test I2C display, see if update speed okay and feasible for menus~~
- [x] Test SPI display
- [ ] start on menu/dashboard layout
- [ ] Measure switch bounce, test software bounce, try hardware debounces
- [x] Get Thonk encoders, encoder knobs, buttons
- [x] Test PWM of RGB LED.
  - [x] [Problems getting to exactly 0 and 100%](https://forum.pjrc.com/index.php?threads/full-range-pwm-for-rgb-led-control.74386/)
  - [x] Solved by special-casing PWM extremes.
  - [x] Test Adafruit LEDs instead
- [ ] Test 10V gate output.
- [ ] Fabricate [Gate-LED](./Gate-LED.md) board.
- [ ] Test FreqCount
- [x] Test FreqMeasure (and FreqMeasureMulti)
- [x] Sketch [front panel](./Panel.md) to get PCB dimensions.
- [ ] Fabricate & test [octal perfDAC/CCDAC](./performance-dac.md) board (same board, different CS)
  - DAC and level shift board ordered
- [ ] Fabricate [pitch CV](./pitch-dac.md) board, test
- [ ] Write higher-level, MPE-capable MIDI library
- [ ] Fabricate MCU and display carrier board
- [ ] Front panel

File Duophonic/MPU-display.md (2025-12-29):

# MPU Display

This stacks with the [MPU board](./MPU-board.md) and contains the display, buttons, and encoder.

For space reasons, the MIDI opto-isolator is also placed here.

## Schematic

## Board

Connections to the MPU board, optocoupler, and buffers for the potentiometers are on the front.

front

Connections to the OLED display, the encoder, and the buttons are on the back (nearest the front panel).

back

## UI: Display & Controls

The Encoder, the four buttons, and the display are all mounted on the [display board](./display-board.md) with their signals routed to the MPU board.

## SPI Display

Using [Adafruit OLED 128x64 1.3inch](./display.md). Needs DC, CS, and RST.

See [MPU board, SPI section](./MPU-board.md) and [display](./display.md).

[Advice on ground noise and OLED displays](https://modwiggler.com/forum/viewtopic.php?p=3999696#p3999696)

## Encoder, buttons

Buttons and [encoder](https://www.pjrc.com/teensy/td_libs_Encoder.html) for option selection and menu navigation. T3.6 & T4.1 can use any pins for encoders.

- 20 Encoder-A
- 21 Encoder-B
- 23 Encoder-switch
- 14 Button-1
- 15 Button-2
- 16 Button-3
- 17 Button-4

Encoder circuit (from Bourns PEC12R datasheet) four 10k, two 10nF (obviously connect to 3V3 not 5V):

filter

Encoder is Thonk EC11S-24P-0C-20KQ, T18 switched shaft.

Probably emits 4 counts for one detent forwards or backwards.

- [Hardware debounce vs. software hysteresis for encoders](https://forum.arduino.cc/t/rotary-encoder-debouncing/361438/12)
- [Measuring bounce on a scope](https://electronics.stackexchange.com/questions/430983/why-cant-i-see-bouncing-of-a-switch-on-an-oscilloscope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)

Use encoder switch as OK, needs anther button for "back".

Also needs "Calibrate" "Tune" and "Setup" ? Single button for common functions.

```
encoder1.write(desiredPosition)
```

### MIDI input

We detected a 2 layer board of 1.74 x 1.00 inches (44.2 x 25.3mm)
3 boards will cost $8.65

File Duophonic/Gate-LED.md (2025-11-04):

# Gate and LED

Provides gate, trigger outputs and LED indication of gate status.

RGB LEDs give feedback on what note is playing.

## LEDs

Two RGB LEDs, one per channel.

_(Older discussion on LED options moved to [old led page](./old-led.md))_

[NeoPixel Diffused 5mm Through-Hole LED - 5 Pack](https://www.adafruit.com/product/1938) easy 1-wire control, integrated pwm controller. Needs 5V so use logic level shifter such as 74LV1T34 (single) 74AHCT125 (quad) or 74HCT245 (octal). Library [includes HSV color model](https://learn.adafruit.com/adafruit-neopixel-uberguide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) as well as RGB, and includes [gamma encoding](https://learn.adafruit.com/adafruit-neopixel-uberguide?view=all#dot-dot-dot-and-gamma-correction-3024505) too.

Data connection is 3V3 from Teensy.

74LV1T34 provides 8mA output drive at 5V, so needs a +5V power.
74AHCT125 provides 20mA (max) 8mA (recommended) output drive at 5V. Has output enable, not needed here.

- [Use 100nF](https://learn.adafruit.com/adafruit-neopixel-uberguide?view=all#discrete-neopixel-products-2894456) between 5V and GND beside each LED.
- Connects to any random pin (custom bit-banged protocol). 
- Should have [300R to 500R in the data line, close to the LED](https://learn.adafruit.com/adafruit-neopixel-uberguide/best-practices).
- Current per LED is 12mA max

Sample code in RGB-NeoPixel-01.ino which works with direct 3V3 input, but a level shifter wold be more robust to small variations in 5V and 3V3 levels.

5mm through-hole neopixel

dimensions

## Gate & Trigger

### Voltage

General agreement that more than 5V _output_ is desirable, 8 to 10V is good, and that all _inputs_ are expected to handle ±12V. Some VCAs need 8V or so to fully open.

- https://modwiggler.com/forum/viewtopic.php?t=96737

Perhaps something like L78L08 **$0.32/1** driven from +12V to give +8V (min 7.2V max 8.8V) would be suitable. Current needs are low so a 100mA or lower regulator would be fine. Smaller size is better, SOT-89 is 4.5 x 2.5mm body. 330nF on input, 100nF on output.

### Circuit

**Avoid** the  [two-transistor gate output from Graham Hinton](https://modwiggler.com/forum/viewtopic.php?p=2720659&sid=8184a7a1e66cf2090d4727f4a460bd16#p2720659) because the description sounds good but builders report unreliable operation:

gate

>> Both transistors are used as switches, not amplifiers. The first transistor turns on at any input voltage above about 1V, this then turns on the second transistor which pulls the output up to +ve (+14V taken from the Roland). It assumes that the input is a Gate and has a fairly fast rise/fall time and is not an analogue signal like a LFO triangle. If you want to use slow rise/fall signals you need a Schmitt trigger.

Fixing the known inaccuracy in that schematic:

> Try a resistor like 10k between its base and emitter so that it is driven by voltage rather than current.

Instead, trying this one from [Synth DIY: Gate Buffer ](https://synthnerd.wordpress.com/2016/03/17/synth-diy-gate-buffer/):

gate2

See also [a known bad Gate in the original Arturia Beatstep](https://synthnerd.wordpress.com/arturia-beatstep/) which gives load-dependent 4V gates!

Gate is +8V. Test droop into low loads like 10k.

Trigger is around +8V for 10ms. Maybe 8V with a small 12V to 8V regulator? Thus, needs a +12V from the power board (but not -12V.).

## Boards

Panel board with 6 jacks on two rows (Gate & Trigger, Tune per voice), 2 LEDs above, one edge connector below.

- 4 for gate and trig
- 1 for NeopPixels
- 4 for gnd

Circuitry board with power connections (5V for level shifters, 12V to make gate/trig),
digital outs (4) for gate and trig,
gnd connection to teensy.

Maybe combine with [tune input](./calibration.md) on one board?

## Work Plan

- [x] experiment with level shifter & Teensy PWM to drive bare RGB LED. Looking for range of colors, flicker, CPU usage **abandones in favor of NeoPixels**
  - _It works fine with no level shifter, just 3v3 is okay. Tested with 270R, use higher value as this is too bright._
- [x] experiment with through-hole NeoPixels (**works**)
- [ ] breadboard two-transistor gate
- [ ] breadboard op-amp gate
- [ ] sketch to output 10ms pulse with a timer.

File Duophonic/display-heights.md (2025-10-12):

# Screen, button, encoder heights

Needs a test panel to check assembly of encoder, buttons, panel (on daughterboard).

## Screen

1.67mm pcb
**3.16mm** pcb+screen => 1.49mm screen thickness

**4.33mm** pcb+edge connector insulation => 2.66mm connector (excluding pins)

total height 4.33 + 3.16 - 1.67 = **5.82mm**
so needs -5.86 + 8.6 = **2.74mm** lift.
Long pin connector?

screen

## Thonk encoder

Thonk EC11S-24P-0C-20KQ, T18 switched shaft, 20mm above casing
7mm bushing height
casing **6.54mm** above PCB

thonk encoder
encoder photo

## Buttons

[Thonk Low profile](https://www.thonk.co.uk/shop/low-profile-push-buttons/)  **8.6mm** PCB to top of switch mechanism.

thonk buttons

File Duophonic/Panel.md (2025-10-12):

# Panel

Doepfer standard height is **128.5mm** and 2mm thickness but perhaps for a large panel with many heavy components mounted behind it, 2.5mm for rigidity is better.

## Max PCB dimensions

Panel height 128.5mm but with mounting holes and rails, 
Usable panel height 112mm.

Max PCB height **108mm**.

## Panel width

Current design is **24HP** = (24 × 5.08 = 121.92) - about 0.3 = 121.60mm, see [A100 Construction Details](https://www.doepfer.de/a100_man/a100m_e.htm).
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

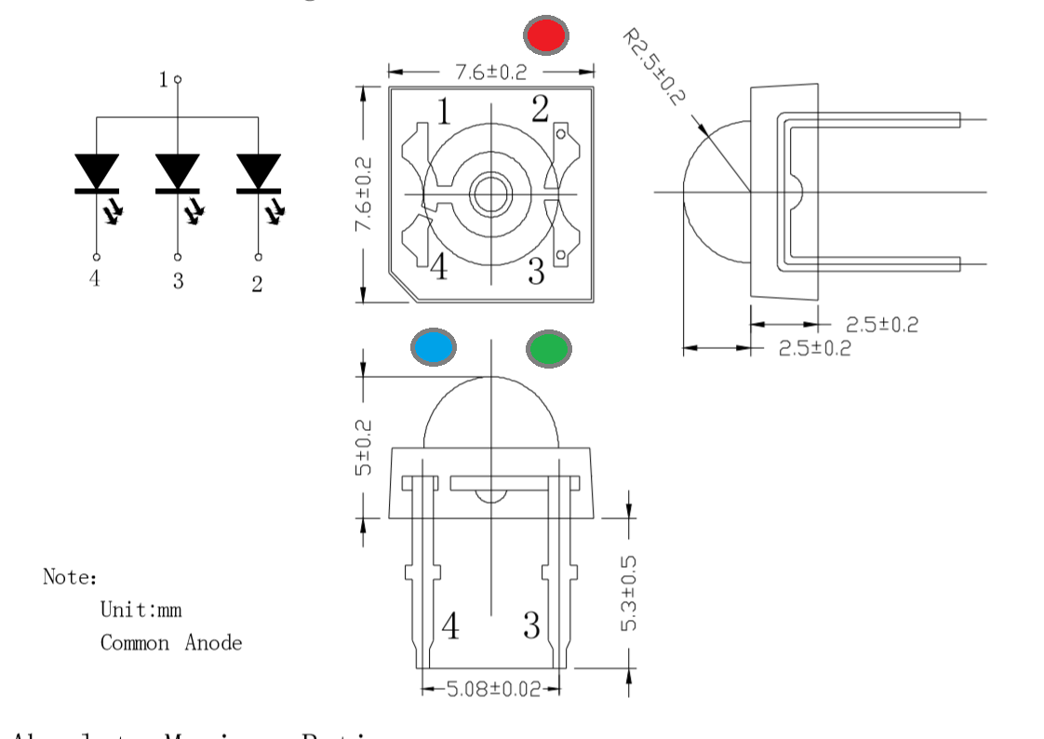
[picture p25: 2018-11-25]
img/LEDs/Pirhana-pinout.png

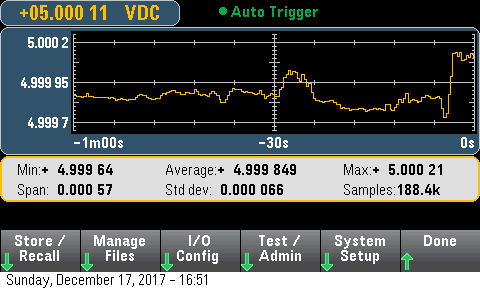
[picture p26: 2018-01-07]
img/AD588/5V-still-wandering.png

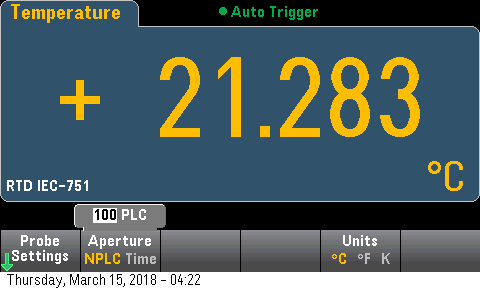
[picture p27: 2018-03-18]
img/Temperature/RTD100-room.png

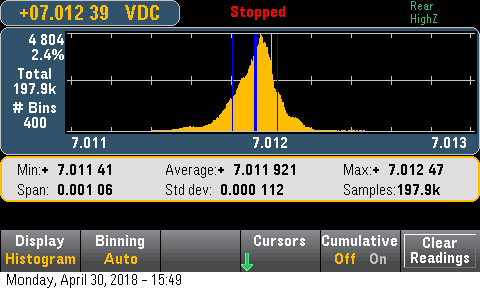
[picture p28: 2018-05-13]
img/LM399/399-2-Vz-hist-30042018.png

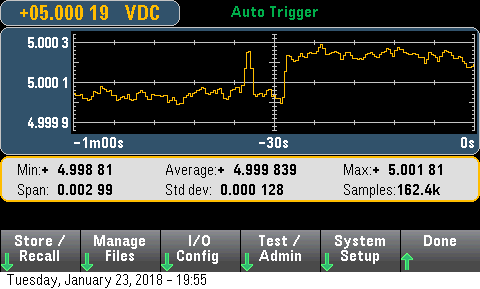
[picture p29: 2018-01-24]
img/AD588/5V-wandering3.png

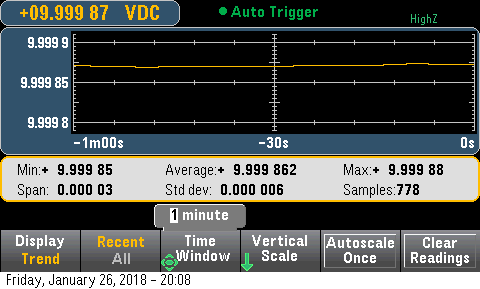
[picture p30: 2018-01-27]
img/other Vrefs/LT1021_Vref10_drift.png

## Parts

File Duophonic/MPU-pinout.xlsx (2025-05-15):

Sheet: T4
Pin | Name | GPIO | Serial | I2C | SPI | PWM | CAN | Audio | XBAR | FlexIO | Analog | SD
0 | AD_B0_03 | 1.3 | Serial1(6) RX |  | SPI1(3) CS0 | PWM1_X1 | 2_RX |  | IO-17
1 | AD_B0_02 | 1.2 | Serial1(6) TX |  | SPI1(3) MISO | PWM1_X0 | 2_TX |  | IO-16
2 | EMC_04 | 4.4 |  |  |  | PWM4_A2 |  | 2:TX_DATA | IO-06 | 1:4
3 | EMC_05 | 4.5 |  |  |  | PWM4_B2 |  | 2:TX_SYNC | IO-07 | 1:5
4 | EMC_06 | 4.6 |  |  |  | PWM2_A0 |  | 2:TX_BCLK | IO-08 | 1:6
5 | EMC_08 | 4.8 |  |  |  | PWM2_A1 |  | 2:RX_DATA | IO-17 | 1:8
6 | B0_10 | 2.10 |  |  |  | PWM2_A2, QT4_1 |  | 1:TX3_RX1 |  | 2:10
7 | B1_01 | 2.17 | Serial2(4) RX |  |  | PWM1_B3 |  | 1:TX_DATA | IO-15 | 2:17, 3:17
8 | B1_00 | 2.16 | Serial2(4) TX |  |  | PWM1_A3 |  | 1:RX_DATA | IO-14 | 2:16, 3:16
9 | B0_11 | 2.11 |  |  |  | PWM2_B2, QT4_2 |  | 1:TX2_RX2 |  | 2:11
10 | B0_00 | 2.0 |  |  | SPI(4) CS0 | QT1_0 |  | MQS_RIGHT |  | 2:0
11 | B0_02 | 2.2 |  |  | SPI(4) MOSI | QT1_2 | 1_TX |  |  | 2:2
12 | B0_01 | 2.1 |  |  | SPI(4) MISO | QT1_1 |  | MQS_LEFT |  | 2:1
13 | B0_03 | 2.3 |  |  | SPI(4) SCK | QT2_0 | 1_RX |  |  | 2:3
14/A0 | AD_B1_02 | 1.18 | Serial3(2) TX |  |  | QT3_2 |  | SPDIF_OUT |  | 3:2 | A1:7, A2:7
15/A1 | AD_B1_03 | 1.19 | Serial3(2) RX |  |  | QT3_3 |  | SPDIF_IN |  | 3:3 | A1:8, A2:8
16/A2 | AD_B1_07 | 1.23 | Serial4(3) RX | Wire1(3) SCL |  |  |  | SPDIF_EXTCLK |  | 3:7 | A1:12, A2:12
17/A3 | AD_B1_06 | 1.22 | Serial4(3) TX | Wire1(3) SDA |  |  |  | SPDIF_LOCK |  | 3:6 | A1:11, A2:11
18/A4 | AD_B1_01 | 1.17 | Serial3(2) RTS | Wire(1) SDA |  | QT3_1 |  |  |  | 3:1 | A1:6, A2:6
19/A5 | AD_B1_00 | 1.16 | Serial3(2) CTS | Wire(1) SCL |  | QT3_0 |  |  |  | 3:0 | A1:5, A2:5
20/A6 | AD_B1_10 | 1.26 | Serial5(8) TX |  |  |  |  | 1:RX_SYNC |  | 3:10 | A1:15, A2:15
21/A7 | AD_B1_11 | 1.27 | Serial5(8) RX |  |  |  |  | 1:RX_BCLK |  | 3:11 | A1:0, A2:0
22/A8 | AD_B1_08 | 1.24 |  |  |  | PWM4_A0 | 1_TX |  |  | 3:8 | A1:13, A2:13
23/A9 | AD_B1_09 | 1.25 |  |  |  | PWM4_A1 | 1_RX | 1:MCLK |  | 3:9 | A1:14, A2:14
--- | ---- | ---- | ------ | --- | --- | --- | --- | ---- | ---- | ----- | ------
24/A10 | AD_B0_12 | 1.12 | Serial6(1) TX | Wire2(4) SCL |  | PWM1_X2 |  |  |  |  | A1:1
25/A11 | AD_B0_13 | 1.13 | Serial6(1) RX | Wire2(4) SDA |  | PWM1_X3 | GPT1_CLK |  |  |  | A1:2
26/A12 | AD_B1_14 | 1.30 |  |  | SPI1(3) MOSI |  |  | 1:TX_BCLK |  | 3:14 | A2:3
27/A13 | AD_B1_15 | 1.31 |  |  | SPI1(3) SCK |  |  | 1:TX_SYNC |  | 3:15 | A2:4
28 | EMC_32 | 3.18 | Serial7(7) RX |  |  | PWM3_B1
29 | EMC_31 | 4.31 | Serial7(7) TX |  | SPI2(1) CS1 | PWM3_A1
30 | EMC_37 | 3.23 |  |  |  | GPT1_3 | 3_RX | 3:MCLK | IO-23
31 | EMC_36 | 3.22 |  |  |  | GPT1_2 | 3_TX | 3:TX_DATA | IO-22
32 | B0_12 | 2.12 |  |  |  |  |  | 1:TX1_RX3 | IO-10 | 2:12
33 | EMC_07 | 4.7 |  |  |  | PWM2_B0 |  | 2:MCLK | IO-09 | 1:7
34 | SD_B0_03 | 3.15 | Serial5(8) RTS |  | SPI2(1) MISO | PWM1_B1 |  |  | IO-07 |  |  | DATA1
35 | SD_B0_02 | 3.14 | Serial5(8) CTS |  | SPI2(1) MOSI | PWM1_A1 |  |  | IO-06 |  |  | DATA0
36 | SD_B0_01 | 3.13 |  | Wire1(3) SDA | SPI2(1) CS0 | PWM1_B0 |  |  | IO-05 |  |  | CLK
37 | SD_B0_00 | 3.12 |  | Wire1(3) SCL | SPI2(1) SCK | PWM1_A0 |  |  | IO-04 |  |  | CMD
38 | SD_B0_05 | 3.17 | Serial5(8) RX |  | SPI2(1) B_DQS | PWM1_B2 |  |  | IO-09 |  |  | DATA3
39 | SD_B0_04 | 3.16 | Serial5(8) TX |  | SPI2(1) B_SSO_B | PWM1_A2 |  |  | IO-08 |  |  | DATA2

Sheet: T4 - GPIO
Pin | Name | GPIO | Serial | I2C | SPI | PWM | CAN | Audio | XBAR | FlexIO | Analog | SD
1 | AD_B0_02 | 1.02 | Serial1(6) TX |  | SPI1(3) MISO | PWM1_X0 | 2_TX |  | IO-16
0 | AD_B0_03 | 1.03 | Serial1(6) RX |  | SPI1(3) CS0 | PWM1_X1 | 2_RX |  | IO-17
24/A10 | AD_B0_12 | 1.12 | Serial6(1) TX | Wire2(4) SCL |  | PWM1_X2 |  |  |  |  | A1:1
25/A11 | AD_B0_13 | 1.13 | Serial6(1) RX | Wire2(4) SDA |  | PWM1_X3 | GPT1_CLK |  |  |  | A1:2
19/A5 | AD_B1_00 | 1.16 | Serial3(2) CTS | Wire(1) SCL |  | QT3_0 |  |  |  | 3:0 | A1:5, A2:5
18/A4 | AD_B1_01 | 1.17 | Serial3(2) RTS | Wire(1) SDA |  | QT3_1 |  |  |  | 3:1 | A1:6, A2:6
14/A0 | AD_B1_02 | 1.18 | Serial3(2) TX |  |  | QT3_2 |  | SPDIF_OUT |  | 3:2 | A1:7, A2:7
15/A1 | AD_B1_03 | 1.19 | Serial3(2) RX |  |  | QT3_3 |  | SPDIF_IN |  | 3:3 | A1:8, A2:8
17/A3 | AD_B1_06 | 1.22 | Serial4(3) TX | Wire1(3) SDA |  |  |  | SPDIF_LOCK |  | 3:6 | A1:11, A2:11
16/A2 | AD_B1_07 | 1.23 | Serial4(3) RX | Wire1(3) SCL |  |  |  | SPDIF_EXTCLK |  | 3:7 | A1:12, A2:12
22/A8 | AD_B1_08 | 1.24 |  |  |  | PWM4_A0 | 1_TX |  |  | 3:8 | A1:13, A2:13
23/A9 | AD_B1_09 | 1.25 |  |  |  | PWM4_A1 | 1_RX | 1:MCLK |  | 3:9 | A1:14, A2:14
20/A6 | AD_B1_10 | 1.26 | Serial5(8) TX |  |  |  |  | 1:RX_SYNC |  | 3:10 | A1:15, A2:15
21/A7 | AD_B1_11 | 1.27 | Serial5(8) RX |  |  |  |  | 1:RX_BCLK |  | 3:11 | A1:0, A2:0
26/A12 | AD_B1_14 | 1.30 |  |  | SPI1(3) MOSI |  |  | 1:TX_BCLK |  | 3:14 | A2:3
27/A13 | AD_B1_15 | 1.31 |  |  | SPI1(3) SCK |  |  | 1:TX_SYNC |  | 3:15 | A2:4
10 | B0_00 | 2.00 |  |  | SPI(4) CS0 | QT1_0 |  | MQS_RIGHT |  | 2:0
12 | B0_01 | 2.01 |  |  | SPI(4) MISO | QT1_1 |  | MQS_LEFT |  | 2:1
11 | B0_02 | 2.02 |  |  | SPI(4) MOSI | QT1_2 | 1_TX |  |  | 2:2
13 | B0_03 | 2.03 |  |  | SPI(4) SCK | QT2_0 | 1_RX |  |  | 2:3
6 | B0_10 | 2.10 |  |  |  | PWM2_A2, QT4_1 |  | 1:TX3_RX1 |  | 2:10
9 | B0_11 | 2.11 |  |  |  | PWM2_B2, QT4_2 |  | 1:TX2_RX2 |  | 2:11
32 | B0_12 | 2.12 |  |  |  |  |  | 1:TX1_RX3 | IO-10 | 2:12
8 | B1_00 | 2.16 | Serial2(4) TX |  |  | PWM1_A3 |  | 1:RX_DATA | IO-14 | 2:16, 3:16
7 | B1_01 | 2.17 | Serial2(4) RX |  |  | PWM1_B3 |  | 1:TX_DATA | IO-15 | 2:17, 3:17
37 | SD_B0_00 | 3.12 |  | Wire1(3) SCL | SPI2(1) SCK | PWM1_A0 |  |  | IO-04 |  |  | CMD
36 | SD_B0_01 | 3.13 |  | Wire1(3) SDA | SPI2(1) CS0 | PWM1_B0 |  |  | IO-05 |  |  | CLK
35 | SD_B0_02 | 3.14 | Serial5(8) CTS |  | SPI2(1) MOSI | PWM1_A1 |  |  | IO-06 |  |  | DATA0
34 | SD_B0_03 | 3.15 | Serial5(8) RTS |  | SPI2(1) MISO | PWM1_B1 |  |  | IO-07 |  |  | DATA1
39 | SD_B0_04 | 3.16 | Serial5(8) TX |  | SPI2(1) B_SSO_B | PWM1_A2 |  |  | IO-08 |  |  | DATA2
38 | SD_B0_05 | 3.17 | Serial5(8) RX |  | SPI2(1) B_DQS | PWM1_B2 |  |  | IO-09 |  |  | DATA3
28 | EMC_32 | 3.18 | Serial7(7) RX |  |  | PWM3_B1
31 | EMC_36 | 3.22 |  |  |  | GPT1_2 | 3_TX | 3:TX_DATA | IO-22
30 | EMC_37 | 3.23 |  |  |  | GPT1_3 | 3_RX | 3:MCLK | IO-23
2 | EMC_04 | 4.04 |  |  |  | PWM4_A2 |  | 2:TX_DATA | IO-06 | 1:4
3 | EMC_05 | 4.05 |  |  |  | PWM4_B2 |  | 2:TX_SYNC | IO-07 | 1:5
4 | EMC_06 | 4.06 |  |  |  | PWM2_A0 |  | 2:TX_BCLK | IO-08 | 1:6
33 | EMC_07 | 4.07 |  |  |  | PWM2_B0 |  | 2:MCLK | IO-09 | 1:7
5 | EMC_08 | 4.08 |  |  |  | PWM2_A1 |  | 2:RX_DATA | IO-17 | 1:8
29 | EMC_31 | 4.31 | Serial7(7) TX |  | SPI2(1) CS1 | PWM3_A1

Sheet: T4 card like
Audio | Prop | Native | GPIO | Audio | FlexIO | Xbar | I2C | CAN | SPI | Serial | Analog | PWM | Digital |  |  | Digital | PWM | Analog | Serial | SPI | CAN | I2C | Xbar | FlexIO | Audio | GPIO | Native | Prop | Audio
G | GND |  |  |  |  |  |  |  |  |  | GND |  |  |  |  | Vin |  |  |  |  |  |  |  |  |  |  |  | 5V
 |  | AD_B0_03 | 1.3 |  |  | 17 |  | RX2 | CS1 | RX1 |  | 1X1 | 0 |  |  | GND |  |  |  |  |  |  |  |  |  |  |  | G | G
 |  | AD_B0_02 | 1.2 |  |  | 16 |  | TX2 | MISO1 | TX1 |  | 1X0 | 1 |  |  | 3.3V 250mA max |  |  |  |  |  |  |  |  |  |  |  | 3V | 3.3
 | S | EMC_04 | 4.4 | O2 | 1:4 | 6 |  |  |  |  |  | 4A2 | 2 |  |  | 23 | 4A1 | A9 |  |  | RX1 |  |  | 3:9 | MCL1 | 1.25 | AD-B1_09 |  | A
M |  | EMC_05 | 4.5 | LR2 | 1:5 | 7 |  |  |  |  |  | 4B2 | 3 |  |  | 22 | 4A0 | A8 |  |  | TX1 |  |  | 3:08:00 |  | 1.24 | AD_B1_08
A |  | EMC_06 | 4.6 | BCL2 | 1:6 | 8 |  |  |  |  |  | 2A0 | 4 |  |  | 21 |  | A7 | RX5 |  |  |  |  | 3:11:00 | BCL1 | 1.27 | AD_B1_11 |  | A
A | A-EN | EMC_08 | 4.8 | IN2 | 1:8 | 17 |  |  |  |  |  | 2A1 | 5 |  |  | 20 |  | A6 | TX5 |  |  |  |  | 3:10:00 | LRC1 | 1.26 | AD_B1_10 |  | A
 | M-CS | B0_10 | 2.10 | O1D | 2:10 |  |  |  |  |  |  | 2A2, Q41 | 6 |  |  | 19 | Q30 | A5 | CTS3 |  |  | SCL0 |  | 3:00:00 |  | 1.16 | AD_B1_00 | S | C
 | L-EN | B1_01 | 2.17 | O1A | 2:17, 3:17 | 15 |  |  |  | RX2 |  | 1B3 | 7 |  |  | 18 | Q31 | A4 |  |  |  | SDA0 |  | 3:01:00 |  | 1.17 | AD_B1_01 | S | C
 |  | B1_00 | 2.16 | IN1 | 2:16, 3:16 | 14 | sda0 |  |  | TX2 |  | 1A3 | 8 |  |  | 17 |  | A3 | TX4 |  |  | SDA1 |  | 3:06:00 |  | 1.22 | AD_B1_06
 |  | B0_11 | 2.11 | O1C | 2:11 |  |  |  |  |  |  | 2B2,Q42 | 9 |  |  | 16 |  | A2 | RX4 |  |  | SCL1 |  | 3:07:00 |  | 1.23 | AD_B1_07
S |  | B0_00 | 2.0 | MQR | 2:0 |  |  |  | CS0 |  |  | Q10 | 10 |  |  | 15 | Q33 | A1 | RX3 |  |  |  |  | 3:03:00 | SPDI | 1.19 | AD_B1_03 |  | V
SM | M/L | B0_02 | 2.2 |  | 2:2 |  |  | TX1 | MOSI0 |  |  | Q12 | 11 |  |  | 14 | Q32 | A0 | TX3 |  |  |  |  | 3:02:00 | SPDO | 1.18 | AD_B1_02
SM | M | B0_01 | 2.1 | MQL | 2:1 |  |  |  | MISO0 |  |  | Q11 | 12 |  |  | 13 | Q20 | LED |  | SCK0 | rx1 |  |  | 2:03:00 |  | 2.3 | B0_03 | M | SM
 |  |  |  |  |  |  |  |  |  | Bottom SMT Pins
 |  | AD_B0_12 | 1.12 |  |  |  | SCL2 |  |  | TX6 | A10-1 | 1X2 | 24 |  |  | 25 | 1X3 | A11-1 | RX6 |  |  | SDA2 |  |  |  | 1.13 | AD_B0_13
 |  | AD_B1_14 | 1.30 |  | 3:14 |  |  |  | MOSI1 |  | A12-2 |  | 26 |  |  | 27 |  | A13-2 |  | SCK1 |  |  |  | 3:15 |  | 1.31 | AD_B1_15
 |  | EMC_32 | 3.18 |  |  |  |  |  |  | RX7 |  | 3B1 | 28 |  |  | 29 | 3A1 |  | TX7 |  |  |  |  |  |  | 4.31 | EMC_31
 |  | EMC_37 | 3.23 |  |  | 23 |  | RX3 |  |  |  | G13 | 30 |  |  | 31 | G12 |  |  |  | TX3 |  | 22 |  |  | 3.22 | EMC_36
 |  | B0_12 | 2.12 | O1B | 2:12:00 | 10 |  |  |  |  |  |  | 32 |  |  | 33 | 2B0 |  |  |  | TX1 |  | 9 | 1:7 | MCL2 | 4.7 | EMC_07
 |  |  |  |  |  |  |  |  |  | Bottom SDIO Pins
 |  | SD_B0_03 | 3.15 |  | DATA1 | 7 |  |  | MISO2 |  |  | 1B1 | 34 | ______| | |_____
 |  | SD_B0_02 | 3.14 |  | DATA0 | 6 |  |  | MOSI2 | CTS5 |  | 1A1 | 35 | _______| | |_______
 |  |  |  |  |  |  |  |  |  |  | GND |  |  | _________| | |_______
 |  | SD_B0_01 | 3.13 |  | CLK | 5 | SDA1 |  | CS2 |  |  | 1B0 | 36 | __________| | |___________
 |  |  |  |  |  |  |  |  |  |  | 3.3V 250mA max
 |  | SD_B0_00 | 3.12 |  | CMD | 4 | SCL1 |  | SCK2 |  |  | 1A0 | 37
 |  | SD_B0_05 | 3.17 |  | DATA3 | 9 |  |  |  | RX5 |  | 1B2 | 38
 |  | SD_B0_04 | 3.16 |  | DATA2 | 8 |  |  |  | TX5 |  | 1A2 | 39

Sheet: T4.1
Pin | Name | GPIO | Serial | I2C | SPI | PWM | CAN | Audio | XBAR | FlexIO | Analog | SD/CSI/LCD
0 | AD_B0_03 | 1.3 | Serial1(6) RX |  | SPI1(3) CS0 | PWM1_X1 | 2_RX |  | IO-17
1 | AD_B0_02 | 1.2 | Serial1(6) TX |  | SPI1(3) MISO | PWM1_X0 | 2_TX |  | IO-16
2 | EMC_04 | 4.4 |  |  |  | PWM4_A2 |  | 2:TX_DATA | IO-06 | 1:4
3 | EMC_05 | 4.5 |  |  |  | PWM4_B2 |  | 2:TX_SYNC | IO-07 | 1:5
4 | EMC_06 | 4.6 |  |  |  | PWM2_A0 |  | 2:TX_BCLK | IO-08 | 1:6
5 | EMC_08 | 4.8 |  |  |  | PWM2_A1 |  | 2:RX_DATA | IO-17 | 1:8
6 | B0_10 | 2.10 |  |  |  | PWM2_A2, QT4_1 |  | 1:TX3_RX1 |  | 2:10
7 | B1_01 | 2.17 | Serial2(4) RX |  |  | PWM1_B3 |  | 1:TX_DATA | IO-15 | 2:17, 3:17
8 | B1_00 | 2.16 | Serial2(4) TX |  |  | PWM1_A3 |  | 1:RX_DATA | IO-14 | 2:16, 3:16
9 | B0_11 | 2.11 |  |  |  | PWM2_B2,QT4_2 |  | 1:TX2_RX2 |  | 2:11
10 | B0_00 | 2.0 |  |  | SPI(4) CS0 | QT1_0 |  | MQS_RIGHT |  | 2:0
11 | B0_02 | 2.2 |  |  | SPI(4) MOSI | QT1_2 | 1_TX |  |  | 2:2
12 | B0_01 | 2.1 |  |  | SPI(4) MISO | QT1_1 |  | MQS_LEFT |  | 2:1
13 | B0_03 | 2.3 |  |  | SPI(4) SCK | QT2_0 | 1_RX |  |  | 2:3
14/A0 | AD_B1_02 | 1.18 | Serial3(2) TX |  |  | QT3_2 |  | SPDIF_OUT |  | 3:2 | A1:7, A2:7
15/A1 | AD_B1_03 | 1.19 | Serial3(2) RX |  |  | QT3_3 |  | SPDIF_IN |  | 3:3 | A1:8, A2:8
16/A2 | AD_B1_07 | 1.23 | Serial4(3) RX | Wire1(3) SCL |  |  |  | SPDIF_EXTCLK |  | 3:7 | A1:12, A2:12 | CSI_HSYNC
17/A3 | AD_B1_06 | 1.22 | Serial4(3) TX | Wire1(3) SDA |  |  |  | SPDIF_LOCK |  | 3:6 | A1:11, A2:11 | CSI_VSYNC
18/A4 | AD_B1_01 | 1.17 | Serial3(2) RTS | Wire(1) SDA |  | QT3_1 |  |  |  | 3:1 | A1:6, A2:6
19/A5 | AD_B1_00 | 1.16 | Serial3(2) CTS | Wire(1) SCL |  | QT3_0 |  |  |  | 3:0 | A1:5, A2:5
20/A6 | AD_B1_10 | 1.26 | Serial5(8) TX |  |  |  |  | 1:RX_SYNC |  | 3:10 | A1:15, A2:15 | CSI_D7
21/A7 | AD_B1_11 | 1.27 | Serial5(8) RX |  |  |  |  | 1:RX_BCLK |  | 3:11 | A1:0, A2:0 | CSI_D6
22/A8 | AD_B1_08 | 1.24 |  |  |  | PWM4_A0 | 1_TX |  |  | 3:8 | A1:13, A2:13 | CSI_D9
23/A9 | AD_B1_09 | 1.25 |  |  |  | PWM4_A1 | 1_RX | 1:MCLK |  | 3:9 | A1:14, A2:14 | CSI_D8
--- | ---- | ---- | ------ | --- | --- | --- | --- | ---- | ---- | ----- | ------
24/A10 | AD_B0_12 | 1.12 | Serial6(1) TX | Wire2(4) SCL |  | PWM1_X2 |  |  |  |  | A1:1
25/A11 | AD_B0_13 | 1.13 | Serial6(1) RX | Wire2(4) SDA |  | PWM1_X3 | GPT1_CLK |  |  |  | A1:2
26/A12 | AD_B1_14 | 1.30 |  |  | SPI1(3) MOSI |  |  | 1:TX_BCLK |  | 3:14 | A2:3 | CSI_D3
27/A13 | AD_B1_15 | 1.31 |  |  | SPI1(3) SCK |  |  | 1:TX_SYNC |  | 3:15 | A2:4 | CSI_D2
28 | EMC_32 | 3.18 | Serial7(7) RX |  |  | PWM3_B1
29 | EMC_31 | 4.31 | Serial7(7) TX |  | SPI2(1) CS1 | PWM3_A1
30 | EMC_37 | 3.23 |  |  |  | GPT1_3 | 3_RX | 3:MCLK | IO-23
31 | EMC_36 | 3.22 |  |  |  | GPT1_2 | 3_TX | 3:TX_DATA | IO-22
32 | B0_12 | 2.12 |  |  |  |  |  | 1:TX1_RX3 | IO-10 | 2:12
33 | EMC_07 | 4.7 |  |  |  | PWM2_B0 |  | 2:MCLK | IO-09 | 1:7
34 | B1_13 | 2.29 | Serial8(5) RX |  |  |  |  |  |  | 2:29,3:29
35 | B1_12 | 2.28 | Serial8(5) TX |  |  |  |  |  |  | 2:28,3:28
36 | B1_02 | 2.18 |  |  | SPI(4) CS2 | PWM2_A3 |  | 1:TX_BCLK | IO-16 | 2:18,3:18
37 | B1_03 | 2.19 |  |  | SPI(4) CS1 | PWM2_B3 |  | 1:TX_SYNC | IO-17 | 2:19,3:19
38/A14 | AD_B1_12 | 1.28 |  |  | SPI1(3) CS0 |  |  | 1:rx_data |  | 3:12 | A2:1 | CSI_D5
39/A5 | AD_B1_13 | 1.29 |  |  | SPI1(3) MISO |  |  | 1:tx_data |  | 3:13 | A2:2 | CSI_D4
40/A16 | AD_B1_04 | 1.20 |  |  |  |  |  |  |  | 3:4 | A1:9,A2:9 | CSI_PIXCLK
41/A17 | AD_B1_05 | 1.21 |  |  |  | GPT2_1 |  |  |  | 3:5 | A1:10,A2:10 | CSI_MCLK
SD Pins - Cable connector(T4 34-39)
42 | SD_B0_03 | 3.15 | Serial5(8) RTS |  | SPI2(1) MISO | PWM1_B1 |  |  | IO-07 |  |  | DATA1
43 | SD_B0_02 | 3.14 | Serial5(8) CTS |  | SPI2(1) MOSI | PWM1_A1 |  |  | IO-06 |  |  | DATA0
44 | SD_B0_01 | 3.13 |  | Wire1(3) SDA | SPI2(1) CS0 | PWM1_B0 |  |  | IO-05 |  |  | CLK
45 | SD_B0_00 | 3.12 |  | Wire1(3) SCL | SPI2(1) SCK | PWM1_A0 |  |  | IO-04 |  |  | CMD
46 | SD_B0_05 | 3.17 | Serial5(8) RX |  | FLEXSPI B_DQS | PWM1_B2 |  |  | IO-09 |  |  | DATA3
47 | SD_B0_04 | 3.16 | Serial5(8) TX |  | FLEXSPI B_SSO_B | PWM1_A2 |  |  | IO-08 |  |  | DATA2
Bottom Memory Connectors
48 | EMC_24 | 4:24 | Serial8(5) RX |  | FLEXSPI2_A_SS0_B | PWM1_B0
49 | EMC_27 | 4:27 | Serial8(5) RTS |  | FLEXSPI2_A_DATA01, SPI2(1) SCK | PWM1_A2 |  |  |  | 1:13
50 | EMC_28 | 4:28 | Serial8(5) CTS |  | FLEXSPI2_A_DATA02, SPI2(1) MOSI | PWM1_B2 |  |  |  | 1:14
51 | EMC_22 | 4:22 |  | Wire1(3) SCL | FLEXSPI2_A_SS1_B | PWM3_B3, QT2_3
52 | EMC_26 | 4:26 | Serial1(6) RX |  | FLEXSPI2_A_DATA00 | PWM1_B1 |  |  |  | 1:12
53 | EMC_25 | 4:25 | Serial1(6) TX |  | FLEXSPI2_A_SCLK | PWM1_A1
54 | EMC_29 | 4:29 | Serial1(6) RTS |  | FLEXSPI2_A_DATA03, SPI2(1) MISO | PWM3_A0 |  |  |  | 1:15

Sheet: T4.1 MUX
Pin | Name | ALT0 | ALt1 | ALT2 | ALT3 | ALT4 | Alt5 | ALT6 | ALT7 | ALT8 | ALT9
0 | AD_B0_03 | FLEXCAN2_RX | XBAR1_INOUT17 | LPUART6_RX | USB_OTG1_OC | FLEXPWM1_PWMX01 | GPIO1_IO03 | REF_CLK_24M | LPSPI3_PCS0
1 | AD_B0_02 | FLEXCAN2_TX | XBAR1_INOUT16 | LPUART6_TX | USB_OTG1_PWR | LEXPWM1_PWMX0 | GPIO1_IO02 | LPI2C1_HREQ | LPSPI3_SDI
2 | EMC_04 | SEMC_DATA04 | FLEXPWM4_PWMA02 | SAI2_TX_DATA | XBAR1_INOUT06 | FLEXIO1_FLEXIO04 | GPIO4_IO04
3 | EMC_05 | SEMC_DATA05 | FLEXPWM4_PWMB0 | SAI2_TX_SYNC | XBAR1_INOUT07 | FLEXIO1_FLEXIO05 | GPIO4_IO05
4 | EMC_06 | SEMC_DATA06 | FLEXPWM2_PWMA00 | SAI2_TX_BCLK | XBAR1_INOUT08 | FLEXIO1_FLEXIO06 | GPIO4_IO06
5 | EMC_08 | SEMC_DM00 | FLEXPWM2_PWMA01 | SAI2_RX_DATA | XBAR1_INOUT17 | FLEXIO1_FLEXIO08 | GPIO4_IO08
6 | B0_10 | LCD_DATA06 | QTIMER4_TIMER1 | FLEXPWM2_PWMA02 | SAI1_TX_DATA03 | FLEXIO2_FLEXIO10 | GPIO2_IO10 | SRC_BOOT_CFG06 |  | ENET2_CRS
7 | B1_01 | LCD_DATA13 | XBAR1_INOUT15 | LPUART4_RX | SAI1_TX_DATA00 | FLEXIO2_FLEXIO17 | GPIO2_IO17 | FLEXPWM1_PWMB03 |  | ENET2_RDATA00 | FLEXIO3_FLEXIO17
8 | B1_00 | LCD_DATA12 | XBAR1_INOUT14 | LPUART4_TX | SAI1_RX_DATA00 | FLEXIO2_FLEXIO16 | GPIO2_IO16 | FLEXPWM1_PWMA03 |  | ENET2_RX_ER | FLEXIO3_FLEXIO16
9 | B0_11 | LCD_DATA07 | QTIMER4_TIMER2 | FLEXPWM2_PWMB02 | SAI1_TX_DATA02 | FLEXIO2_FLEXIO11 | GPIO2_IO11 | SRC_BOOT_CFG07 |  | ENET2_COL
10 | B0_00 | LCD_CLK | QTIMER1_TIMER0 | MQS_RIGHT | LPSPI4_PCS0 | FLEXIO2_FLEXIO00 | GPIO2_IO00 | SEMC_CSX01 |  | ENET2_MDC
11 | B0_02 | LCD_HSYNC | QTIMER1_TIMER2 | FLEXCAN1_TX | LPSPI4_SDO | FLEXIO2_FLEXIO02 | GPIO2_IO02 | SEMC_CSX03 |  | ENET2_1588_EVENT0_OUT
12 | B0_01 | LCD_ENABLE | QTIMER1_TIMER1 | MQS_LEFT | LPSPI4_SDI | FLEXIO2_FLEXIO01 | GPIO2_IO01 | SEMC_CSX02 |  | ENET2_MDIO
13 | B0_03 | LCD_VSYNC | QTIMER2_TIMER0 | FLEXCAN1_RX | LPSPI4_SCK | FLEXIO2_FLEXIO03 | GPIO2_IO03 | WDOG2_RESET_B_DEB |  | ENET2_1588_EVENT0_IN
14/A0 | AD_B1_02 | USB_OTG1_ID | QTIMER3_TIMER2 | LPUART2_TX | SPDIF_OUT | ENET_1588_EVENT2_OUT | GPIO1_IO18 | USDHC1_CD_B | KPP_ROW06 | GPT2_CLK | FLEXIO3_FLEXIO02
15/A1 | AD_B1_03 | USB_OTG1_OC | QTIMER3_TIMER3 | LPUART2_RX | SPDIF_IN | ENET_1588_EVENT2_IN | GPIO1_IO19 | USDHC2_CD_B | KPP_COL06 | GPT2_CAPTURE1 | FLEXIO3_FLEXIO03
16/A2 | AD_B1_07 | FLEXSPIB_DATA00 | LPI2C3_SCL | LPUART3_RX | SPDIF_EXT_CLK | CSI_HSYNC | GPIO1_IO23 | USDHC2_DATA3 | KPP_COL04 | GPT2_COMPARE3 | FLEXIO3_FLEXIO07
17/A3 | AD_B1_06 | FLEXSPIB_DATA01 | LPI2C3_SDA | LPUART3_TX | SPDIF_LOCK | CSI_VSYNC | GPIO1_IO22 | USDHC2_DATA2 | KPP_ROW04 | GPT2_COMPARE2 | FLEXIO3_FLEXIO06
18/A4 | AD_B1_01 | USB_OTG1_PWR | QTIMER3_TIMER1 | LPUART2_RTS_B | LPI2C1_SDA | CCM_PMIC_READY | GPIO1_IO17 | USDHC1_VSELECT | KPP_COL07 | ENET2_1588_EVENT0_IN | FLEXIO3_FLEXIO01
19/A5 | AD_B1_00 | USB_OTG2_ID | QTIMER3_TIMER0 | LPUART2_CTS_B | LPI2C1_SCL | WDOG1_B | GPIO1_IO16 | USDHC1_W | KPP_ROW07 | ENET2_1588_EVENT0_OUT | FLEXIO3_FLEXIO00
20/A6 | AD_B1_10 | FLEXSPIA_DATA03 | WDOG1_B | LPUART8_TX | SAI1_RX_SYNC | CSI_DATA07 | GPIO1_IO26 | USDHC2_WP | KPP_ROW02 | ENET2_1588_EVENT1_OUT | FLEXIO3_FLEXIO10
21/A7 | AD_B1_11 | FLEXSPIA_DATA02 | EWM_OUT_B | LPUART8_RX | SAI1_RX_BCL | CSI_DATA06 | GPIO1_IO27 | USDHC2_RESET_B | KPP_COL02 | ENET2_1588_EVENT1_IN | FLEXIO3_FLEXIO11
22/A8 | AD_B1_08 | FLEXSPIA_SS1_B | FLEXPWM4_PWMA00 | FLEXCAN1_TX | CCM_PMIC_READY | CSI_DATA09 | GPIO1_IO24 | USDHC2_CMD | KPP_ROW03 |  | FLEXIO3_FLEXIO08
23/A9 | AD_B1_09 | FLEXSPIA_DQS | FLEXPWM4_PWMA01 | FLEXCAN1_RX | SAI1_MCLK | CSI_DATA08 | GPIO1_IO25 | USDHC2_CLK | KPP_COL03 |  | FLEXIO3_FLEXIO09
24/A10 | AD_B0_12 | LPI2C4_SCL | CCM_PMIC_READY | LPUART1_TX | WDOG2_WDOG_B | FLEXPWM1_PWMX02 | GPIO1_IO12 | ENET_1588_EVENT1_OUT | NMI_GLUE_NMI
25/A11 | AD_B0_13 | LPI2C4_SDA | GPT1_CLK | LPUART1_RX | EWM_OUT_B | FLEXPWM1_PWMX03 | GPIO1_IO13 | ENET_1588_EVENT1_IN | REF_CLK_24M
26/A12 | AD_B1_14 | FLEXSPIA_SCLK | ACMP_OUT02 | LPSPI3_SDO | SAI1_TX_BCLK | CSI_DATA03 | GPIO1_IO30 | USDHC2_DATA6 | KPP_ROW00 | ENET2_1588_EVENT3_OUT | FLEXIO3_FLEXIO14
27/A13 | AD_B1_15 | FLEXSPIA_SS0_B | ACMP_OUT03 | LPSPI3_SCK | SAI1_TX_SYNC | CSI_DATA02 | GPIO1_IO31 | USDHC2_DATA7 | KPP_COL00 | ENET2_1588_EVENT3_IN | FLEXIO3_FLEXIO15
28 | EMC_32 | SEMC_DATA10 | FLEXPWM3_PWMB01 | LPUART7_RX | CCM_PMIC_RDY | CSI_DATA21 | GPIO3_IO18 |  |  | ENET2_TX_EN
29 | EMC_31 | SEMC_DATA09 | FLEXPWM3_PWMA01 | LPUART7_TX | LPSPI1_PCS1 | CSI_DATA22 | GPIO4_IO31 |  |  | ENET2_TDATA01
30 | EMC_37 | SEMC_DATA15 | XBAR1_IN23 | GPT1_COMPARE3 | SAI3_MCLK | CSI_DATA16 | GPIO3_IO23 | USDHC2_WP |  | ENET2_RX_EN | FLEXCAN3_RX
31 | EMC_36 | SEMC_DATA14 | XBAR1_IN22 | GPT1_COMPARE2 | SAI3_TX_DATA | CSI_DATA17 | GPIO3_IO22 | USDHC1_WP |  | ENET2_RDATA01 | FLEXCAN3_TX
32 | B0_12 | LCD_DATA08 | XBAR1_INOUT10 | ARM_TRACE_CLK | SAI1_TX_DATA01 | FLEXIO2_FLEXIO12 | GPIO2_IO12 | SRC_BOOT_CFG08 |  | ENET2_TDATA00
33 | EMC_07 | SEMC_DATA07 | FLEXPWM2_PWMB00 | SAI2_MCLK | XBAR1_INOUT09 | FLEXIO1_FLEXIO07 | GPIO4_IO07
34 | B1_13 | WDOG1_B | LPUART5_RX | CSI_VSYNC | ENET_1588_EVENT0_OUT | FLEXIO2_FLEXIO29 | GPIO2_IO29 | USDHC1_WP |  | SEMC_DQS4 | FLEXIO3_FLEXIO29
35 | B1_12 |  | LPUART5_TX | CSI_PIXCLK | ENET_1588_EVENT0_IN | FLEXIO2_FLEXIO28 | GPIO2_IO28 | USDHC1_CD_B |  |  | FLEXIO3_FLEXIO28
36 | B1_02 | LCD_DATA14 | XBAR1_INOUT16 | LPSPI4_PCS2 | SAI1_TX_BCLK | FLEXIO2_FLEXIO18 | GPIO2_IO18 | FLEXPWM2_PWMA03 |  | ENET2_RDATA01 | FLEXIO3_FLEXIO18
37 | B1_03 | LCD_DATA15 | XBAR1_INOUT17 | LPSPI4_PCS1 | SAI1_TX_SYNC | FLEXIO2_FLEXIO19 | GPIO2_IO19 | FLEXPWM2_PWMB03 |  | ENET2_RX_EN | FLEXIO3_FLEXIO19
38/A14 | AD_B1_12 | FLEXSPIA_DATA01 | ACMP_OUT00 | LPSPI3_PCS0 | SAI1_RX_DATA00 | CSI_DATA05 | GPIO1_IO28 | USDHC2_DATA4 | KPP_ROW01 | ENET2_1588_EVENT2_OUT | FLEXIO3_FLEXIO12
39/A5 | AD_B1_13 | FLEXSPIA_DATA00 | ACMP_OUT01 | LPSPI3_SDI | SAI1_TX_DATA00 | CSI_DATA04 | GPIO1_IO29 | USDHC2_DATA5 | KPP_COL01 | ENET2_1588_EVENT2_IN | FLEXIO3_FLEXIO13
40/A16 | AD_B1_04 | FLEXSPIB_DATA03 | ENET_MDC | LPUART3_CTS_B | SPDIF_SR_CLK | CSI_PIXCLK | GPIO1_IO20 | USDHC2_DATA0 | KPP_ROW05 | GPT2_CAPTURE2 | FLEXIO3_FLEXIO04
41/A17 | AD_B1_05 | FLEXSPIB_DATA02 | ENET_MDIO | LPUART3_RTS_B | SPDIF_OUT | CSI_MCLK | GPIO1_IO21 | USDHC2_DATA1 | KPP_COL05 | GPT2_COMPARE1 | FLEXIO3_FLEXIO05
42 | SD_B0_03 | USDHC1_DATA1 | FLEXPWM1_PWMB01 | LPUART8_RTS_B | XBAR1_INOUT07 | LPSPI1_SDI | GPIO3_IO15 |  |  | ENET2_RDATA00 | SEMC_CLK6
43 | SD_B0_02 | USDHC1_DATA0 | FLEXPWM1_PWMA01 | LPUART8_CTS_B | XBAR1_INOUT06 | LPSPI1_SDO | GPIO3_IO14 |  |  | ENET2_RX_ER | SEMC_CLK5
44 | SD_B0_01 | USDHC1_CLK | FLEXPWM1_PWMB00 | LPI2C3_SDA | XBAR1_INOUT05 | LPSPI1_PCS0 | GPIO3_IO13 | FLEXSPIB_SS1_B |  | ENET2_TX_CLK | ENET2_REF_CLK2
45 | SD_B0_00 | USDHC1_CMD | FLEXPWM1_PWMA00 | LPI2C3_SCL | XBAR1_INOUT04 | LPSPI1_SCK | GPIO3_IO12 | FLEXSPIA_SS1_B |  | ENET2_TX_EN | SEMC_DQS4
46 | SD_B0_05 | USDHC1_DATA3 | FLEXPWM1_PWMB02 | LPUART8_RX | XBAR1_INOUT09 | FLEXSPIB_DQS | GPIO3_IO17 | CCM_CLKO2 |  | ENET2_RX_EN
47 | SD_B0_04 | USDHC1_DATA2 | FLEXPWM1_PWMA02 | LPUART8_TX | XBAR1_INOUT08 | FLEXSPIB_SS0_B | GPIO3_IO16 | CCM_CLKO1 |  | ENET2_RDATA01
48 | EMC_24 | SEMC_CAS | FLEXPWM1_PWMB00 | LPUART5_RX | ENET_TX_EN | GPT1_CAPTURE1 | GPIO4_IO24 |  |  | FLEXSPI2_A_SS0_B
49 | EMC_27 | SEMC_CKE | FLEXPWM1_PWMA02 | LPUART5_RTS_B | LPSPI1_SCK | FLEXIO1_FLEXIO13 | GPIO4_IO27 |  |  | FLEXSPI2_A_DATA01
50 | EMC_28 | SEMC_WE | FLEXPWM1_PWMB02 | LPUART5_CTS_B | LPSPI1_SDO | FLEXIO1_FLEXIO14 | GPIO4_IO28 |  |  | FLEXSPI2_A_DATA02
51 | EMC_22 | SEMC_BA1 | FLEXPWM3_PWMB03 | LPI2C3_SCL | ENET_TDATA00 | QTIMER2_TIMER3 | GPIO4_IO22 |  |  | FLEXSPI2_A_SS1_B of
52 | EMC_26 | SEMC_CLK | FLEXPWM1_PWMB01 | LPUART6_RX | ENET_RX_ER | FLEXIO1_FLEXIO12 | GPIO4_IO26 |  |  | FLEXSPI2_A_DATA00
53 | EMC_25 | SEMC_RAS | FLEXPWM1_PWMA01 | LPUART6_TX | ENET_TX_CLK | ENET_REF_CLK | GPIO4_IO25 |  |  | FLEXSPI2_A_SCLK
54 | EMC_29 | SEMC_CS0 | FLEXPWM3_PWMA00 | LPUART6_RTS_B | LPSPI1_SDI | FLEXIO1_FLEXIO15 | GPIO4_IO29 |  |  | FLEXSPI2_A_DATA03
IOMUXC_xxx_SELECT_INPUT
Column1 | Column2 | Column3 | Column4 | Column5 | Column6 | Column7 | Column8 | Column9 | Column10 | Column11 | Column12
0 | AD_B0_03 | FLEXCAN2_RX | IOMUXC_XBAR1_IN17_SELECT_INPUT=0x1 | IOMUXC_LPUART6_RX_SELECT_INPUT=1 | USB_OTG1_OC | FLEXPWM1_PWMX01 | GPIO1_IO03 | REF_CLK_24M | LPSPI3_PCS0
1 | AD_B0_02 | FLEXCAN2_TX | XBAR1_INOUT16 | IOMUXC_LPUART6_TX_SELECT_INPUT=1 | USB_OTG1_PWR | LEXPWM1_PWMX0 | GPIO1_IO02 | LPI2C1_HREQ | LPSPI3_SDI
2 | EMC_04 | SEMC_DATA04 | FLEXPWM4_PWMA02 | SAI2_TX_DATA | IOMUXC_XBAR1_IN06_SELECT_INPUT=0x0 | FLEXIO1_FLEXIO04 | GPIO4_IO04
3 | EMC_05 | SEMC_DATA05 | FLEXPWM4_PWMB0 | SAI2_TX_SYNC | IOMUXC_XBAR1_IN07_SELECT_INPUT=0x0 | FLEXIO1_FLEXIO05 | GPIO4_IO05
4 | EMC_06 | SEMC_DATA06 | FLEXPWM2_PWMA00 | SAI2_TX_BCLK | IOMUXC_XBAR1_IN08_SELECT_INPUT=0x0 | FLEXIO1_FLEXIO06 | GPIO4_IO06
5 | EMC_08 | SEMC_DM00 | FLEXPWM2_PWMA01 | SAI2_RX_DATA | IOMUXC_XBAR1_IN17_SELECT_INPUT=0x0 | FLEXIO1_FLEXIO08 | GPIO4_IO08
6 | B0_10 | LCD_DATA06 | QTIMER4_TIMER1 | FLEXPWM2_PWMA02 | SAI1_TX_DATA03 | FLEXIO2_FLEXIO10 | GPIO2_IO10 | SRC_BOOT_CFG06 |  | ENET2_CRS
7 | B1_01 | LCD_DATA13 | XBAR1_INOUT15 | IOMUXC_LPUART4_RX_SELECT_INPUT=2 | SAI1_TX_DATA00 | FLEXIO2_FLEXIO17 | GPIO2_IO17 | FLEXPWM1_PWMB03 |  | ENET2_RDATA00 | FLEXIO3_FLEXIO17
8 | B1_00 | LCD_DATA12 | XBAR1_INOUT14 | IOMUXC_LPUART4_TX_SELECT_INPUT=2 | SAI1_RX_DATA00 | FLEXIO2_FLEXIO16 | GPIO2_IO16 | FLEXPWM1_PWMA03 |  | ENET2_RX_ER | FLEXIO3_FLEXIO16
9 | B0_11 | LCD_DATA07 | QTIMER4_TIMER2 | FLEXPWM2_PWMB02 | SAI1_TX_DATA02 | FLEXIO2_FLEXIO11 | GPIO2_IO11 | SRC_BOOT_CFG07 |  | ENET2_COL
10 | B0_00 | LCD_CLK | QTIMER1_TIMER0 | MQS_RIGHT | LPSPI4_PCS0 | FLEXIO2_FLEXIO00 | GPIO2_IO00 | SEMC_CSX01 |  | ENET2_MDC
11 | B0_02 | LCD_HSYNC | QTIMER1_TIMER2 | FLEXCAN1_TX | LPSPI4_SDO | FLEXIO2_FLEXIO02 | GPIO2_IO02 | SEMC_CSX03 |  | ENET2_1588_EVENT0_OUT
12 | B0_01 | LCD_ENABLE | QTIMER1_TIMER1 | MQS_LEFT | LPSPI4_SDI | FLEXIO2_FLEXIO01 | GPIO2_IO01 | SEMC_CSX02 |  | ENET2_MDIO
13 | B0_03 | LCD_VSYNC | QTIMER2_TIMER0 | FLEXCAN1_RX | LPSPI4_SCK | FLEXIO2_FLEXIO03 | GPIO2_IO03 | WDOG2_RESET_B_DEB |  | ENET2_1588_EVENT0_IN
14/A0 | AD_B1_02 | USB_OTG1_ID | QTIMER3_TIMER2 | IOMUXC_LPUART2_TX_SELECT_INPUT=1 | SPDIF_OUT | ENET_1588_EVENT2_OUT | GPIO1_IO18 | USDHC1_CD_B | KPP_ROW06 | GPT2_CLK | FLEXIO3_FLEXIO02
15/A1 | AD_B1_03 | USB_OTG1_OC | QTIMER3_TIMER3 | IOMUXC_LPUART2_RX_SELECT_INPUT=1 | SPDIF_IN | ENET_1588_EVENT2_IN | GPIO1_IO19 | USDHC2_CD_B | KPP_COL06 | GPT2_CAPTURE1 | FLEXIO3_FLEXIO03
16/A2 | AD_B1_07 | FLEXSPIB_DATA00 | LPI2C3_SCL | IOMUXC_LPUART3_RX_SELECT_INPUT=0 | SPDIF_EXT_CLK | CSI_HSYNC | GPIO1_IO23 | USDHC2_DATA3 | KPP_COL04 | GPT2_COMPARE3 | FLEXIO3_FLEXIO07
17/A3 | AD_B1_06 | FLEXSPIB_DATA01 | LPI2C3_SDA | IOMUXC_LPUART3_TX_SELECT_INPUT=0 | SPDIF_LOCK | CSI_VSYNC | GPIO1_IO22 | USDHC2_DATA2 | KPP_ROW04 | GPT2_COMPARE2 | FLEXIO3_FLEXIO06
18/A4 | AD_B1_01 | USB_OTG1_PWR | QTIMER3_TIMER1 | LPUART2_RTS_B | LPI2C1_SDA | CCM_PMIC_READY | GPIO1_IO17 | USDHC1_VSELECT | KPP_COL07 | ENET2_1588_EVENT0_IN | FLEXIO3_FLEXIO01
19/A5 | AD_B1_00 | USB_OTG2_ID | QTIMER3_TIMER0 | LPUART2_CTS_B | LPI2C1_SCL | WDOG1_B | GPIO1_IO16 | USDHC1_W | KPP_ROW07 | ENET2_1588_EVENT0_OUT | FLEXIO3_FLEXIO00
20/A6 | AD_B1_10 | FLEXSPIA_DATA03 | WDOG1_B | IOMUXC_LPUART8_TX_SELECT_INPUT=1 | SAI1_RX_SYNC | CSI_DATA07 | GPIO1_IO26 | USDHC2_WP | KPP_ROW02 | ENET2_1588_EVENT1_OUT | FLEXIO3_FLEXIO10
21/A7 | AD_B1_11 | FLEXSPIA_DATA02 | EWM_OUT_B | IOMUXC_LPUART8_RX_SELECT_INPUT=1 | SAI1_RX_BCL | CSI_DATA06 | GPIO1_IO27 | USDHC2_RESET_B | KPP_COL02 | ENET2_1588_EVENT1_IN | FLEXIO3_FLEXIO11
22/A8 | AD_B1_08 | FLEXSPIA_SS1_B | FLEXPWM4_PWMA00 | FLEXCAN1_TX | CCM_PMIC_READY | CSI_DATA09 | GPIO1_IO24 | USDHC2_CMD | KPP_ROW03 |  | FLEXIO3_FLEXIO08
23/A9 | AD_B1_09 | FLEXSPIA_DQS | FLEXPWM4_PWMA01 | FLEXCAN1_RX | SAI1_MCLK | CSI_DATA08 | GPIO1_IO25 | USDHC2_CLK | KPP_COL03 |  | FLEXIO3_FLEXIO09
24/A10 | AD_B0_12 | LPI2C4_SCL | CCM_PMIC_READY | LPUART1_TX | WDOG2_WDOG_B | FLEXPWM1_PWMX02 | GPIO1_IO12 | ENET_1588_EVENT1_OUT | NMI_GLUE_NMI
25/A11 | AD_B0_13 | LPI2C4_SDA | GPT1_CLK | LPUART1_RX | EWM_OUT_B | FLEXPWM1_PWMX03 | GPIO1_IO13 | ENET_1588_EVENT1_IN | REF_CLK_24M
26/A12 | AD_B1_14 | FLEXSPIA_SCLK | ACMP_OUT02 | LPSPI3_SDO | SAI1_TX_BCLK | CSI_DATA03 | GPIO1_IO30 | USDHC2_DATA6 | KPP_ROW00 | ENET2_1588_EVENT3_OUT | FLEXIO3_FLEXIO14
27/A13 | AD_B1_15 | FLEXSPIA_SS0_B | ACMP_OUT03 | LPSPI3_SCK | SAI1_TX_SYNC | CSI_DATA02 | GPIO1_IO31 | USDHC2_DATA7 | KPP_COL00 | ENET2_1588_EVENT3_IN | FLEXIO3_FLEXIO15
28 | EMC_32 | SEMC_DATA10 | FLEXPWM3_PWMB01 | IOMUXC_LPUART7_RX_SELECT_INPUT=1 | CCM_PMIC_RDY | CSI_DATA21 | GPIO3_IO18 |  |  | ENET2_TX_EN
29 | EMC_31 | SEMC_DATA09 | FLEXPWM3_PWMA01 | OMUXC_LPUART7_TX_SELECT_INPUT=1 | LPSPI1_PCS1 | CSI_DATA22 | GPIO4_IO31 |  |  | ENET2_TDATA01
30 | EMC_37 | SEMC_DATA15 | IOMUXC_XBAR1_IN23_SELECT_INPUT=0x0 | GPT1_COMPARE3 | SAI3_MCLK | CSI_DATA16 | GPIO3_IO23 | USDHC2_WP |  | ENET2_RX_EN | FLEXCAN3_RX
31 | EMC_36 | SEMC_DATA14 | IOMUXC_XBAR1_IN22_SELECT_INPUT=0x0 | GPT1_COMPARE2 | SAI3_TX_DATA | CSI_DATA17 | GPIO3_IO22 | USDHC1_WP |  | ENET2_RDATA01 | FLEXCAN3_TX
32 | B0_12 | LCD_DATA08 | XBAR1_INOUT10 | ARM_TRACE_CLK | SAI1_TX_DATA01 | FLEXIO2_FLEXIO12 | GPIO2_IO12 | SRC_BOOT_CFG08 |  | ENET2_TDATA00
33 | EMC_07 | SEMC_DATA07 | FLEXPWM2_PWMB00 | SAI2_MCLK | IOMUXC_XBAR1_IN09_SELECT_INPUT=0x0 | FLEXIO1_FLEXIO07 | GPIO4_IO07
34 | B1_13 | WDOG1_B | IOMUXC_LPUART5_RX_SELECT_INPUT=1 | CSI_VSYNC | ENET_1588_EVENT0_OUT | FLEXIO2_FLEXIO29 | GPIO2_IO29 | USDHC1_WP |  | SEMC_DQS4 | FLEXIO3_FLEXIO29
35 | B1_12 |  | IOMUXC_LPUART5_TX_SELECT_INPUT=1 | CSI_PIXCLK | ENET_1588_EVENT0_IN | FLEXIO2_FLEXIO28 | GPIO2_IO28 | USDHC1_CD_B |  |  | FLEXIO3_FLEXIO28
36 | B1_02 | LCD_DATA14 | XBAR1_INOUT16 | LPSPI4_PCS2 | SAI1_TX_BCLK | FLEXIO2_FLEXIO18 | GPIO2_IO18 | FLEXPWM2_PWMA03 |  | ENET2_RDATA01 | FLEXIO3_FLEXIO18
37 | B1_03 | LCD_DATA15 | IOMUXC_XBAR1_IN17_SELECT_INPUT=0x3 | LPSPI4_PCS1 | SAI1_TX_SYNC | FLEXIO2_FLEXIO19 | GPIO2_IO19 | FLEXPWM2_PWMB03 |  | ENET2_RX_EN | FLEXIO3_FLEXIO19
38/A14 | AD_B1_12 | FLEXSPIA_DATA01 | ACMP_OUT00 | LPSPI3_PCS0 | SAI1_RX_DATA00 | CSI_DATA05 | GPIO1_IO28 | USDHC2_DATA4 | KPP_ROW01 | ENET2_1588_EVENT2_OUT | FLEXIO3_FLEXIO12
39/A5 | AD_B1_13 | FLEXSPIA_DATA00 | ACMP_OUT01 | LPSPI3_SDI | SAI1_TX_DATA00 | CSI_DATA04 | GPIO1_IO29 | USDHC2_DATA5 | KPP_COL01 | ENET2_1588_EVENT2_IN | FLEXIO3_FLEXIO13
40/A16 | AD_B1_04 | FLEXSPIB_DATA03 | ENET_MDC | LPUART3_CTS_B | SPDIF_SR_CLK | CSI_PIXCLK | GPIO1_IO20 | USDHC2_DATA0 | KPP_ROW05 | GPT2_CAPTURE2 | FLEXIO3_FLEXIO04
41/A17 | AD_B1_05 | FLEXSPIB_DATA02 | ENET_MDIO | LPUART3_RTS_B | SPDIF_OUT | CSI_MCLK | GPIO1_IO21 | USDHC2_DATA1 | KPP_COL05 | GPT2_COMPARE1 | FLEXIO3_FLEXIO05
42 | SD_B0_03 | USDHC1_DATA1 | FLEXPWM1_PWMB01 | LPUART8_RTS_B | IOMUXC_XBAR1_IN07_SELECT_INPUT=0x1 | LPSPI1_SDI | GPIO3_IO15 |  |  | ENET2_RDATA00 | SEMC_CLK6
43 | SD_B0_02 | USDHC1_DATA0 | FLEXPWM1_PWMA01 | LPUART8_CTS_B | IOMUXC_XBAR1_IN06_SELECT_INPUT=0x1 | LPSPI1_SDO | GPIO3_IO14 |  |  | ENET2_RX_ER | SEMC_CLK5
44 | SD_B0_01 | USDHC1_CLK | FLEXPWM1_PWMB00 | LPI2C3_SDA | IOMUXC_XBAR1_IN05_SELECT_INPUT=0x1 | LPSPI1_PCS0 | GPIO3_IO13 | FLEXSPIB_SS1_B |  | ENET2_TX_CLK | ENET2_REF_CLK2
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

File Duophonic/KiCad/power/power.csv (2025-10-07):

Id | Designator | Footprint | Quantity | Designation | Supplier and ref
1 | C6,C4,C9 | C_1206_3216Metric_Pad1.33x1.80mm_HandSolder | 3 | 10nF
2 | R1,R7,R3 | R_0805_2012Metric_Pad1.20x1.40mm_HandSolder | 3 | 47k
3 | U3,U1 | SO-8_3.9x4.9mm_P1.27mm | 2 | LT1763CS8
4 | C8,C7,C5 | C_1206_3216Metric_Pad1.33x1.80mm_HandSolder | 3 | 10uF X7R
5 | R8,R4 | R_0805_2012Metric_Pad1.20x1.40mm_HandSolder | 2 | 6k98
6 | R2 | R_0805_2012Metric_Pad1.20x1.40mm_HandSolder | 1 | 13k3
7 | U2 | SOT-23-5 | 1 | LT1964ES5-BYP
8 | C3,C2 | CP_Radial_D6.3mm_P2.50mm | 2 | 22uF 25V Nichicon
9 | J1 | Pins_2x08_2.54mm_TH_EuroPower_Shrouded_reducedsilk | 1 | Eurorack_Power_16pin_Shrouded
10 | J8,J5,J2,J7,J4,J3,J6 | PinHeader_1x04_P2.54mm_Vertical | 7 | Conn_01x04_Pin
11 | C1 | CP_Radial_D6.3mm_P2.50mm | 1 | 68uF 25V Nichicon

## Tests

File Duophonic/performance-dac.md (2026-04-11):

# Performance (Control Change) DAC

One octal 14-bit DAC does 2 voices  of attack veocity, lift velocity, pressure, glide. High Resolution Velocity prefix supported.

*Note* final MPE specification reduces precision of pressure & glide to 7bit. However, later expansion to 14bit not ruled out. Implement 14bit as an experiment; 7bit still supported. See [MIDI](./MIDI.md) on precision, smoothing and update rate.

Similar circuitry also used to provide the global performance controls (mod wheel, sustain, etc). Can support 14-bit MSB/LSB Control Change, and also RPN and NRPN.

## Chip selection

Needs to be 14-bit capable to fully implement the HR aspect, but precision requirement lower than for pitch; most devices send 7bit data and the ones that are high resolution have ENOB less than 14. 1 LSB at 14bit is 300μV but 1 LSB at 7bit is a huge 39mV. Aim for at least 10 ENOB (4.8mV), preferably 12 ENOB (1.2mV).

_AD5648-2_ octal 14-bit DAC ($19.91, got one) NO unsuitable due to zero and gain offsets. Internal VRef of 2.5V gives unipolar 5V output. Better performance from the -2 devices at 5V than the -1 devices at 3V3. Fig. 31 shows **100mV** (!!) error when sourcing or sinking 2mA. Internal 2V5 reference with 2x gain, can use external (5V) ref. Notice most of the graphs in datasheet use an external reference :)
Vref seems to give a couple of mV error in output wrt temperature. Fig.54 shows 4mV error in internal ref wrt temperature.

**DAC8168C** (or DAC8168ICPW  seems more available) octal 14-bit DAC (TSSOP-16, $27.26, **got 3, 4 Jan 2018** ) much better offsets ±1 / ±4 mV.

(_Note to self:_ This is the 14-bit version of the DAC8568 which I used in another  (mainly through-hole) project, OctalDAC wavemix).

TSSOP-14 DAC has neither CLR nor LDAC, only needs 3 lines through level shifter. However best (C) grade is TSSOP-16.

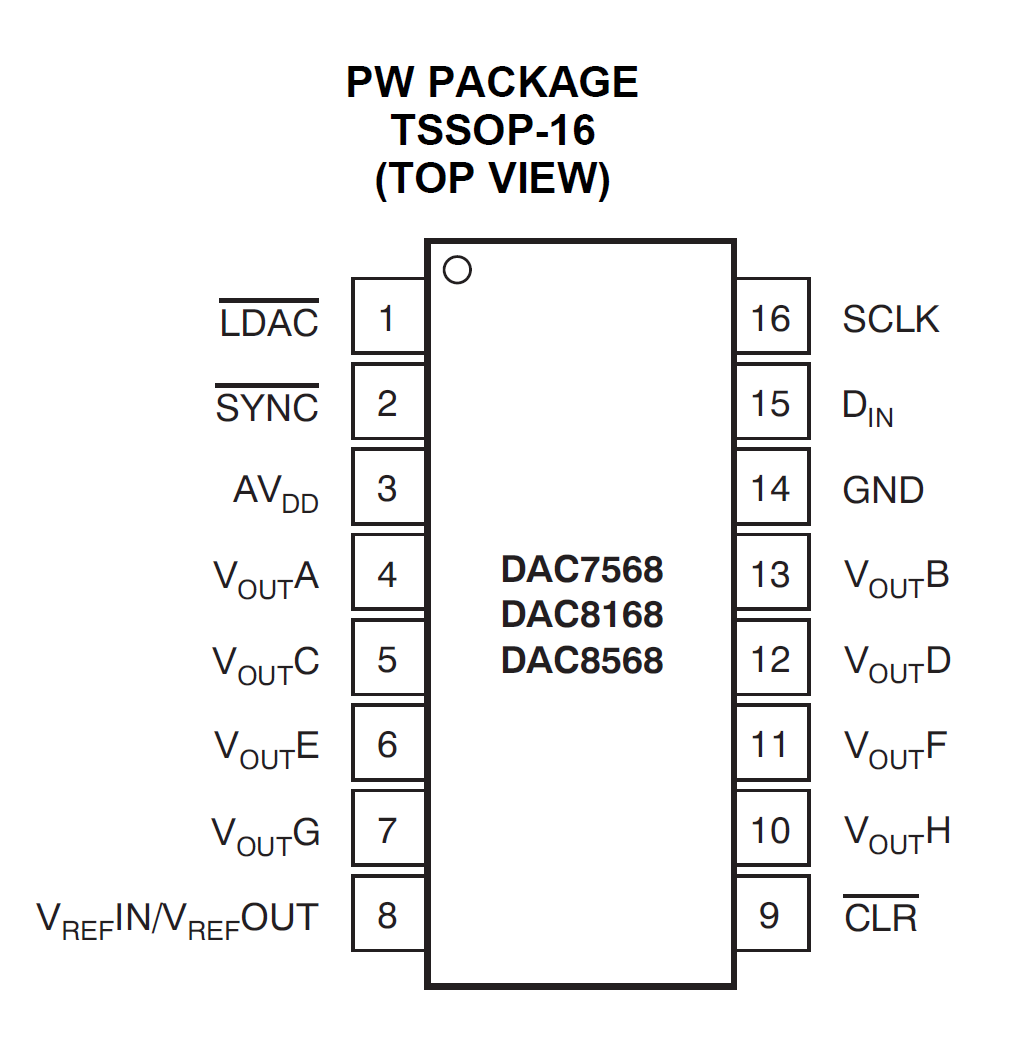
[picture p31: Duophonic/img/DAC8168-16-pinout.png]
DAC


## Power

Clean 5.5V. Most graphs in datasheet are at AVdd =  5.5V.

## Digital interface

Logic level high is 0.625 * Vdd so 3.4V, ie it is a 5V logic device with that Vdd.

Needs level shifter for SPI. Use second SPI channel on Teensy 4.1. One quad shifter handles CS (SYNC) plus SCLK and MOSI and optionally LDAC.

**74AHCT125** Quad Level-Shifter (SSOP-14, **got 10 Jan 2018** plus 10 DIP)  good for SPI, fast enough.
Vdd abs max -0.5V to +7V so good for 5V5.

Enables are active low, so tie all to ground.

[Check for MISO tri-state behavior](https://www.pjrc.com/better-spi-bus-design-in-3-steps/) with a pair of 10 resistors.

## Vref

DAC8168C Internal 2.5V VRef has initial accuracy of 100μV (0.004%), good temperature stability (especially 2x gain C grade) and long-term drift. External Vref not needed.
Internal Vref in DAC8168C is adequate for general non-pitch CV duties. Output is 0 to 5V.
Note internal Vref is disabled by default, see datasheet Table 5 for enable command.

## Initial accuracy

From **DAC8168C** datasheet, assuming internal Vref:

INL 300μV / 1.2mV (±1 / ±4 LSB, typ / max)

DNL 30μV / 150μV (±0.1 / ±0.5 LSB)

Gain error 0.5mV / 7.5mV (±0.01% / ±0.15% of FSR) with  5μV (±1 ppm of FSR)/°C drift

Offset error ±1 / ±4 mV with ±0.5 μV/°C drift

Zero error 1mV / 4mV with  ±2 μV/°C drift

At 0 to 5V, 1LSB is 306μV. TL071 with 3mV offset is now significant wrt typical (but not max) offsets.

DAC is not trimmable without external conditioning circuitry.

Long term drift (Fig.7) inside ±500μV (±100ppm) /2k hours

## Line regulation

10μV/V is fine here

"The power applied to AVdd should be well-regulated and low noise. Switching power supplies and dc/dc converters often have high-frequency glitches or spikes riding on the output voltage. In addition, digital components can create similar high-frequency spikes as their internal logic switches states. This noise can easily couple into the DAC output voltage through various paths between the power connections an analog output"

So powering from the analog, regulated 5V5 supply helps here.

## Load

30μV/mA (sourcing)

Internally buffered, but _poor_ load regulation; will need external buffer to protect from modular environment (like getting 12V plugged into an output by mistake), to provide a constant high-impedance load for the DAC, and to give current drive with low output impedance.

> **8.2.3 Output Amplifier**
> The output buffer amplifier is capable of generating rail-to-rail voltages on its output, giving a maximum output range of 0V to AVDD. It is capable of driving a load of 2kΩ in parallel with 3000pF to GND. The source and sink capabilities of the output amplifier can be seen in the Typical Characteristics. The typical slew rate is 0.75V/μs, with a typical full-scale settling time of 5μs with the output unloaded.

## Support circuitry

4.7μF + 100nF supply bypass caps on AVdd.

> a 1μF to 10μF capacitor and 0.1μF bypass capacitor are strongly recommended.

Optional 150nF cap for lower noise on Vref (likely not needed, but place footprint on board).

## Output conditioning

3mV offset on TL074B is 3LSB; not that significant, though if an inexpensive alternative op-amp is better (1mV or less, does not need to be high precision) use that.

Quad amps: TL074A is cheap (TL074ACDT 3mV/6mV, $0.867/10) but consider **OPA4172IPW** (200μV/1mV, 10 V/μs, 75mA 60Ω, $3.32/10, TSSOP-14, currently in stock) or **OPA4197ID** (25μV/100μV, 20 V/μs, $3.53/10 **GOT 10**), **OPA4202ID** (20μV/250μV, low slew rate 0.35V/μs, $2.81/10 SOIC-14 in stock) as non-inverting output buffers. Use innie current limiting resistor.

OR to save needing bipolar power, use quad RRIO low voltage single-supply op-amps. Key features are swing to 0V (sing to positive rail not an issue due to 5V signal from DC nd 5V5 rail), current drive, offset. Must allow 5V5 rail. Must be unity gain stable.

| Op-amp | Swing | Offset (typ/max) | Price |
|:---|---|---|---|
| TLV4316 | -/35 mV  | ±0.75/±3 mV | **$1.06/10** |
| OPA4340UA | 1/5 mV | ±150/±500 μV | **$7.22/1**  |

Note [OPA4340UA](https://www.mouser.com/ProductDetail/Texas-Instruments/OPA4340UA?qs=wgAEGBTxy7nRw0DNGsw%252Bcg%3D%3D) has both _abs max_ and _recommended_ supply rail at 5V5. Much better swing to rail, 6x lower offset, 7x the price. Somewhat worse swing if load is below 50 kΩ, which is easily possible:

> A class AB output stage with common-source transistors is used to achieve rail-to-rail output. For light resistive loads (> 50 kΩ), the output voltage is typically a few millivolts from the supply rails. With moderate resistive loads (2 kΩ to 50 kΩ), the output can swing to within a few tens of millivolts from the supply rails and maintain high open-loop gain (see Figure 15).

Not exactly clear what they are dodging around, here:

> The OPA340 series operational amplifiers are fully specified from 2.7 V to 5 V. However, supply voltage may range from 2.5 V to 5.5 V. Parameters are ensured over the specified supply range—a unique feature of the OPA340 series.

DAC settling time, 1/4 scale to 3/4 scale is 10μs typ, so 20μs full scale and 40μs for fastest possible square wave = 25kHz in theory (will be slower). Spec sheet slew rate is 0.75 V/μs.

Better to use a slew limiter or low-pass filter on the output to avoid stair-stepping and VCA crackles; so one quad op-amp only does for 2 outputs. See circuit in TI [Single Op-Amp Slew Rate Limiter](http://www.ti.com/lit/pdf/TIDU026) for slew limiter. Needs fast recovery from overload, adequate slew rate. 5V/ms (160Hz lowpass) seems like a good starting point. Breadboard then examine stepped ramp on scope to determine optimal slew rate. "Op-amp slew rate = 10x-100x slew rate limiter value." OPA4202 likely too slow.
OPA4192 out of stock at Mouser. OPA4187?? (0.2V/μs $5.60/10 in stock) seems over-specified for Vos, slow slew, and expensive

OR do slew in software so it is configurable and can be disabled for true 14bit inputs.
Uses half the amount of op-amps (one per output). Needs testing. Use [ellapsedMicros](https://www.pjrc.com/teensy/td_timing_elaspedMillis.html) variables to update DAC on a regular clock, eg 10kHz. Interleave the updates for the two DACs so they don't coincide.

Capture some MIDI output from the Roli Seaboard to see what rate of changes is sent on changes in pressure etc; suspect it is fairly slow (and 7bit).

Test using pitch bend, or slow filter sweeps with some resonance

Remember same board is used for the analog general CC CV section, so also capture some data on that (mod wheel, breath, etc). Some of these are 14bit CC:

- Modulation Wheel (CC01+CC33)
- Breath (CC02+CC34)
- Expression Controller (CC11+CC43)

might also be driven by 14bit NRPN. Avoid over-slewing on 14bit inputs, which argues for software limiting.

- [Mathematical analysis of lag/slew](https://modwiggler.com/forum/viewtopic.php?t=270580&sid=4bbb23507cc03653a38cad97c82f4882)
- [my slew rate question on MW in 2018](https://modwiggler.com/forum/viewtopic.php?t=202240)
- [interpolation in midi-vs-cv](https://www.elektronauts.com/t/midi-vs-cv/156000/123)
- [zipper noise in MIDI to CV](https://gearspace.com/board/electronic-music-instruments-and-electronic-music-production/718498-zipper-noise-kenton-pro-2000-mkii.html)
- [MIDI vs I2C CV control on Haken Continuum driving Moog Voyager](https://www.hakenaudio.com/voltage-converter) notes excessive smoothing in Moog MIDI to CV generation limits expressive attack

Bipolar operation is possible (datasheet p.47) but not needed here, all the MIDI CC are unipolar for the MPE performance controls. So *could* use singe-rail, rail-to-rail input and output op-amps which swing to 0V on input and output. Probably easier to use bipolar devices though.

Given wide variety of op-amp capabilities, fluctuating pricing and wildly varying lead times and availability, split perf dac board into the DAC part and the buffer/slew part so one can be built with cheap parts then another with better parts, for testing and to avoid replacing the DAC. Standardize on one op-amp footprint, so SOIC-14 quad or TSSOP-14 quad.

Op-amp board needs bipolar supply OR R/R in and out op-amps to ensure accurate 0V. Bipolar is easier. Check CMRR though.

## Code

SPI Mode 1, MSBFIRST

Enable internal ref (disabled by default) in setup: command 090A0000h.

Then use broadcast mode to set all channels to zero (but zero is the C-grade power-on default).

See [32bit SPI to DAC8168](https://forum.pjrc.com/threads/72317-Dac8568-gt-dac8168?p=321896&viewfull=1#post321896) using SPI.transfer32()

[Asynchronous writes to multiple SPI channels](https://forum.pjrc.com/threads/61676-SPI-pins-teensy-4-1?p=245308&viewfull=1#post245308)

```C++
#define PerfDAC_CS1 32
#define PerfDAC_CS2 31
#define PerfDAC_CS3 30
#define PerfDAC_MOSI1 26
#define PerfDAC_SCLK1 27
pinMode(PerfDAC_CS1, OUTPUT);
pinMode(PerfDAC_CS2, OUTPUT);
pinMode(PerfDAC_CS3, OUTPUT);
SPI1.beginTransaction(SPISettings(24000000, MSBFIRST, SPI_MODE1));
```

There is an [existing library for the same-family DAC8568 (16 bit)](https://github.com/fuchsat93/teensy-dac8568) which can be configured for DC8168. Also some [working code](https://forum.pjrc.com/index.php?threads/interfacing-with-ti-dac856x-dac816x-or-dac756x.26974/#post-57321).

And for comparison [a Rust library](https://github.com/ost-ing/dac8568/blob/main/README.md)

## Fading (all voice 'attenuators')

(Not on same board).

Use 4 pots with rail-to-rail input and output buffer amps connected to 4 adc inputs. Teensy 4.1 only has 10bit (enob) ADC. Then use these values to digitally scale the 14bit performance values (on *all* voices), providing per-performance-output attenuator function across all channels.

Experiment to see if buffering is needed. 10k pots should be low enough to drive ADC but check current draw of 4 in parallel (1.3mA, seems fine).

Allow a dead zone at each end so easy to get "fully off" or "fully on" values. Experiment with curve between the two extremes, linear is probably not what is wanted here.

- [Alpha 9mm T18 shaft pot, 10k](https://www.thonk.co.uk/shop/alpha-9mm-pots-vertical-t18/) [GOT]
- [T18 micro knobs](https://www.thonk.co.uk/shop/micro-knobs/) [GOT]

 Use Responsive Analog Read:

- [Writing a better noise-reduction algorithm](http://damienclarke.me/code/posts/writing-a-better-noise-reducing-analogread)
- [RAR on GitHub](https://github.com/dxinteractive/ResponsiveAnalogRead)
- [Example responsive analog read](https://forum.pjrc.com/threads/45376-Example-code-for-MIDI-controllers-with-Pots-and-Buttons)

May need buffering, though this project does not need a fast rate of reading these pots. Would use a 3V3 RR-I/O op-amp.

"It is advisable to place a 10nF capacitor from the wiper to ground against RF and other interference." [Gerrit, PJRC forum](https://forum.pjrc.com/threads/55126-MIDI-Faderbox-fader-choice?p=197818&viewfull=1#post197818)

[Discussion of ADC input capacitance, SPICE models](https://forum.pjrc.com/index.php?threads/some-comments-on-circuits-using-the-analog-input.75431/#post-346211)

Maybe use [elapsedMillis](https://www.pjrc.com/teensy/td_timing_elaspedMillis.html) to only ready the pots every so often.

## Board

Three separate boards, stacking and parallel to panel, for:

- DAC and level shifter (5V5 power)
- op-amp buffers/slew (±12V power, now changed to 5V5 power)
- jacks

SYNC is active-low CS. Din is MOSI. SCLK is SCLK :)
Synchronous update mode so LDAC tied to GND.
But check this allows updating only some channels, not (re)writing to them all.
Better to bring out LDAC through level shifter so there is flexibility on controlling it from Teensy or tying low permanently.

### DAC board

#### Schematic v0.1

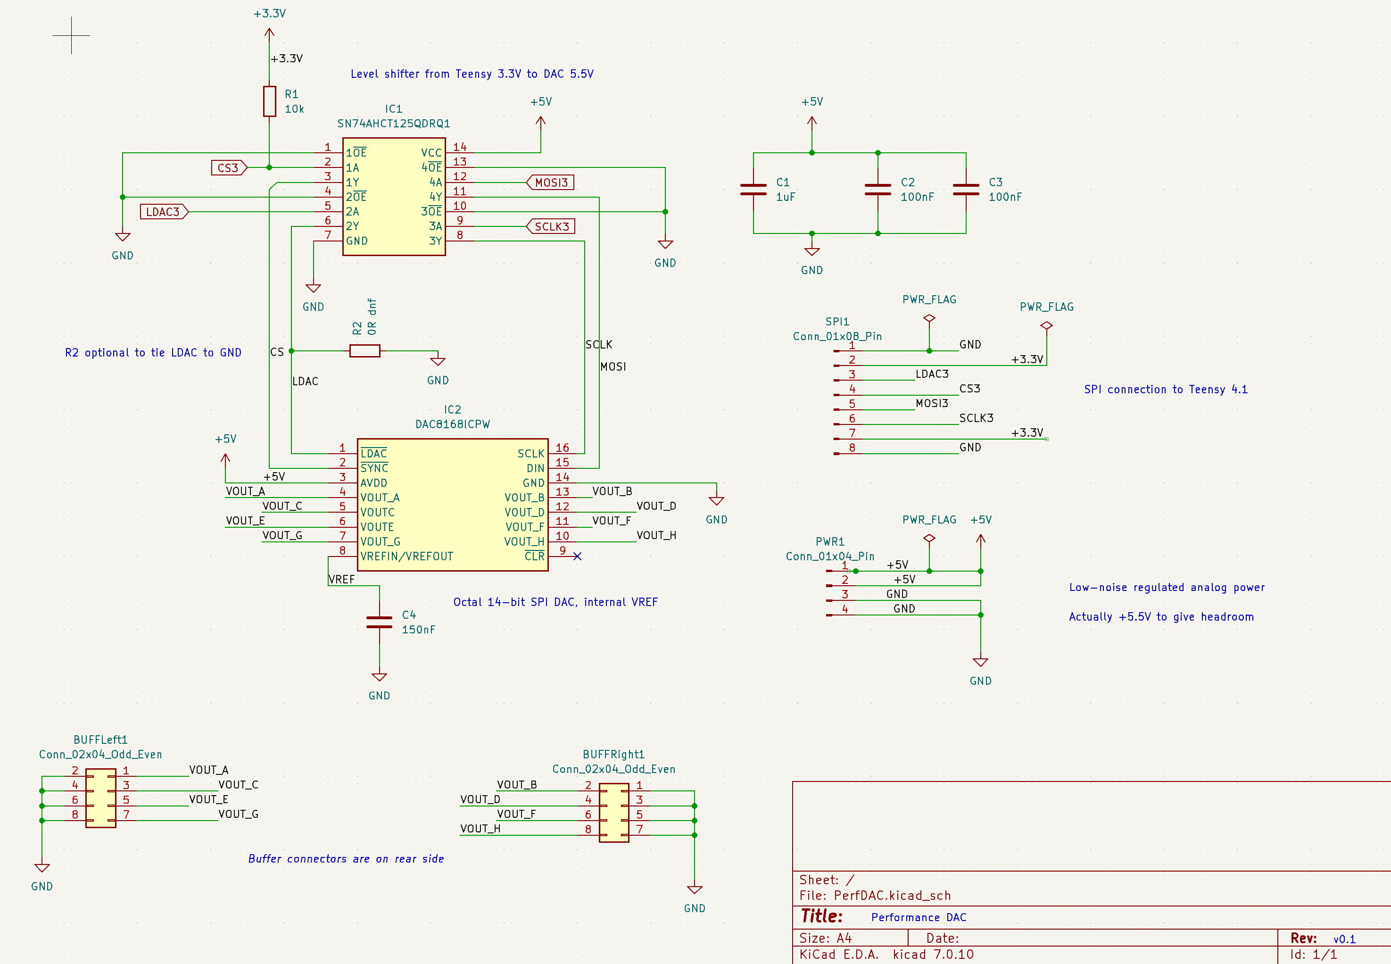
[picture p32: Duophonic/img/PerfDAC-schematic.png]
Schematic


#### DAC PCB v0.1

> We detected a 2 layer board of 1.33 x 1.03 inches (33.8 x 26.3mm)
> 3 boards will cost $6.85

Board ordered 29 Jan 2024

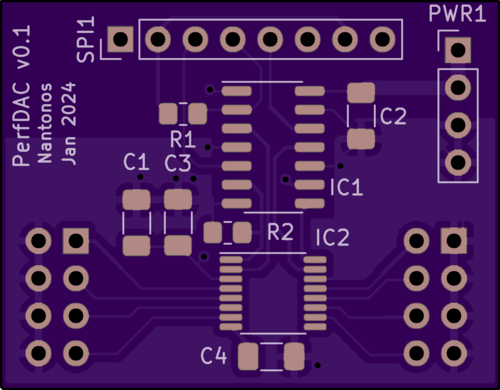
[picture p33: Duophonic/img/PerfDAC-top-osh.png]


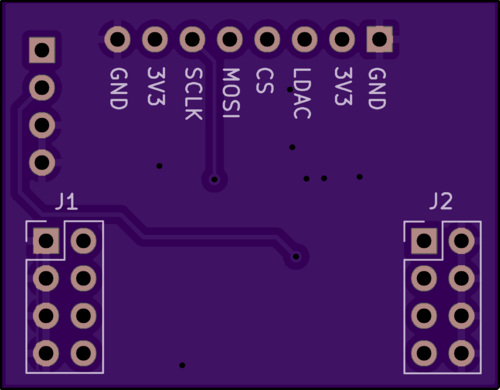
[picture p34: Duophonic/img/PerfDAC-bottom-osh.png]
bottom


3D views, front and back

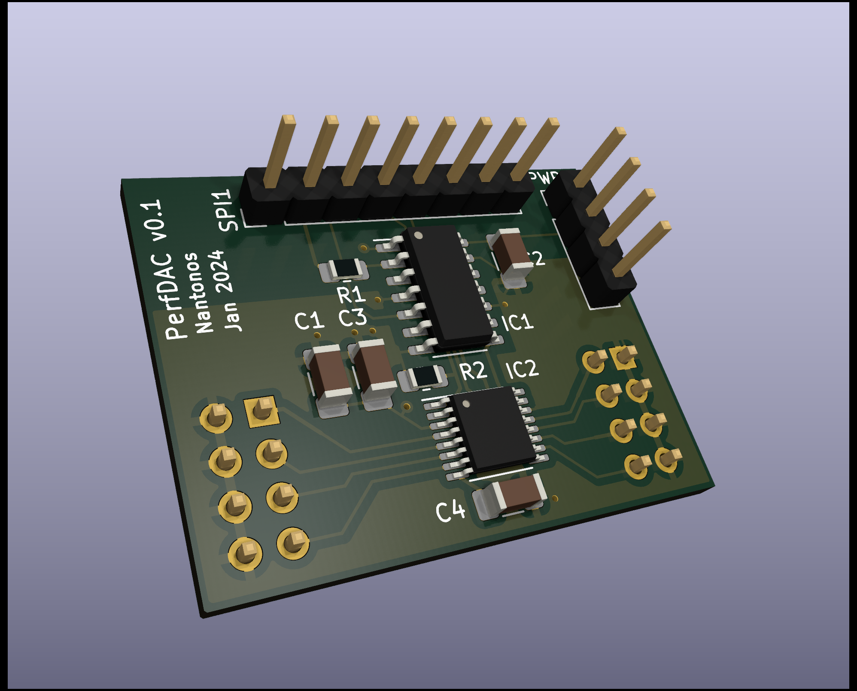
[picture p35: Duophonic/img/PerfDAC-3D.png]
3D


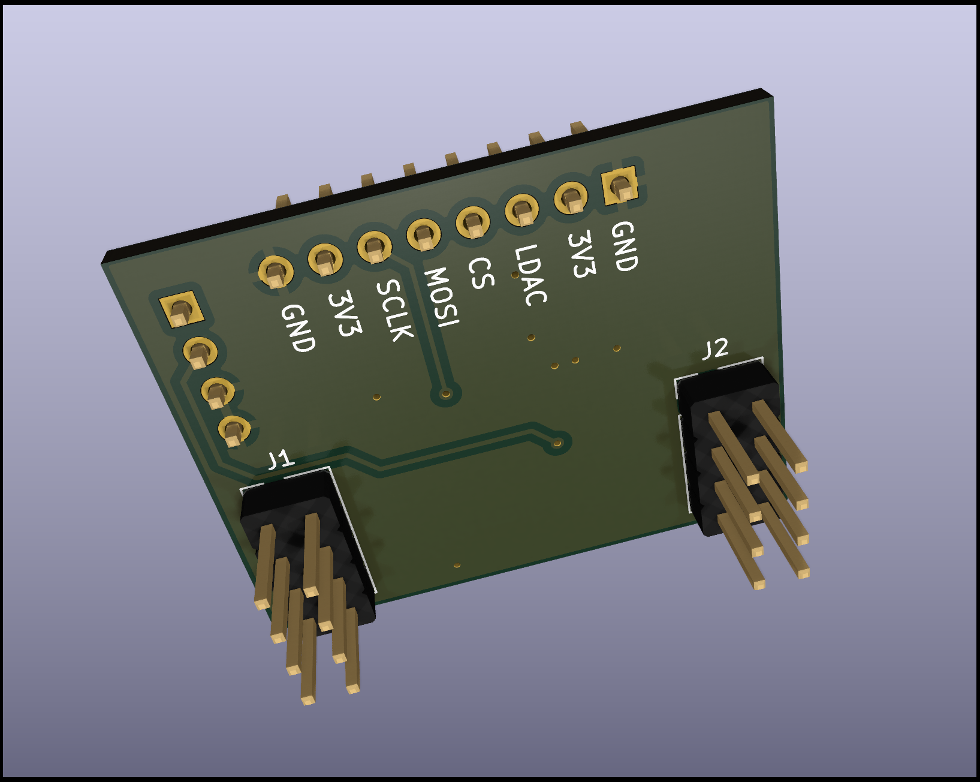
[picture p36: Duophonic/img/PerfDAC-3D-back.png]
3D back


_Notice that the buffer board connections are on the other side of the board!_

This board will not fit. Needs a v0.2 with the connectors staggered, see buffer board. However, still build one for testing.

#### Schematic v0.2

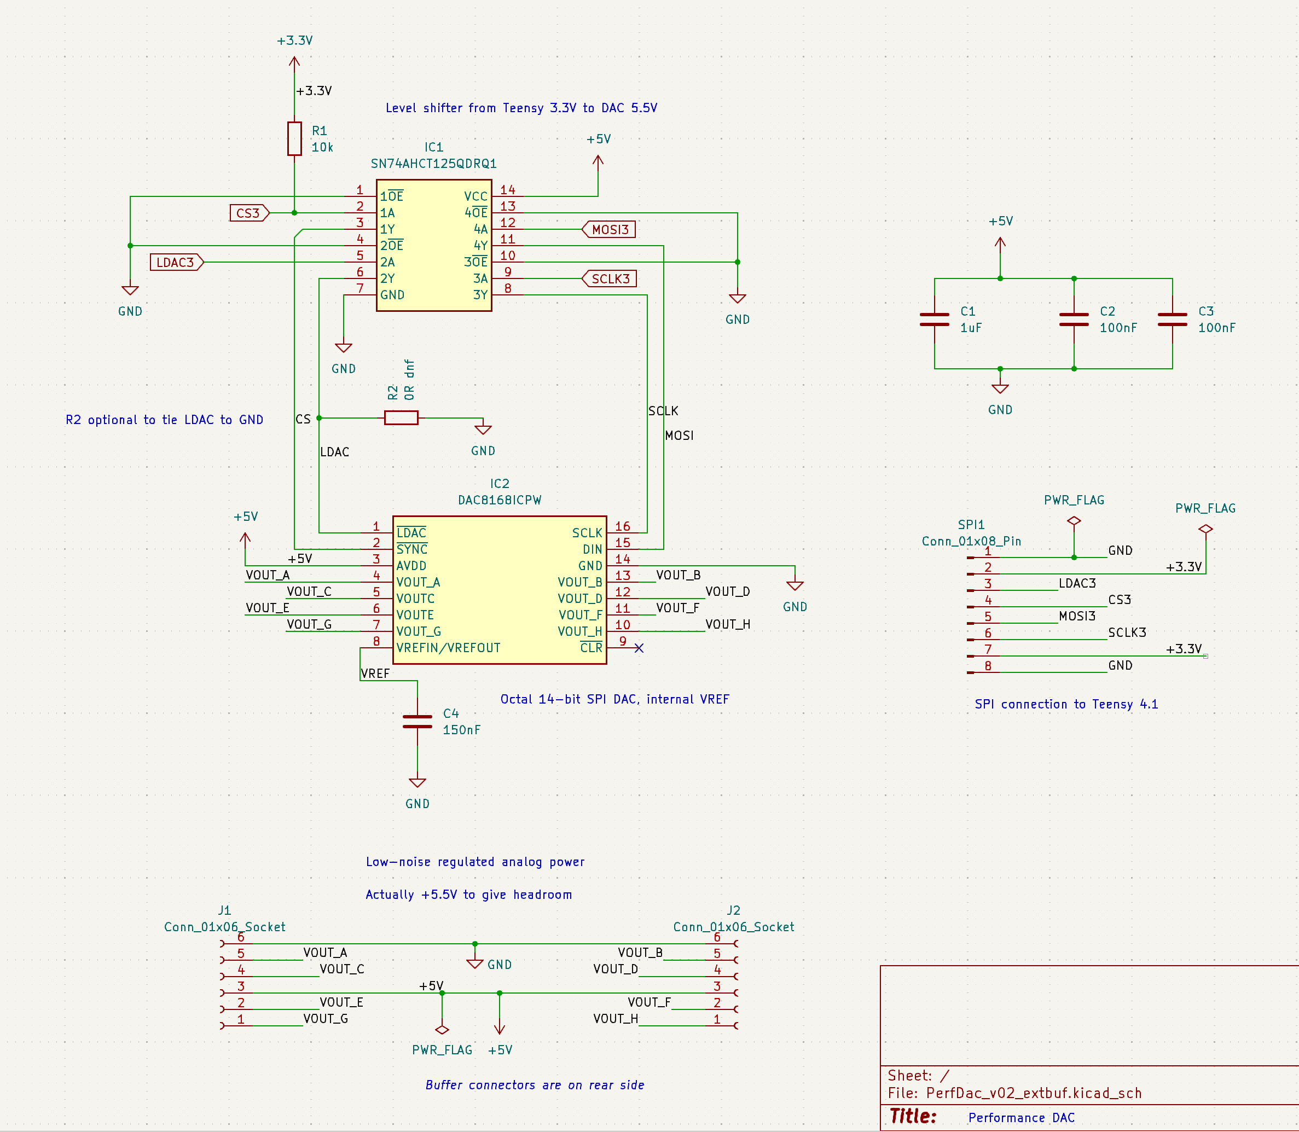
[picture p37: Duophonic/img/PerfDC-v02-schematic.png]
Schematic
 [PDF](./perfdac-v02-schematic.pdf)

#### DAC PCB v0.2

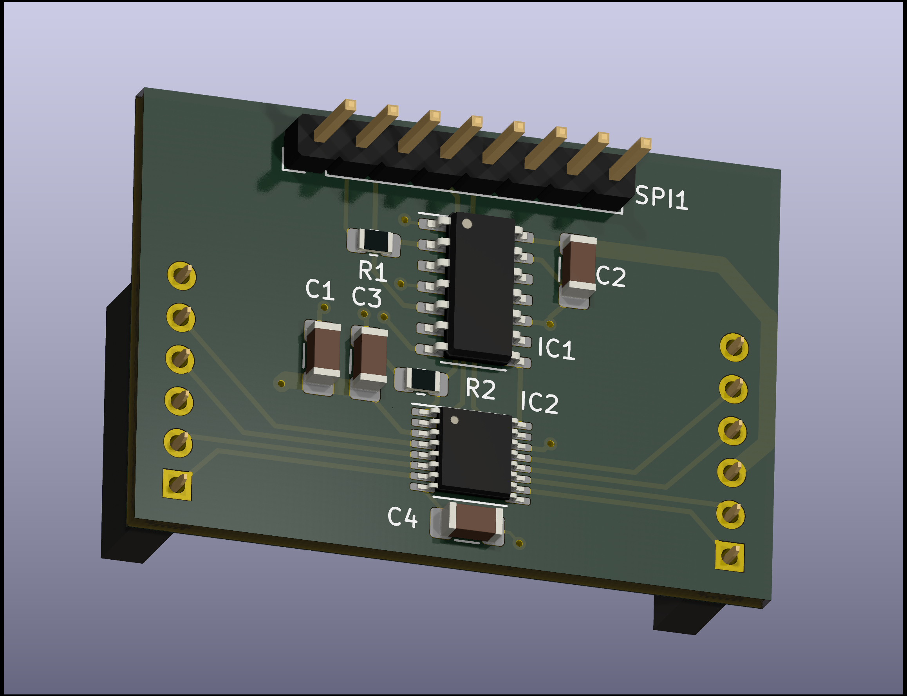
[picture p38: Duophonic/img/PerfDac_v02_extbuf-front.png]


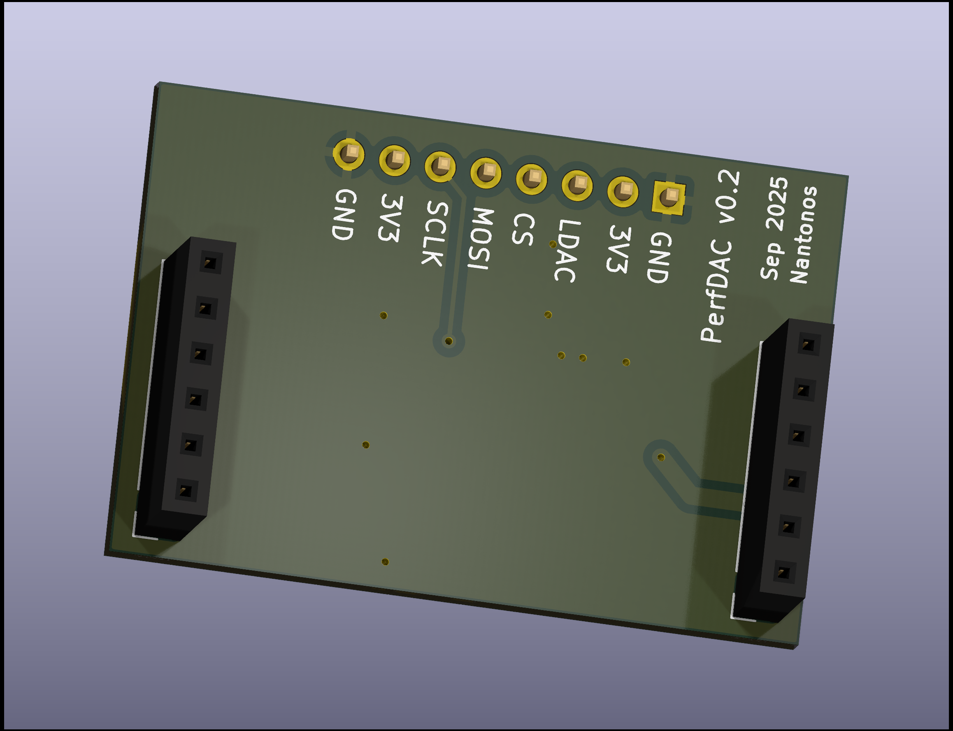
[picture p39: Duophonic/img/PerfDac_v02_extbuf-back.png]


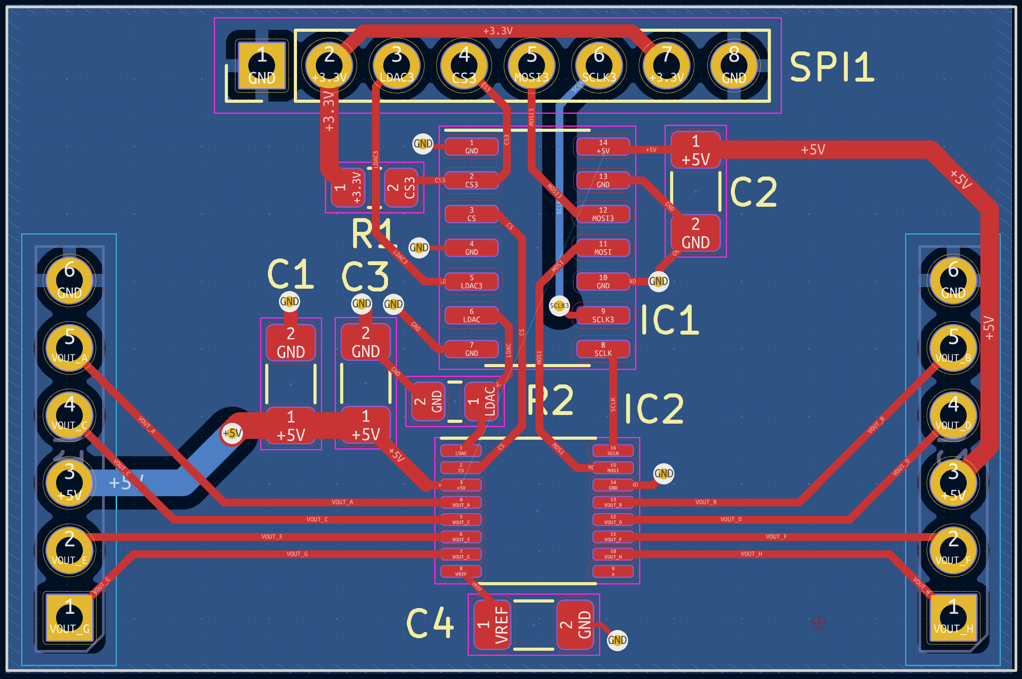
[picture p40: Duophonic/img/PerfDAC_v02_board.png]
board


> We detected a 2 layer board of 1.50 x 0.98 inches (38.0 x 25.0mm)
> 3 boards will cost $7.35

Board and stencil ordered OSH Park 18 Feb 2026

### DAC BOM v0.1 and v0.2 (per DAC board, need 2)

#### Resistors

(1) R1 10k 0805 any tolerance **GOT**
(1) R2 0R 0805 or solder bridge, optional (**GOT**)

#### Capacitors

(1) C1 Kemet C1206X105K3RACTU  25V 1μF X7R 10% 1206 ceramic $0.839/10 = **$8.39 GOT**
or
(1) [Kemet C1206C475K3RACTU](https://www.mouser.com/ProductDetail/KEMET/C1206C475K3RACTU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) 25V 4.7μF X7R 10% 1206 MLCC $0.156/10 =  **$1.56**

(2) C2, C3 Kemet C1206C104K3GEC7210 25V 100nF C0G 1206 ceramics $0.051/100 = **$5.10 GOT**

(1) C4  [Murata GRM31C5C1H154JE02L](https://www.mouser.com/ProductDetail/Murata-Electronics/GRM31C5C1H154JE02L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) 50V 0.15μF 1206 C0G $0.241/10 = **$2.41** ordered 10, 13 Mar 2026

spec sheet says **150nF or higher** and fig 8 shows 4.8μF so try 470nF?

OR

(1) C4 [Murata GRM31C5C1E474JE01L](https://www.mouser.com/ProductDetail/Murata-Electronics/GRM31C5C1E474JE01L?qs=hd1VzrDQEGj8GOC097EZLg%3D%3D) 25V 470nF C0G 1206 $0.429/10 = **$4.29** ordered 10, 13 Mar 2026

#### DAC

(1) DAC8168ICPW  14-bit octal $28.34/1 = **$28.34 GOT** but _lost_, ordered 3 more 13 Mar 2026

#### Logic

(1) [SN74AHCT125QDRQ1](https://www.mouser.com/ProductDetail/Texas-Instruments/SN74AHCT125QDRQ1?qs=zhgwDAIOVxtE5BLiD9k5oQ%3D%3D) Quad bus buffer $0.385/10 = **$3.85 GOT**

### Buffer board

Eight identical copies of this:

one buffer

Because of limited board space, the buffer board takes 5V5 from the power board then passes it on to the v0.2 DAC board.

 > We detected a 2 layer board of 1.83 x 0.92 inches (46.5 x 23.4mm)
> 3 boards will cost $8.40

buffer board

board 3d front

board 3d back

- Two rows of connectors to jacks board are 40.894mm apart, measured from the connector centres.
- Two rows of connectors to DAC board are 33.274mm apart.

Ordered from OSH Park 19 May 2025.

### Buffers BOM

#### Op Amps

(2) [OPA4340UA SOIC-14](https://www.mouser.com/ProductDetail/Texas-Instruments/OPA4340UA?qs=wgAEGBTxy7nRw0DNGsw%252Bcg%3D%3D)  **$7.22/1** get 6

#### Resistors

(8) [47R 0805](https://www.mouser.com/ProductDetail/YAGEO/RC0805FR-1347RL?qs=m6lXFsvg5e1DgwoB9H70oA%3D%3D) **$0.012/100 = $1.20** get 100

(8) [4k7 0805](https://www.mouser.com/ProductDetail/YAGEO/RC0805FR-134K7L?qs=m6lXFsvg5e0pEdZpmZIKLA%3D%3D) **$0.01/100 = $1.00** get 100

#### Capacitors

(8) [100pF 0805](https://www.mouser.com/ProductDetail/KEMET/C0805C101K3GACTU?qs=8Ol5LxMUegri7nW0mRT3Bw%3D%3D) **$0.077/10 = $0.77** get 30

(2) [100nF 1206](https://www.mouser.com/ProductDetail/KEMET/C1206C104K3GEC7210?qs=55YtniHzbhB4%2FhY0bEvvcQ%3D%3D) **$0.392/10 = $3.92** get 20

|Reference |Value |Qty|
|---|---|---|
|C5,C7,C8,C9,C10,C11,C12,C13 |100pF 0805 |8  |
|C6,C14 |100nF 1206 |2  |
|J1,J2 |Conn_01x06_Pin |2  |
|J3,J4 |Conn_01x05_Socket |2  |
|PWR1 |Conn_01x04_Pin |1  |
|R3,R6,R9,R10,R15,R16,R17,R18|47R 0805 |8  |
|R4,R5,R7,R8,R11,R12,R13,R14 |4k7 0805 |8  |
|U1,U2 |OPA4340UA SOIC-14 |2  |

board-photo

## Workplan

- [ ] Breadboard op-amp slew circuit, test with any DAC stepped at 7bit resolution. Get good capacitor values for sufficient slew.
- [x] Check existing parts stock, to be sure.
- [x] Select an op-amp for post-dac conditioning.
- [ ] Lay out panel jack PCB check enough room for connectors and easy to route
- [x] Lay out perf DAC board
- [x] send DAC board to OSH Park to enable testing a populated DAC board.
- [x] Order DAC parts
- [ ] ~~Build perf DAC v0.1 board~~
- [ ] ~~Test perf DAC v0.1 board with 5V5 supplies.~~
- [x] Lay out perf DAC v0.2 board
- [x] Send perf DAC v0.2 board to OSH Park
- [ ] Build perf DAC v0.2 board
- [x] Lay out buffer board
- [x] Send buffer board to OSH Park
- [x] Order buffer parts
- [x] Build and test buffer
- [ ] Test perf DAC v0.2 with output to buffer board
- [ ] Order panel board from OSH Park
- [ ] Assemble completed perf DAC, measure, check against panel drawing

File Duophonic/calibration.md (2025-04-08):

# Calibration

There are two types of calibration:

## Initial setup trimming

Pitch Vref has no pitch trimmers; calibration of Pitch DAC output to account for Vref inaccuracy, DAC zero and DAC max errors is done in software.

The 14bit performance outputs are untrimmed, 0-5V within 5-10mV is fine.

Vref needs extensive measurement (for ageing) outside case anyway.

Might be better to allow re-calibration after pitch Vref drift though (annual maintenance).

## Per-voice oscillator calibration (tuning)

### Manual Tuning

Tune ... Manual ... Low | High | Both

Puts out 0.75V for concert A. LED shows by color (red is low, blue is high, green is in tune) and OLED displays closest note (eg B4#) and cents high/low.

### Auto tuning

Tune ... Auto ... Low | High | Both

Avoid non-linear calibration curves. These are fine for pulling poorly-tracking oscillators into tune but then the same errors affect the other modules using pitch (filters etc). Instead go for high linearity, and use with well tracking oscillators.

Two stages: analog coarse tune (manual oscilator tuning to a fixed pitch) then digital fine tune and linearization (measuring frequency per-oscillator at a range of voltages, for linearity and for oscillator range).

Output the same voltage (frequency calculated for the given CV, e.g. for 440Hz) on both  pitch channels. Use FreqMeasure library to provide a frequency input, showing the frequency on the LCD screen. This allows each oscilator to be tuned the same. Use the LEDs to visually indicate high or low (by color) and closeness to exact tuning (slower pulsing means closed to exact).

Once in tune, run a frequency sweep measuring at least 30 steps and calculating a correction factor to account for slope inaccuracy (not exactly 1V/oct) and high frequency droop. Optionally, log the temperature at which tuning was done.

[FreqMeasureMulti](https://github.com/PaulStoffregen/FreqMeasureMulti) can measure multiple inputs simultaneously, providing the option to calibrate both voice channels at the same time. It is best for lower frequencies, 0.1Hz to 1kHz. Available pins 0-9,22-25,28,29,33,36,37,42-47, 48-50(dups),51, 52-53 (dups), 54.

[FreqCountMany](https://github.com/PaulStoffregen/FreqCountMany) also measures multiple inputs, best for 1kHz and up. Available pins 6, 9, 10, 11, 12, 13, 14, 15, 18, 19.

Current [panel](./Panel.md) has per-voice tuning inputs.

> calibrating only octaves it also runs foul of the same quirk in some oscillators where they go out of tune just a semitone or two before 0v – with possibly even worse results, as you would now have a bad data point for 0v.
>
> Not all sound sources can take a full negative to positive swing pitch control voltages. Many digital modules in particular only listen to positive voltages, and may be go of tune as you get close to 0 volts no matter what you do. Also, I’ve seen some analog modules which track differently above 0 volts than they do below 0 volts.
>
> [Calibr8or firmware for Ornament & Crime](https://learningmodular.com/calibr8or/)

### Calibration curve save/read

> To simplify and put into context - EEPROM.put on the T4 will do the same as .update for you, so use EEPROM.put. If the user constantly saves their settings every hour, 24 hours a day, 7 days a week, it will take them almost 12 years to do 100,000 saves and likely 50-100 years of doing this before wearing from repeated writes may be an issue, so for this use case, don't worry about wearing, its a non-issue for this use case. It's hard to get to 100,000 events with purely human interaction, but easy when machine driven.
> [--beermat](https://forum.pjrc.com/index.php?threads/best-way-to-store-64-bits-of-user-parameters.76368/#post-353976)

### MIDI Tune Request

Respond to F6 Tune Request by tuning both channels. Will only work if the oscillator outputs are looped back to the tune inputs.

### Tune-in conditioning circuitry

Level from oscillator should be plenty high, no need for amplification. May need some low-pass filtering to get rid of above-audio signals that could cause false triggering?

Highest note for tuning (**A8** = 7040.00Hz ) so 10kHz low-pass filter on input seems wise.

sallen-key

[Sallen-Key low-pass design tool](http://sim.okawa-denshi.jp/en/OPstool.php) R1=R2=47k, C1 = 470pF, C2 = 220pF. Higher input resistance avoids need for buffer on input. Use a dual 072 op-amp with ±12V supplies for interfacing to modular signals.

response

Then hard clip to a 0..3V3 unipolar signal with a dual, rail-to-rail, single supply (3V3) fast recovery op-amp so it can be safely fed to the Teensy. OPA2365 ($3.74/1) has specified overload recovery time < 0.1μs and RRIO. Use 2k current-limiting input resistor (<10mA) then rely on protection diodes.

Better to follow the clamp with a dual Schmitt-trigger (SN74LVC2G17DBVR, SOT-23-6 $0.259/10) also on 3V3 to sharpen up the edge transitions.

tune in testbed ([PDF](./Tune-in-sch.pdf))

tune in board ([PDF](./Tune-in-brd.pdf))

> We detected a 2 layer board of 1.52 x 0.97 inches (38.6 x 24.6mm)
> 3 boards will cost $7.35

Tune-in testing board **Ordered 18 Oct 2024**

Paul Stoffregen [said](https://www.facebook.com/photo.php?fbid=7913976078691226&set=p.7913976078691226&type=3)

> That ought to be pretty easy. Unless you're expecting high frequency noise, I'd probably omit the filter and just go with a "simple" voltage comparator using resistors to scale the signal. Hysteresis is the main feature you (probably) need. With an analog comparator you can adjust the feedback resistor to trade off sensitivity versus rejection of noise. It'll also give your hysteresis pretty good temperature stability since the response depends on the resistor ratio which is pretty stable even with cheap resistors, rather than the transistors inside a CMOS chip with vary with temperature.

paul's sketch

Johny Reckless said:

> I would configure U2A as an inverting integrator with a small time constant (10us or so) to remove any ringing in the response as you square up the edges. Something like 1k / 10nF might work well, maybe a slightly smaller cap if you need faster response. With a decent rail to rail cmos opamp you won't then need the Schmitt trigger.

Experiment on breadboard.

> The FlexPWM timer used by FreqMeasureMulti requires very fast edges. Your signal looks like it has rather slow rise/fall times, and that will not work with FreqMeasureMulti. Can you add a schmitt trigger on your input?
>
> [PJRC](https://forum.pjrc.com/index.php?threads/teensy-4-1freqmeasuremulti-library.75304/#post-345574)

[Simple and fast bipolar-supply precision clamp with RRIO](https://www.eevblog.com/forum/projects/limiting-op-amp-output/msg441564/#msg441564) and [even simpler, unipolar-supply](https://www.eevblog.com/forum/projects/limiting-op-amp-output/msg732673/#msg732673)

Should this have a Schmidt-trigger inverter or something like that to ensure even low-level signals are square-wave like? Build and test the simple op-amp clamp and check results on scope.

#### Tune-In BOM

- (2) Panasonic ECH-U1H471JX5 470pF PPS film 0805 **$0.397/10**
- (2) Panasonic ECH-U1H221JX5 220pF PPS film 0805 **$0.211/10**
- (4) 4k7 0805 nothing special 1%
- (1) TL072 general purpose dual op-amp TL072BIDT **$1.15/10** 
- (2) 2k 0805 1%
- (1) TI OPA2365AID RRIO SOIC-8 **$3.74/1**
- (1) TI SN74LVC2G17DBVR SOT-23-06 **$0.259/10**
- (3) 100nF decoupling caps 0805

"Reference","Value","Datasheet","Footprint","Qty","DNP"
"C1,C101","470pF","~","Capacitor_SMD:C_0805_2012Metric_Pad1.18x1.45mm_HandSolder","2",""
"C2,C102","220pF","~","Capacitor_SMD:C_0805_2012Metric_Pad1.18x1.45mm_HandSolder","2",""
"C3,C4,C5,C6","100nF","~","Capacitor_SMD:C_0805_2012Metric_Pad1.18x1.45mm_HandSolder","4",""
"J1","12V power","~","Connector_PinHeader_2.54mm:PinHeader_1x03_P2.54mm_Vertical","1",""
"J2","3V3 Power","~","Connector_PinHeader_2.54mm:PinHeader_1x02_P2.54mm_Vertical","1",""
"J3,J6","Out","~","Connector_PinHeader_2.54mm:PinHeader_1x02_P2.54mm_Vertical","2",""
"J4,J5","In","~","Connector_PinHeader_2.54mm:PinHeader_1x02_P2.54mm_Vertical","2",""
"R1,R2,R101,R102","47k","~","Resistor_SMD:R_0805_2012Metric_Pad1.20x1.40mm_HandSolder","4",""
"R3,R103","2k","~","Resistor_SMD:R_0805_2012Metric_Pad1.20x1.40mm_HandSolder","2",""
"TP1,TP2,TP3,TP4","TestPoint","~","TestPoint:TestPoint_THTPad_1.0x1.0mm_Drill0.5mm","4",""
"U1","TL072","http://www.ti.com/lit/ds/symlink/tl071.pdf","Package_SO:SOIC-8_3.9x4.9mm_P1.27mm","1",""
"U2","OPA2365","https://www.ti.com/lit/gpn/opa2365","Package_SO:SOIC-8_3.9x4.9mm_P1.27mm","1",""
"U3","74LVC2G17","http://www.ti.com/lit/sg/scyt129e/scyt129e.pdf","Package_TO_SOT_SMD:SOT-23-6_Handsoldering","1",""

<div class="row"><div class="col-md-12"><div class="panel panel-success">

<table border=1 class="table table-striped table-bordered table-hover table-condensed">
<thead><tr><th title="Field #1">Reference</th>
<th title="Field #2">Value</th>
<th title="Field #3">Datasheet</th>
<th title="Field #4">Footprint</th>
<th title="Field #5">Qty</th>
<th title="Field #6">DNP</th>
</tr></thead>
<tbody><tr><td>C1,C101</td>
<td>470pF</td>
<td>~</td>
<td>Capacitor_SMD:C_0805_2012Metric_Pad1.18x1.45mm_HandSolder</td>
<td align="right">2</td>
<td> </td>
</tr>
<tr><td>C2,C102</td>
<td>220pF</td>
<td>~</td>
<td>Capacitor_SMD:C_0805_2012Metric_Pad1.18x1.45mm_HandSolder</td>
<td align="right">2</td>
<td> </td>
</tr>
<tr><td>C3,C4,C5,C6</td>
<td>100nF</td>
<td>~</td>
<td>Capacitor_SMD:C_0805_2012Metric_Pad1.18x1.45mm_HandSolder</td>
<td align="right">4</td>
<td> </td>
</tr>
<tr><td>J1</td>
<td>12V power</td>
<td>~</td>
<td>Connector_PinHeader_2.54mm:PinHeader_1x03_P2.54mm_Vertical</td>
<td align="right">1</td>
<td> </td>
</tr>
<tr><td>J2</td>
<td>3V3 Power</td>
<td>~</td>
<td>Connector_PinHeader_2.54mm:PinHeader_1x02_P2.54mm_Vertical</td>
<td align="right">1</td>
<td> </td>
</tr>
<tr><td>J3,J6</td>
<td>Out</td>
<td>~</td>
<td>Connector_PinHeader_2.54mm:PinHeader_1x02_P2.54mm_Vertical</td>
<td align="right">2</td>
<td> </td>
</tr>
<tr><td>J4,J5</td>
<td>In</td>
<td>~</td>
<td>Connector_PinHeader_2.54mm:PinHeader_1x02_P2.54mm_Vertical</td>
<td align="right">2</td>
<td> </td>
</tr>
<tr><td>R1,R2,R101,R102</td>
<td>47k</td>
<td>~</td>
<td>Resistor_SMD:R_0805_2012Metric_Pad1.20x1.40mm_HandSolder</td>
<td align="right">4</td>
<td> </td>
</tr>
<tr><td>R3,R103</td>
<td>2k</td>
<td>~</td>
<td>Resistor_SMD:R_0805_2012Metric_Pad1.20x1.40mm_HandSolder</td>
<td align="right">2</td>
<td> </td>
</tr>
<tr><td>TP1,TP2,TP3,TP4</td>
<td>TestPoint</td>
<td>~</td>
<td>TestPoint:TestPoint_THTPad_1.0x1.0mm_Drill0.5mm</td>
<td align="right">4</td>
<td> </td>
</tr>
<tr><td>U1</td>
<td>TL072</td>
<td><a href="http://www.ti.com/lit/ds/symlink/tl071.pdf">PDF</a></td>
<td>Package_SO:SOIC-8_3.9x4.9mm_P1.27mm</td>
<td align="right">1</td>
<td> </td>
</tr>
<tr><td>U2</td>
<td>OPA2365</td>
<td><a href="https://www.ti.com/lit/gpn/opa2365">PDF</a></td>
<td>Package_SO:SOIC-8_3.9x4.9mm_P1.27mm</td>
<td align="right">1</td>
<td> </td>
</tr>
<tr><td>U3</td>
<td>74LVC2G17</td>
<td><a href="http://www.ti.com/lit/sg/scyt129e/scyt129e.pdf">PDF</a></td>
<td>Package_TO_SOT_SMD:SOT-23-6_Handsoldering</td>
<td align="right">1</td>
<td> </td>
</tr>
</tbody></table>
</div></div></div>

### Temperature compensation

Measuring the case internal temperature might be helpful and is easy to do, but not clear how well that would predict tracking of individual oscillators.

Not a must-have, and complicates addition and removal and tuning of modules, but one idea is to use thermal epoxy to attach a Dallas DS18B20 thermal sensor to the expo converter of each oscillator, then measure the temperatures and adjust linearization calibration curves based on the temperature, likely through linear interpolation of closest calibrated temperatures. Perhaps a _temperature bus board_ with pluggable conectors?

The EuroMPE would need to know which oscillator was connected to which tne input, which implies messing with the menu. Usefully, each DS18B20 has a unique 64bit serial number which could be used to identify oscillators.

Reading all temperature sensors rquires just one pin on Teensy.

 - [Interfacing Multiple DS18B20 Digital Temperature Sensors with Arduino](https://lastminuteengineers.com/multiple-ds18b20-arduino-tutorial/)

## Calibrating the calibrator

#### Keysight 34465A

Bench dmm, voltage (and frequency?) measurement device. **GOT**

Reciprocal counting for frequency.

- DC Voltage (10V scale): 0.0010 + 0.0003 (24hr), 0.0045 + 0.0004 (2 year)
- Frequency (100 Hz – 1 kHz, 1sec aperture): 0.003 (24hr), 0.010 (2 year) so 440Hz ±0.044 (439.956 - 440.044)

> All frequency counters are susceptible to errors when measuring low–voltage, low–frequency signals. The effects of both internal noise and external noise pickup are critical when measuring "slow" signals. The error is inversely proportional to frequency. Measurement errors also occur if you attempt to measure the frequency (or period) of an input following a DC offset voltage change. You must allow the multimeter's input DC blocking capacitor to fully settle before making frequency measurements.

#### AimTTi [TF930](https://www.aimtti.com/product-category/frequency-counters/aim-tf900series) 

Bench/portable universal counter with USB interface 3GHz **$471**

- Frequency, period, pulse width, frequency ratio, duty cycle, and event counter modes
- 0.001 Hz to 125 MHz and 80 MHz to 3 GHz range, 0.001mHz resolution
- high-quality temperature compensated internal frequency reference which
has a low aging rate and is stable to within ±1ppm over the full temperature range.
- USB interface, remote controllable
- accepts 10 MHz clock for GPS conditioning

> Measurement accuracy is timebase accuracy + measurement resolution + 2 counts.
> Timebase accuracy ± 0.2ppm
> Eight digits in 1s, nine digits in 10s and ten digits in 100s

So 440Hz (1s) 440.00000 ± 8.8E-5 ± 000.0002 (439.99971 - 440.00029), or 100x better than 35565A even on 1s.

#### Leo Bodnar [LBE-1420 ](https://www.leobodnar.com/shop/index.php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)

GPS locked clock source, as reference. **$155.96**

- Multi-loop digital-analog PLL allows output frequency to be set to any value between 1 Hz and 1.1 GHz with infinite resolution. For example, 144,800,000.025 Hz.

#### Ian Johnston [PDVS2](https://www.ianjohnston.com/index.php/onlineshop/handheld-precision-digital-voltage-source-v2-detail)

Precision Digital Voltage Source **GOT** Retired, no longer available.

- 0 Vdc to 10 Vdc user adjustable output in 10 V mode (4d.p’s effective, approx. 38uV)
- [DAC9881S](https://www.ti.com/product/DAC9881) 18bit DAC with an accuracy/stability down in the uV’s (using a PLC filter of 1.0 or higher)
- Voltage reference = LM399AH (0.5 - 1 ppm/degC temperature coefficient)

## Testing results

### PWM loopback frequency measurement results

Frequencies tested by loopback of pwm output to FreqMeasureMulti inputs (sketch Three_PWM_in_Serial_Output). Tested **20Hz**, **20kHz**, **440Hz**. Limit to verifying accuracy is the exact frequency produced by PWM, especially at higher frequencies, and the limits of a gate-interval frequency meter at low frequencies.

Teensy 4.0 (FreqMeasureMulti, at 600MHz) compared to Keysight 34465A (gate time 1s).

PWM at **16.35Hz**, Teensy reports **17.8819Hz**, Keysight (AC Filter >3Hz) **17.88204Hz**, sd 1.4 μHz. Seems PWM cannot reliably go that low.

PWM at **20Hz**, Teensy reports **20.0003Hz** while Keysight (AC Filter >3Hz, 1s gate) reports **20.000382Hz** sd 129nHz, an error of **-82 ppm**. Keysight is doing gate interval not timing between rising edges, so Keysight is more likely to be incorrect here! Also 20Hz is a third of the 60Hz mains frequency.

PWM at **45Hz**, Teensy reports **45.0003Hz** while Keysight (AC filter >3 Hz, 1s gate) reports **45.000567Hz** sd 0.45 μHz, an error of **-267 ppm**. Again likely the Keysight is in error there.

PWM at **200Hz**, Teensy reports **200.0000** while Keysight (AC Filter >20Hz, 1s gate) reports **200.00123Hz** sd 1.55 μHz, an error of **-1.23 ppb**

On **440Hz** (concert A), Teensy reports **440.0066Hz** while Keysight 34465A (AC filter >20Hz, gate time 100ms) reports **440.009Hz**, sd 30 μHz which is an error of **-2.4 ppb** ! _Repeat measurement with 1s gate_.

PWM at **2kHz**, Teensy reports **2,000.0000Hz** while Keysight (AC Filter >20Hz, 1s gate) reports **2.000012kHz** sd 13.5 μHz, an error of **-12 ppb**

PWM at **4kHz**, Teensy reports **4,000.0000** while Keysight (AC Filter >20Hz, 1s gate) reports **4.000025kHz** sd 33 μHz, an error of **-25 ppm**. Still good agreement there, but likely the Teensy is starting to be in error and we should be using FreqCount instead.

PWM at **8kHz**, Teensy reports **7999.5732Hz** while Keysight (AC Filter >20Hz, 1s gate) reports **8.000050kHz** sd 50 μHz, an error of **-476 ppm**. Note that **8.372kHz** is upper limit of useful frequencies for a [MIDI-range](./MIDI.md) calibration.

Worryingly with PWM specified as **20kH**z, Teensy reports **20,000Hz** while Keysight (AC Filter >20Hz, 1s gate) reports **18.18kHz** sd 439 Hz (!) implying the PWM frequency is both inaccurate and unstable.

### Leo Bodnar frequency standard vs. Keysight 34465A

Test temperature 19.3 to 21.7C (window slightly ajar for GPS antenna).

Frequencies tested with GPS-locked Leo Bodnar LBE-1420 clock source (assumed accurate) and measured on Keysight 34465A (which uses the reciprocal counting technique) with 1s gate and LPF >20Hz (except 10Hz measurement, which was >3Hz). 1000 samples.
Connection via 50R BNC cable, with SMA-to-BNC at the Leo Bodnar and BNC-to-pair-4mm at the DMM.

At **10Hz** Keysight reports **10.000125Hz** sd 223nHz

At **100Hz** Keysight reports **100.00124Hz** sd 4.65μHz

At **1kHz** Keysight reports **1.0000123kHz** sd 26.4μHz

At **10kHz** Keysight reports **10.000123kHz** sd 292μHz

At **100kHz** Keysight reports **100.00122kHz** sd 6.63mHz

At **440Hz** Keysight reports **440.00553Hz** sd 4.06μHz

Results extremely good, 8 figure precision ±1 digit, and constant +12.3ppm error across the range tested. Vastly better than the Keysight Frequency Accuracy Verificatin figures (Operating and Service Guide, p. 517) which are 10Hz ± 3 mHz and 300kHz at ±60 Hz (24 hours) to ±270 Hz (2 years); or the datasheet:

- 3Hz-10Hz ±0.1% (24hr)  ±0.1% (2yr)
- 10Hz-100Hz ±0.03% (24hr)  ±0.035% (2yr)
- 100Hz-1kHz ±0.03% (24hr)  ±0.017% (2yr) so 440Hz ± 74.8mHz (439.9252 to 440.0748)
- 1kHz-300kHz ±0.002% (24hr)  ±0.017% (2yr)

±0.017% is a 0.29428 cent (294 millicent) error, which if the same order of magnitude as the oscillator deviations I am trying to measure. 12.3ppm is an order of magnitude better, 0.02129404784514272 cents (21.29 millicents), ample for the purpose.

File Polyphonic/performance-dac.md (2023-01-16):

# Performance (Control Change) DAC

One octal DAC does 2 voices  of attack veocity, lift velocity, pressure, glide. Perf DAC board has 2 DACs so 4 voices.

*Note* final MPE specification reduces precision of pressure & glide to 7bit. However, later expansion to 14bit not ruled out. Implement 14bit as an experiment; 7bit still supported.

Similar circuitry also used to provide the global performance controls (mod wheel, sustain, etc) but with one DAC.

## Chip selection

Needs to be 14-bit capable to fully implement the HR aspect, but precision requirement lower than for pitch; most devices send 7bit data and the ones that are high resolution have ENOB less than 14. 1 LSB at 14bit is 300μV but 1 LSB at 7bit is a huge 39mV. Aim for at least 10 ENOB (4.8mV), preferably 12 ENOB (1.2mV).

**AD5648-2** octal 14-bit DAC ($19.91, got one) NO unsuitable due to zero and gain offsets. Internal VRef of 2.5V gives unipolar 5V output. Better performance from the -2 devices at 5V than the -1 devices at 3V3. Fig. 31 shows **100mV** (!!) error when sourcing or sinking 2mA. Internal 2V5 reference with 2x gain, can use external (5V) ref. Notice most of the graphs in datasheet use an external reference :)
Vref seems to give a couple of mV error in output wrt temperature. Fig.54 shows 4mV error in internal ref wrt temperature.

**DAC8168C** (or DAC8168ICPW  seems more available) octal 14-bit DAC (TSSOP-16, $27.26) much better offsets ±1 / ±4 mV.

## Power

Same clean 5.5V as the pitch DACs use. Most graphs in datasheet are at AVdd =  5.5V.

## Digital interface

Needs level shifter for SPI. Use second SPI channel on Teensy 3.6. One quad shifter handles 2 CS plus SCLK and MOSI - enough for base board 2 voices and global CC board. A second shifter gives 4 more CS of which 3 are used for voices 3-4, 5-6 and 7-8.

74AHCT125. One does 2 DAC (4 voices), second adds 4 more CS. Base 4-voice needs two because of the global channel, so one CS for that, two for the other four voices, one left spare. Or would each DAC need its own SCLK and MOSI? In that case one per 2 voices, plus one for global (3 for 4 voice, 5 for 8 voice). Better: one per 4 voices (SCLK, MOSI, 2CS) on each perf DAC board. Another o the global board (with SCLK, MOSI, CS)

## Vref

DAC8168C Internal 2.5V VRef has initial accuracy of 100μV (0.004%), good temperature stability (especially 2x gain C grade) and long-term drift. External Vref probably not needed.
Internal Vref in DAC8168C is adequate for general non-pitch CV duties. Output is 0 to 5V.
Note internal Vref is disabled by default, see datasheet Table 5 for enable command.

## Initial accuracy

From **DAC8168C** datasheet, assuming internal Vref:

INL 300μV / 1.2mV (±1 / ±4 LSB)

DNL 30μV / 150μV (±0.1 / ±0.5 LSB)

Gain error 0.5mV / 7.5mV (±0.01% / ±0.15% of FSR) with  5μV (±1 ppm of FSR)/°C drift

Offset error  ±1 / ±4 mV with ±0.5 μV/°C drift

Zero error 	1mV / 4mV with  ±2 μV/°C drift

At 0 to 5V, 1LSB is 306μV. TL071 with 3mV offset is now significant wrt typical (but not max) offsets.

DAC is not trimmable without external conditioning circuitry.

Long term drift (Fig.7) inside ±500μV (±100ppm) /2k hours
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

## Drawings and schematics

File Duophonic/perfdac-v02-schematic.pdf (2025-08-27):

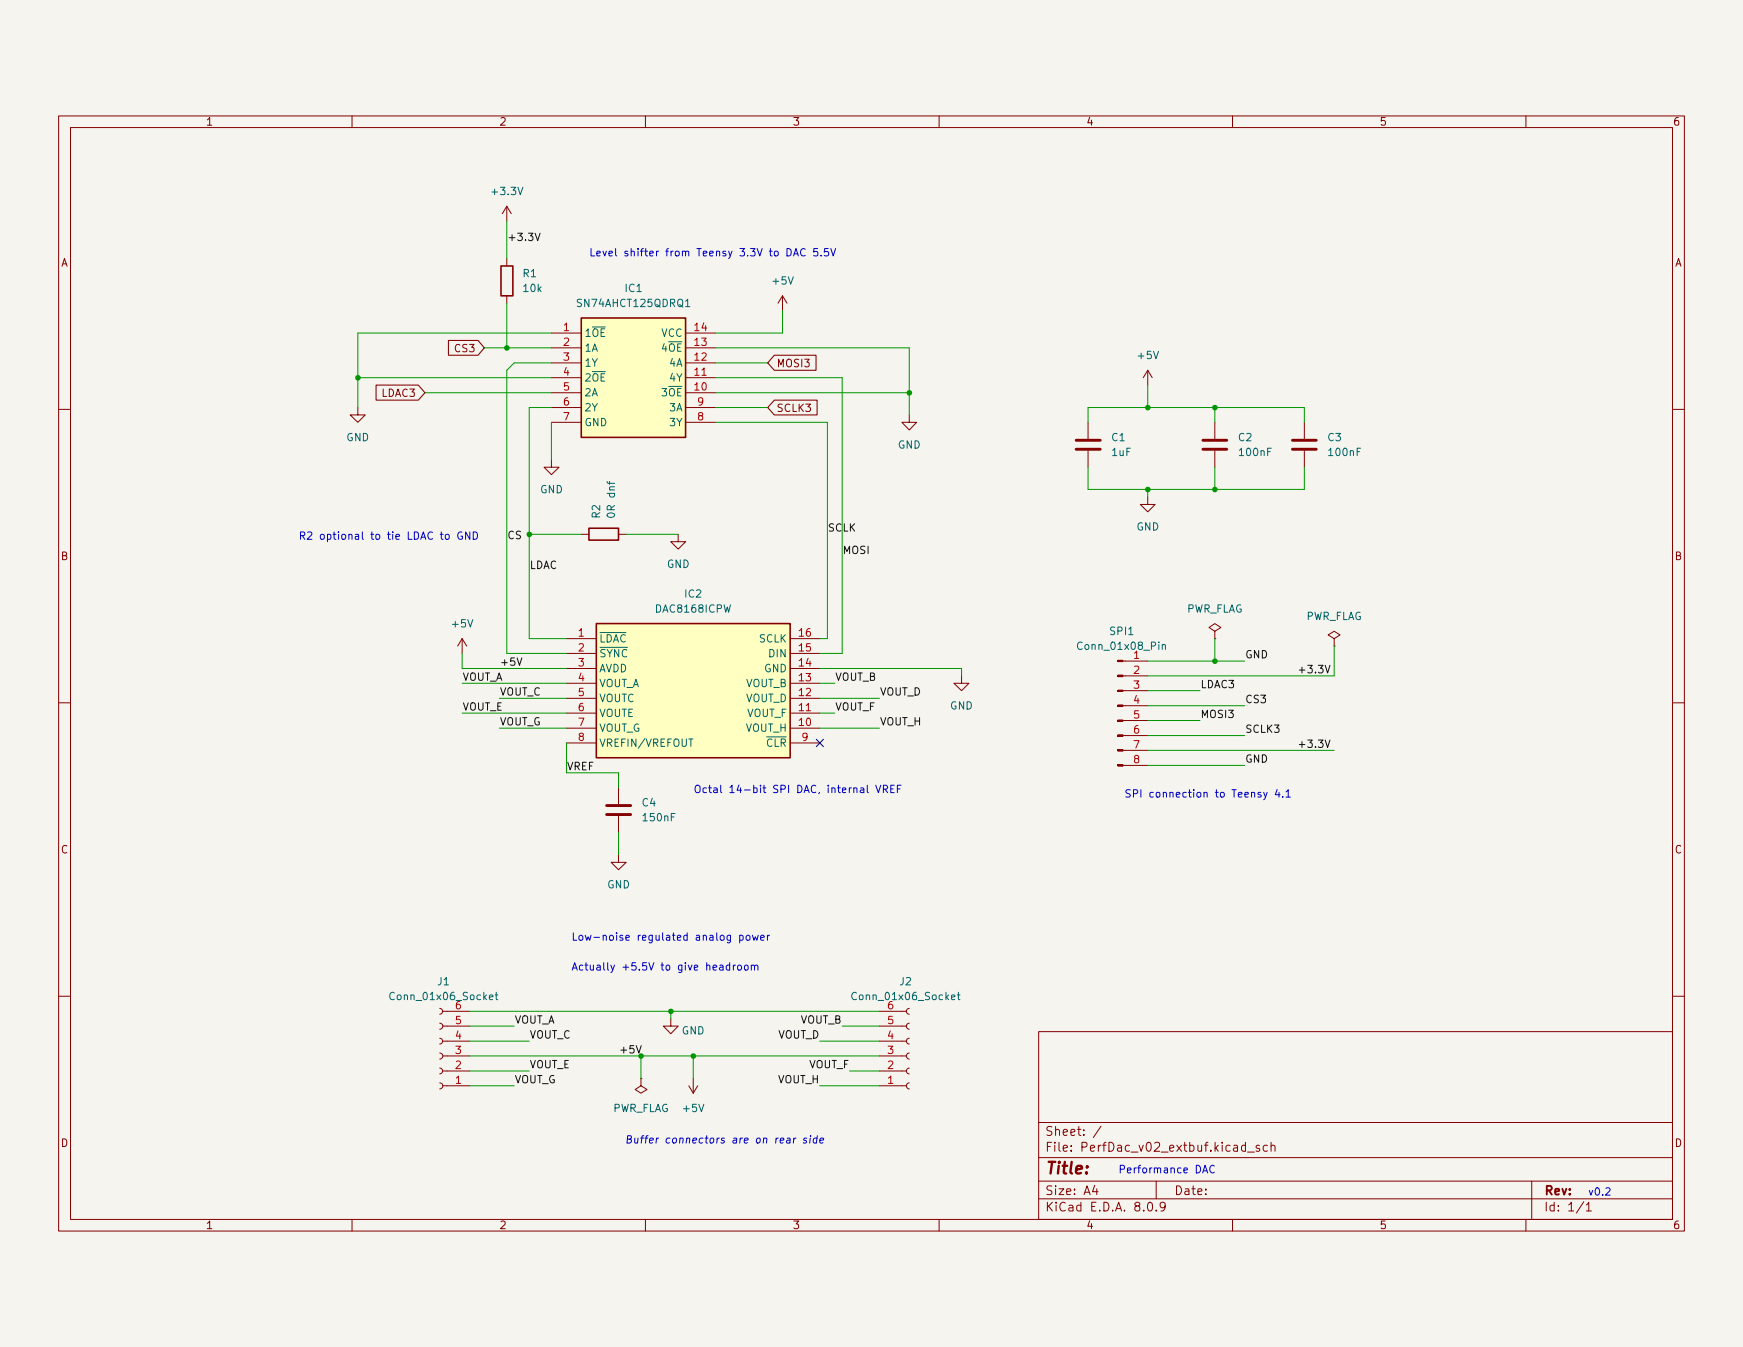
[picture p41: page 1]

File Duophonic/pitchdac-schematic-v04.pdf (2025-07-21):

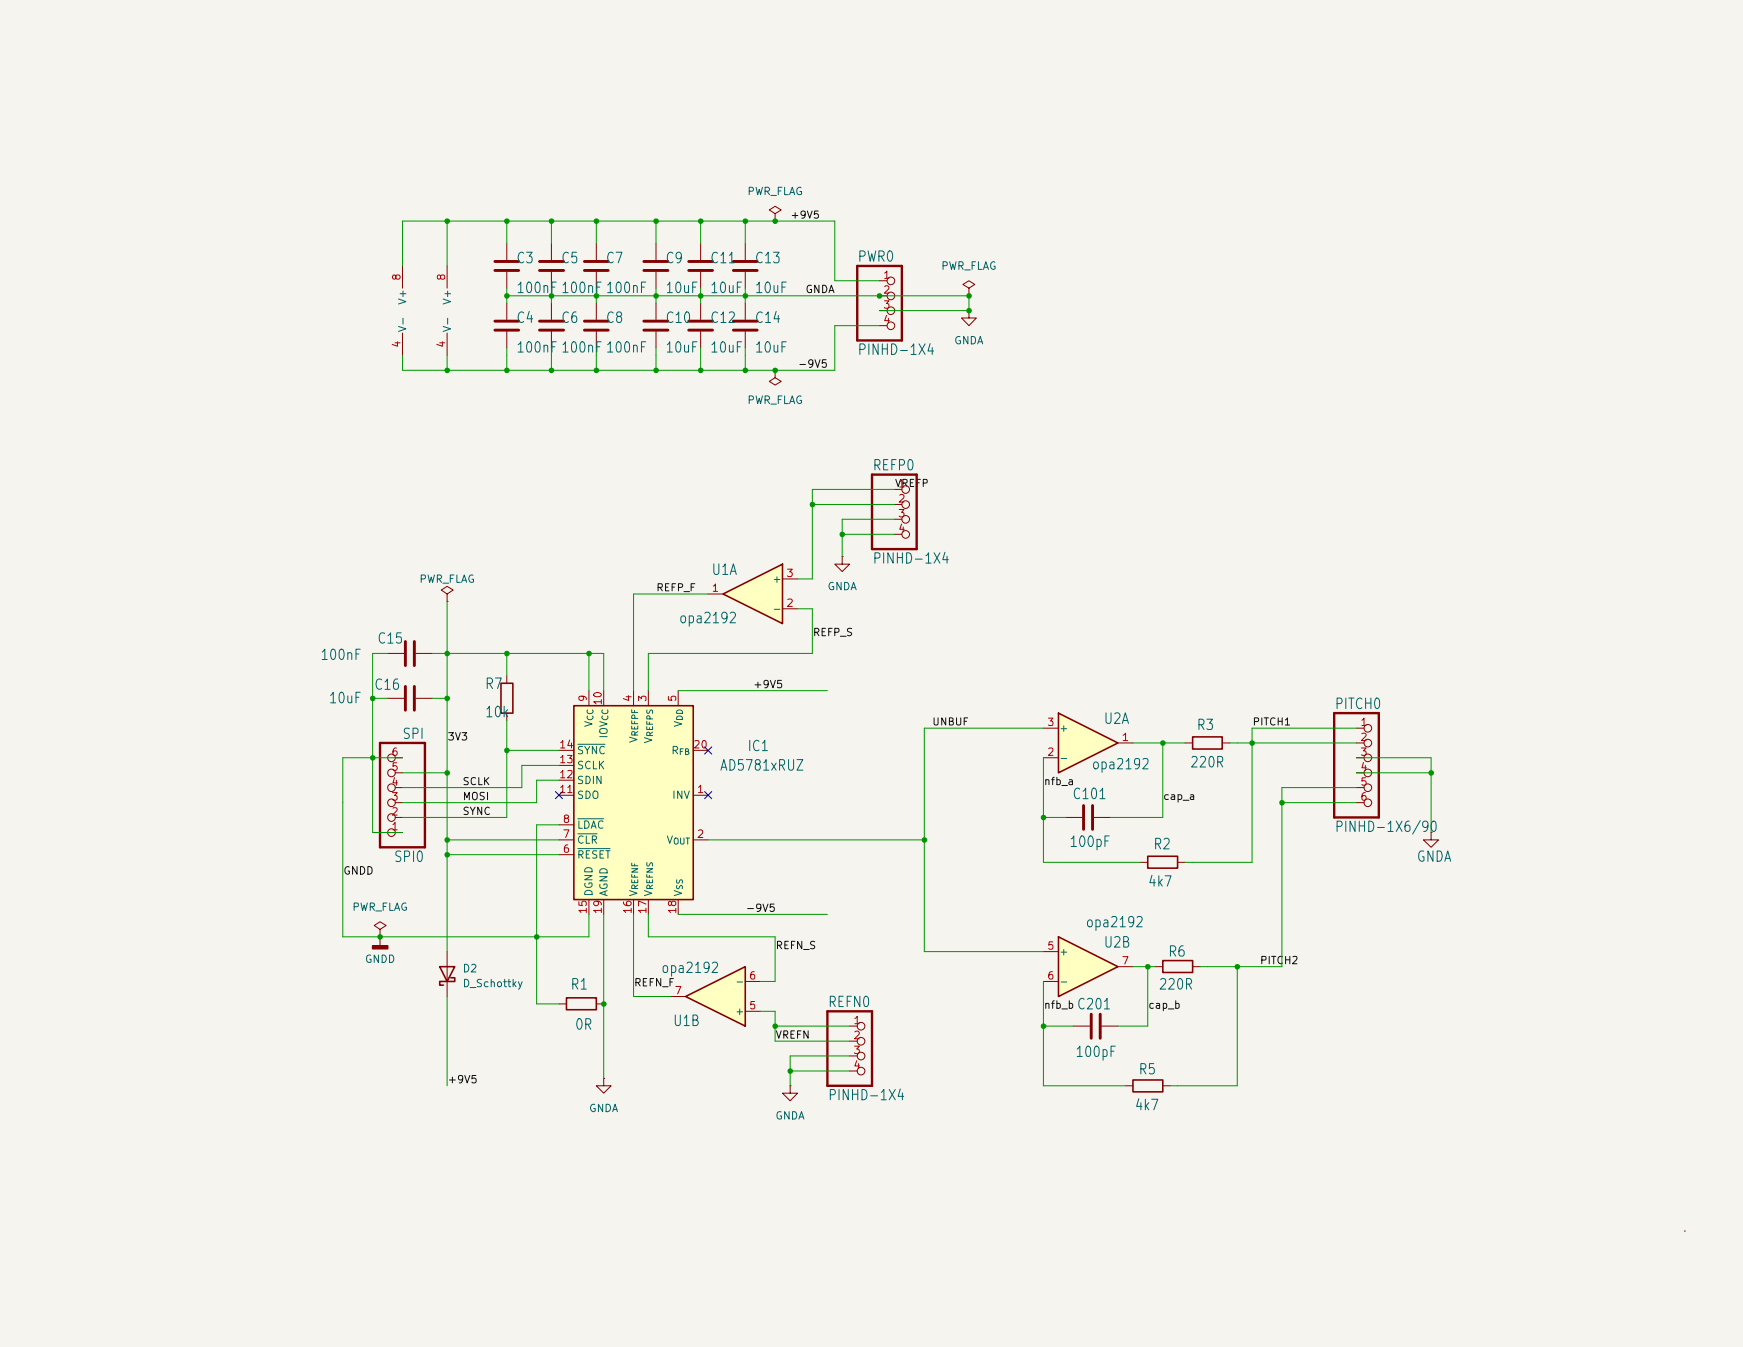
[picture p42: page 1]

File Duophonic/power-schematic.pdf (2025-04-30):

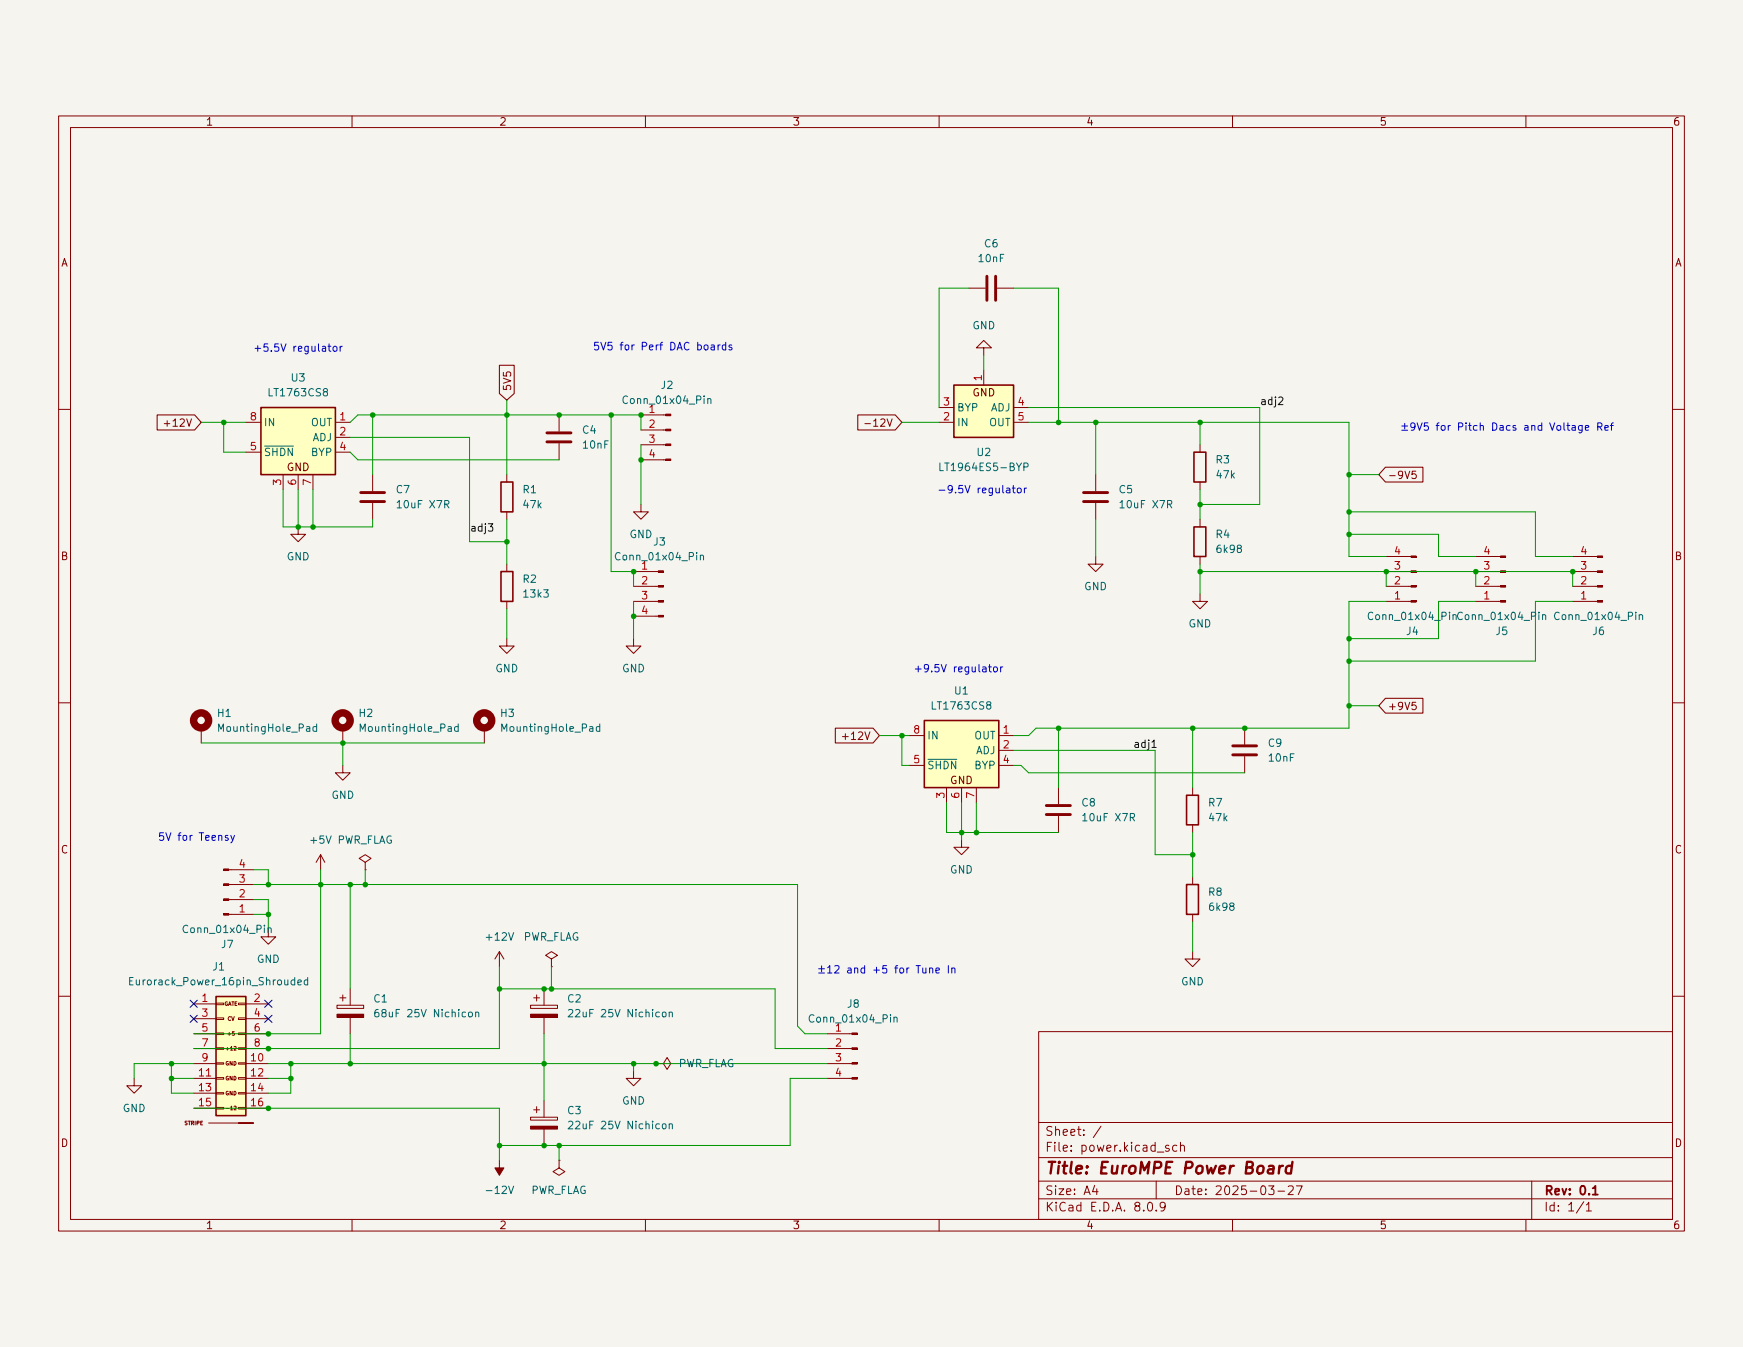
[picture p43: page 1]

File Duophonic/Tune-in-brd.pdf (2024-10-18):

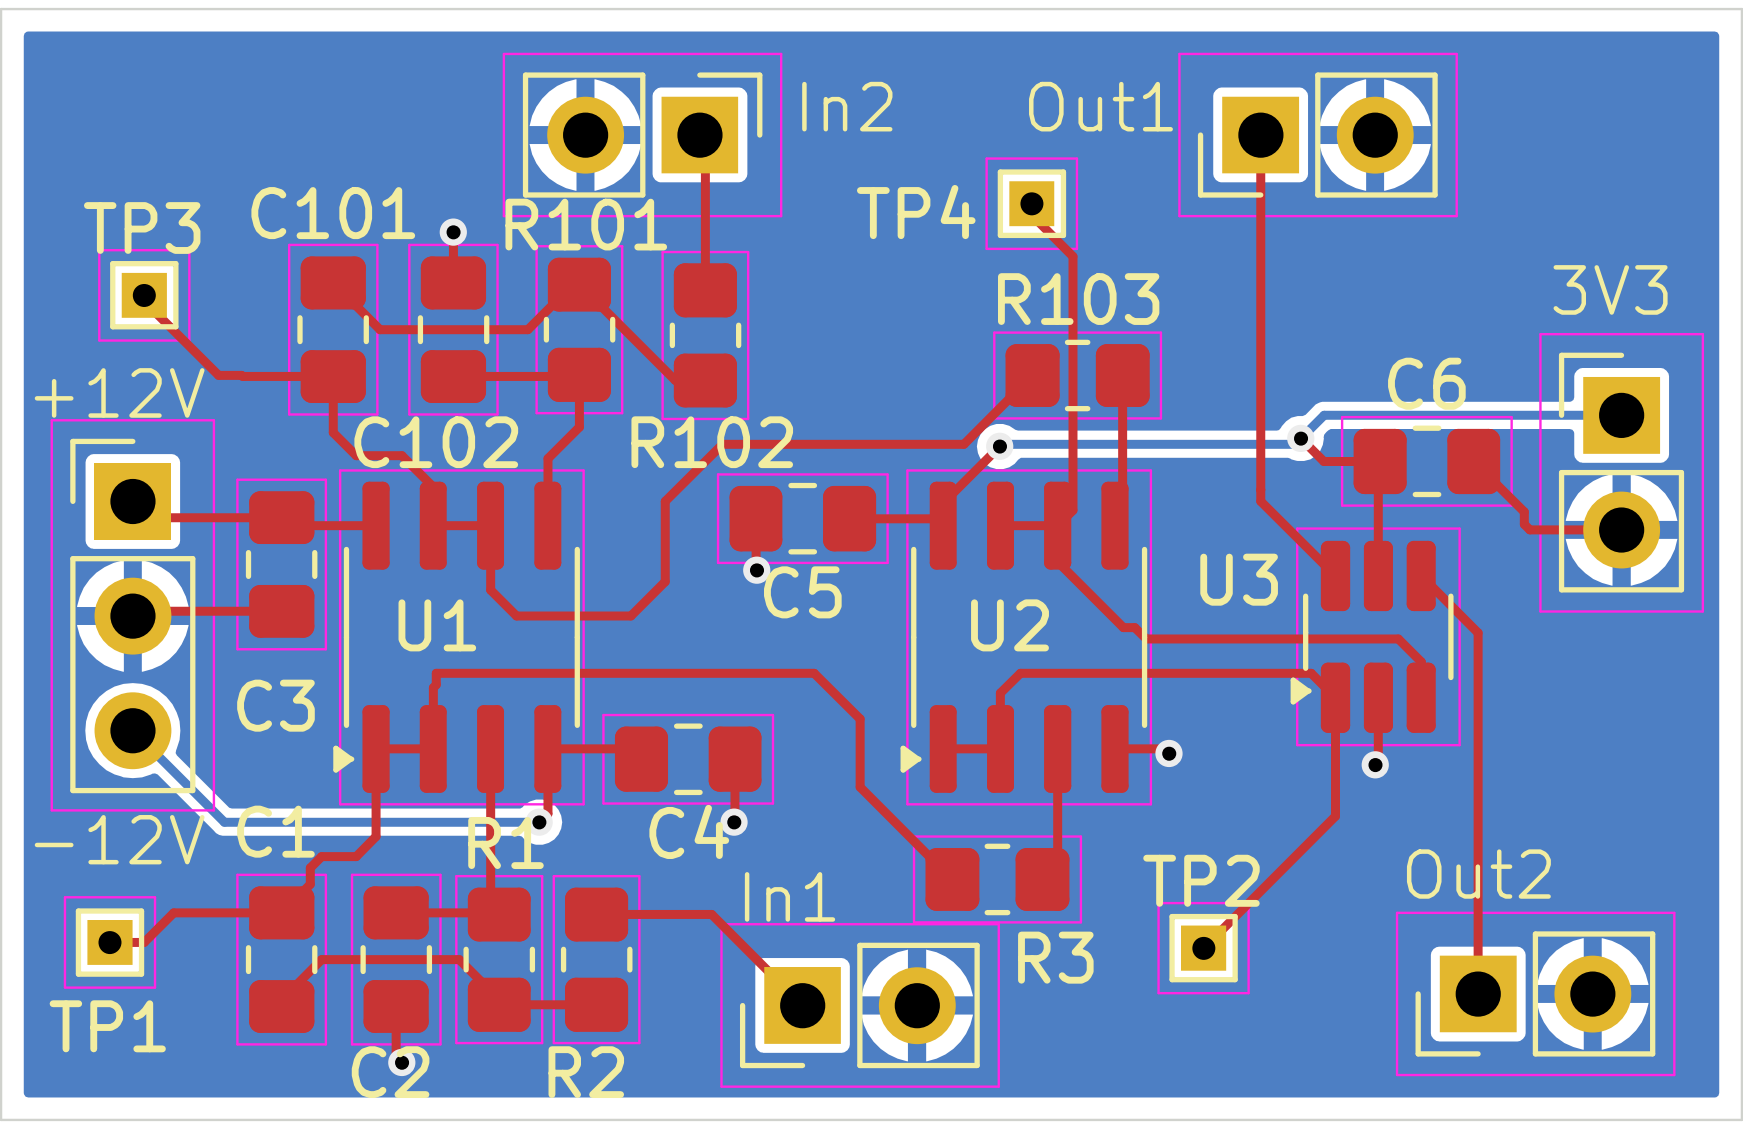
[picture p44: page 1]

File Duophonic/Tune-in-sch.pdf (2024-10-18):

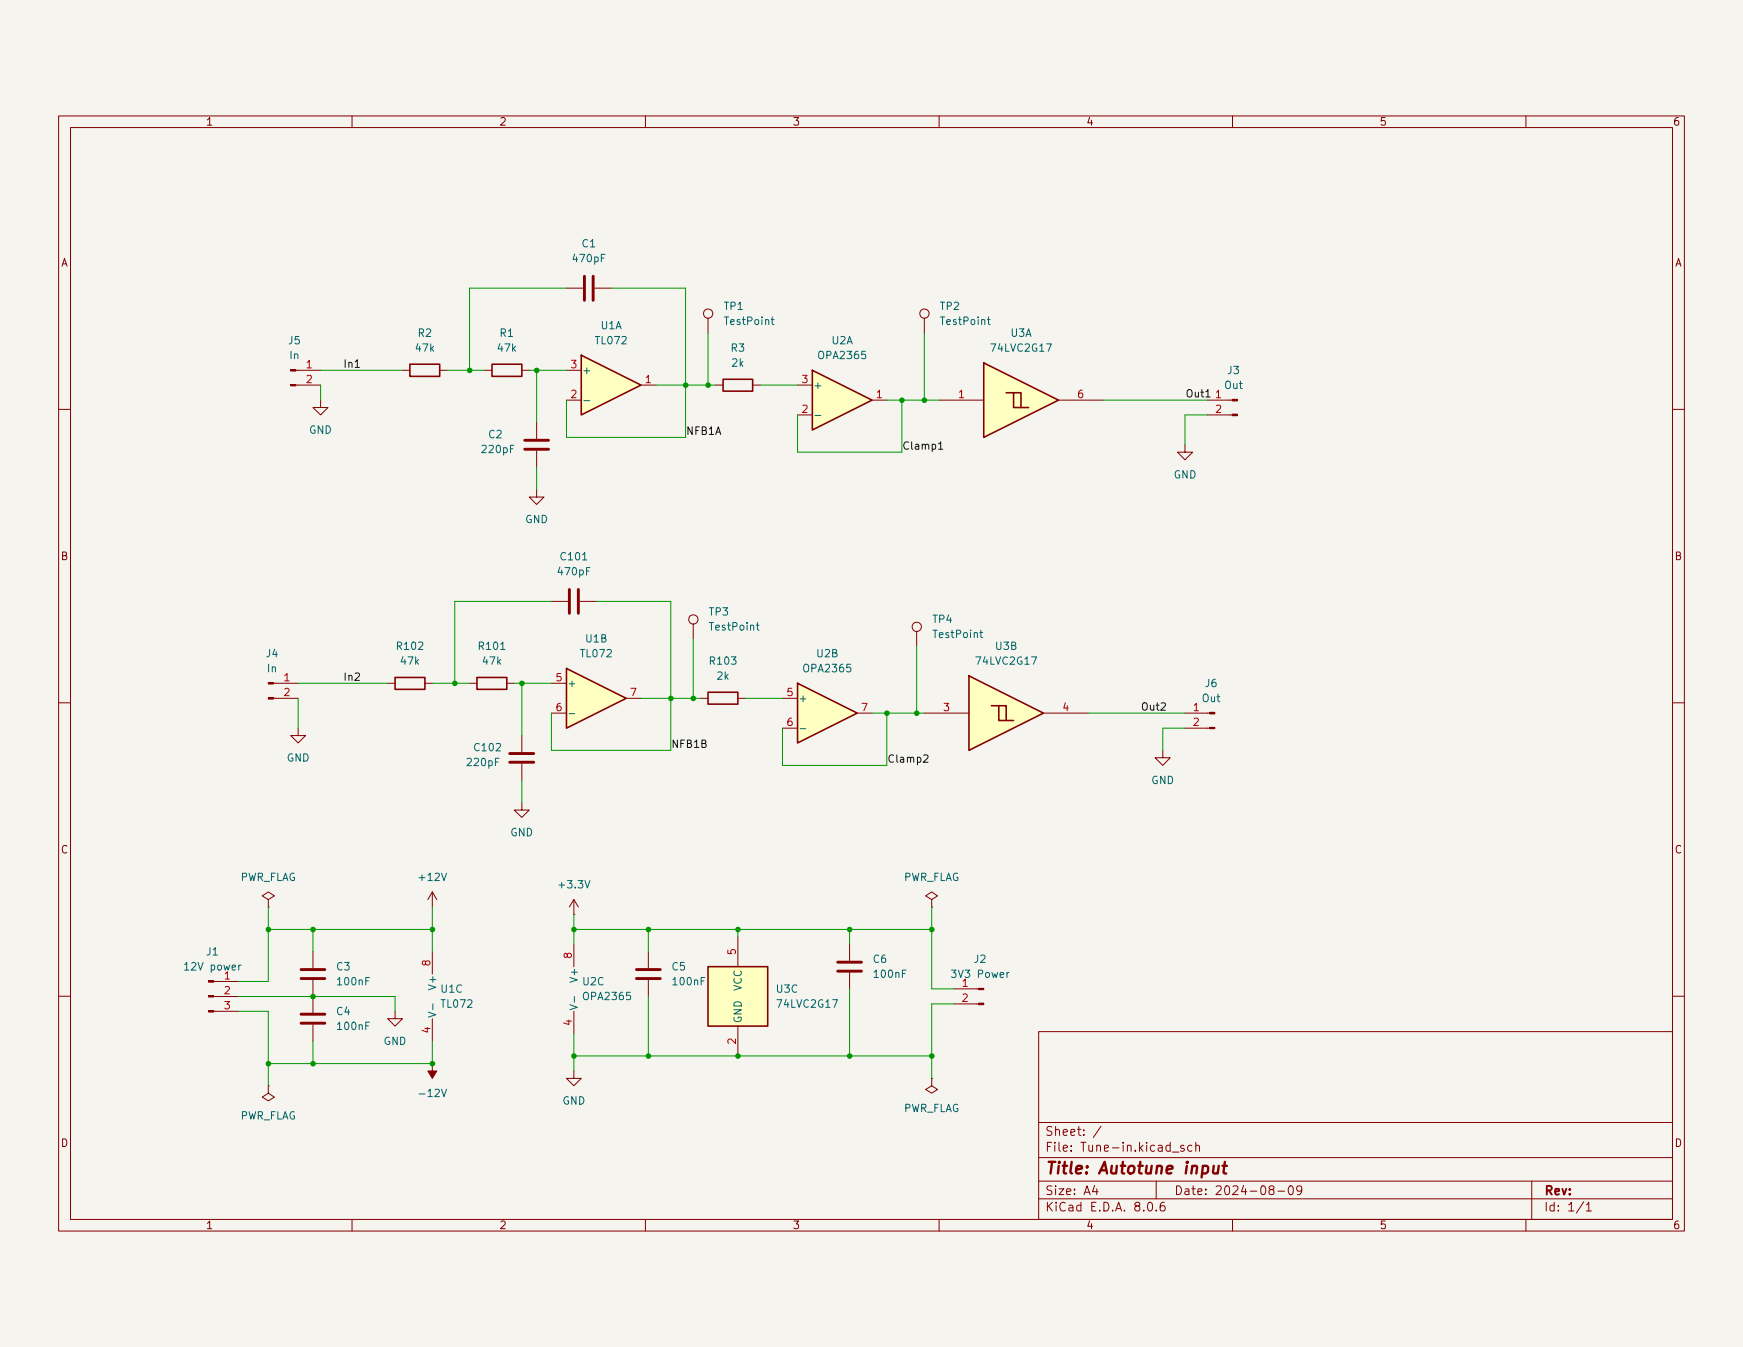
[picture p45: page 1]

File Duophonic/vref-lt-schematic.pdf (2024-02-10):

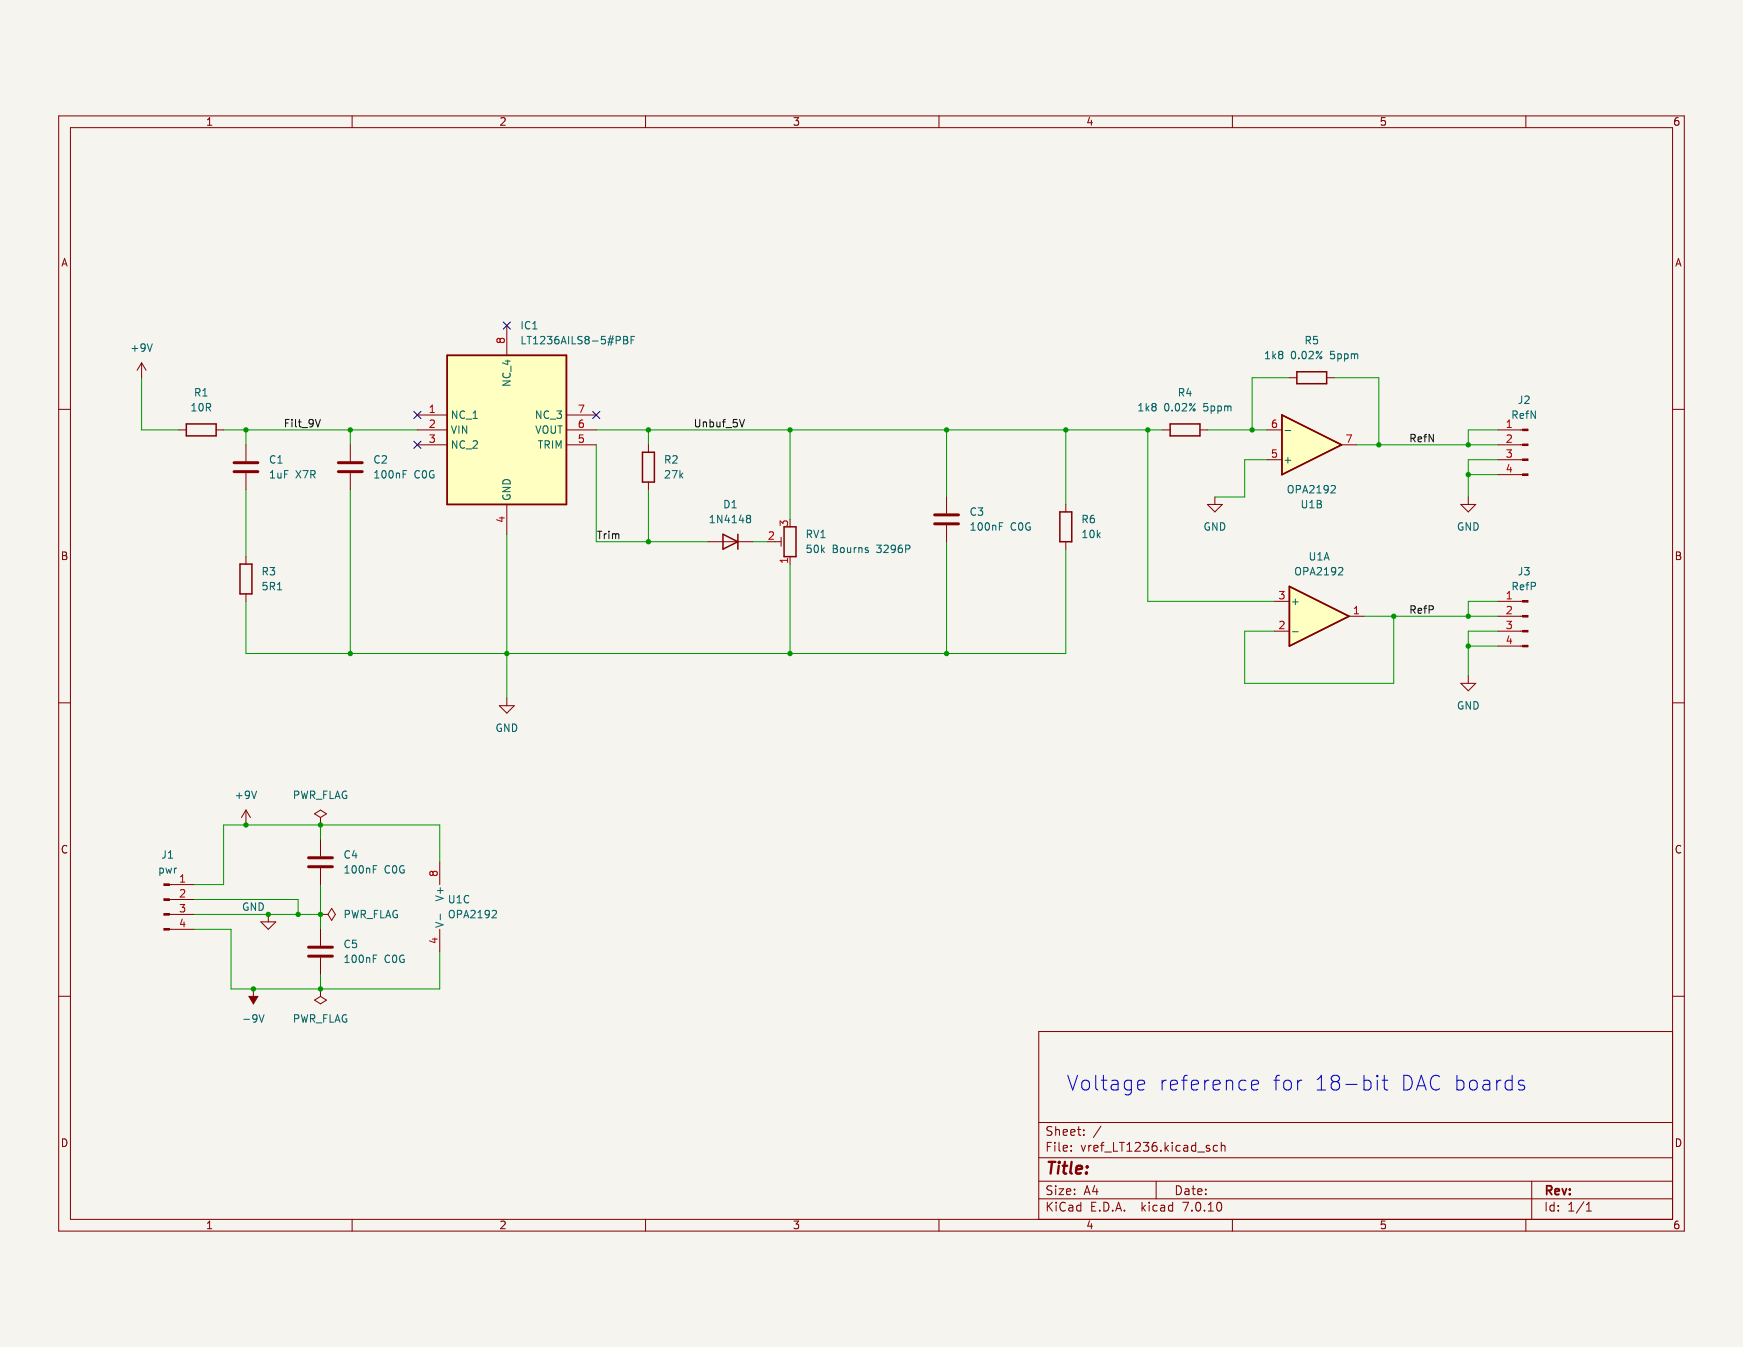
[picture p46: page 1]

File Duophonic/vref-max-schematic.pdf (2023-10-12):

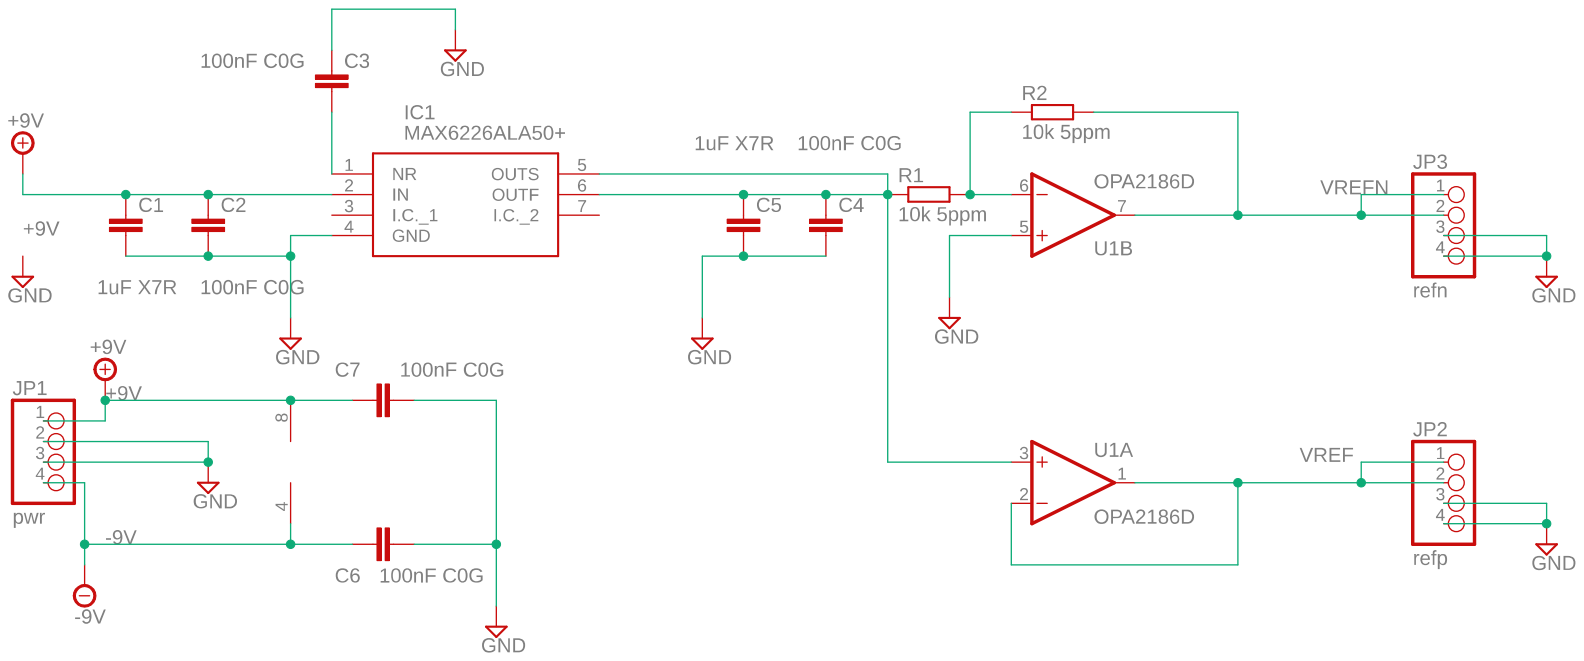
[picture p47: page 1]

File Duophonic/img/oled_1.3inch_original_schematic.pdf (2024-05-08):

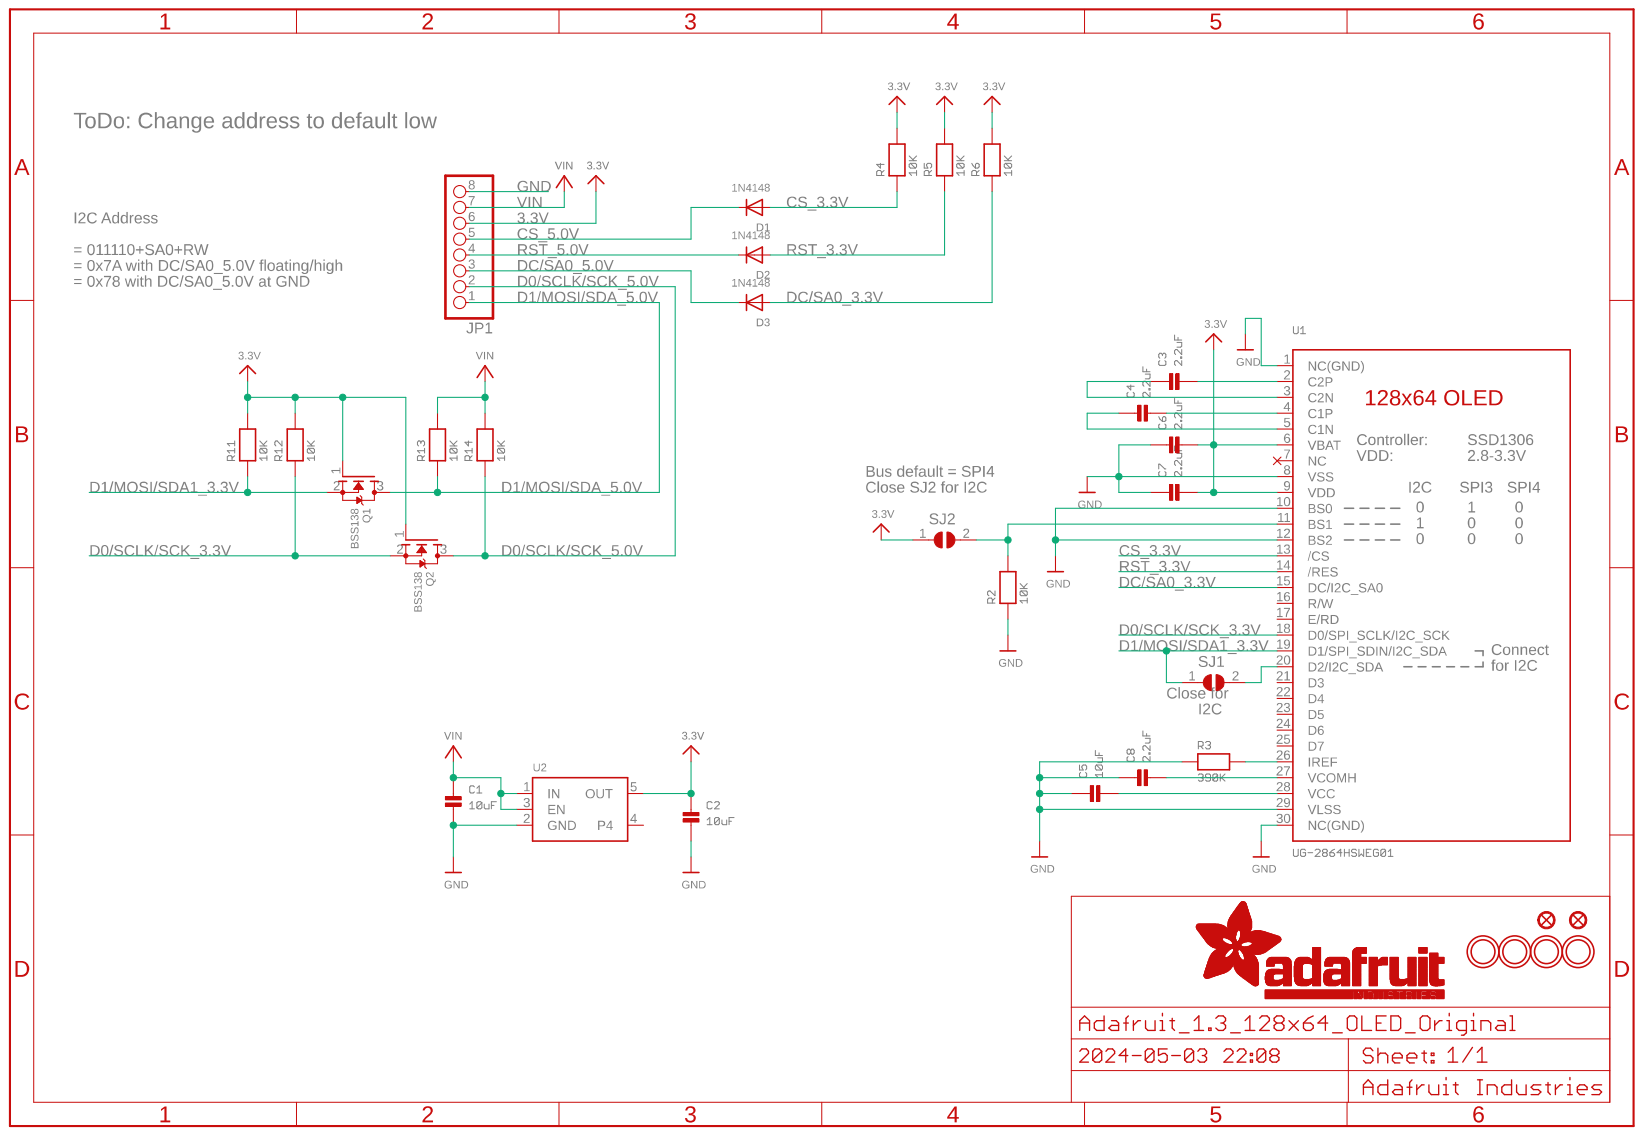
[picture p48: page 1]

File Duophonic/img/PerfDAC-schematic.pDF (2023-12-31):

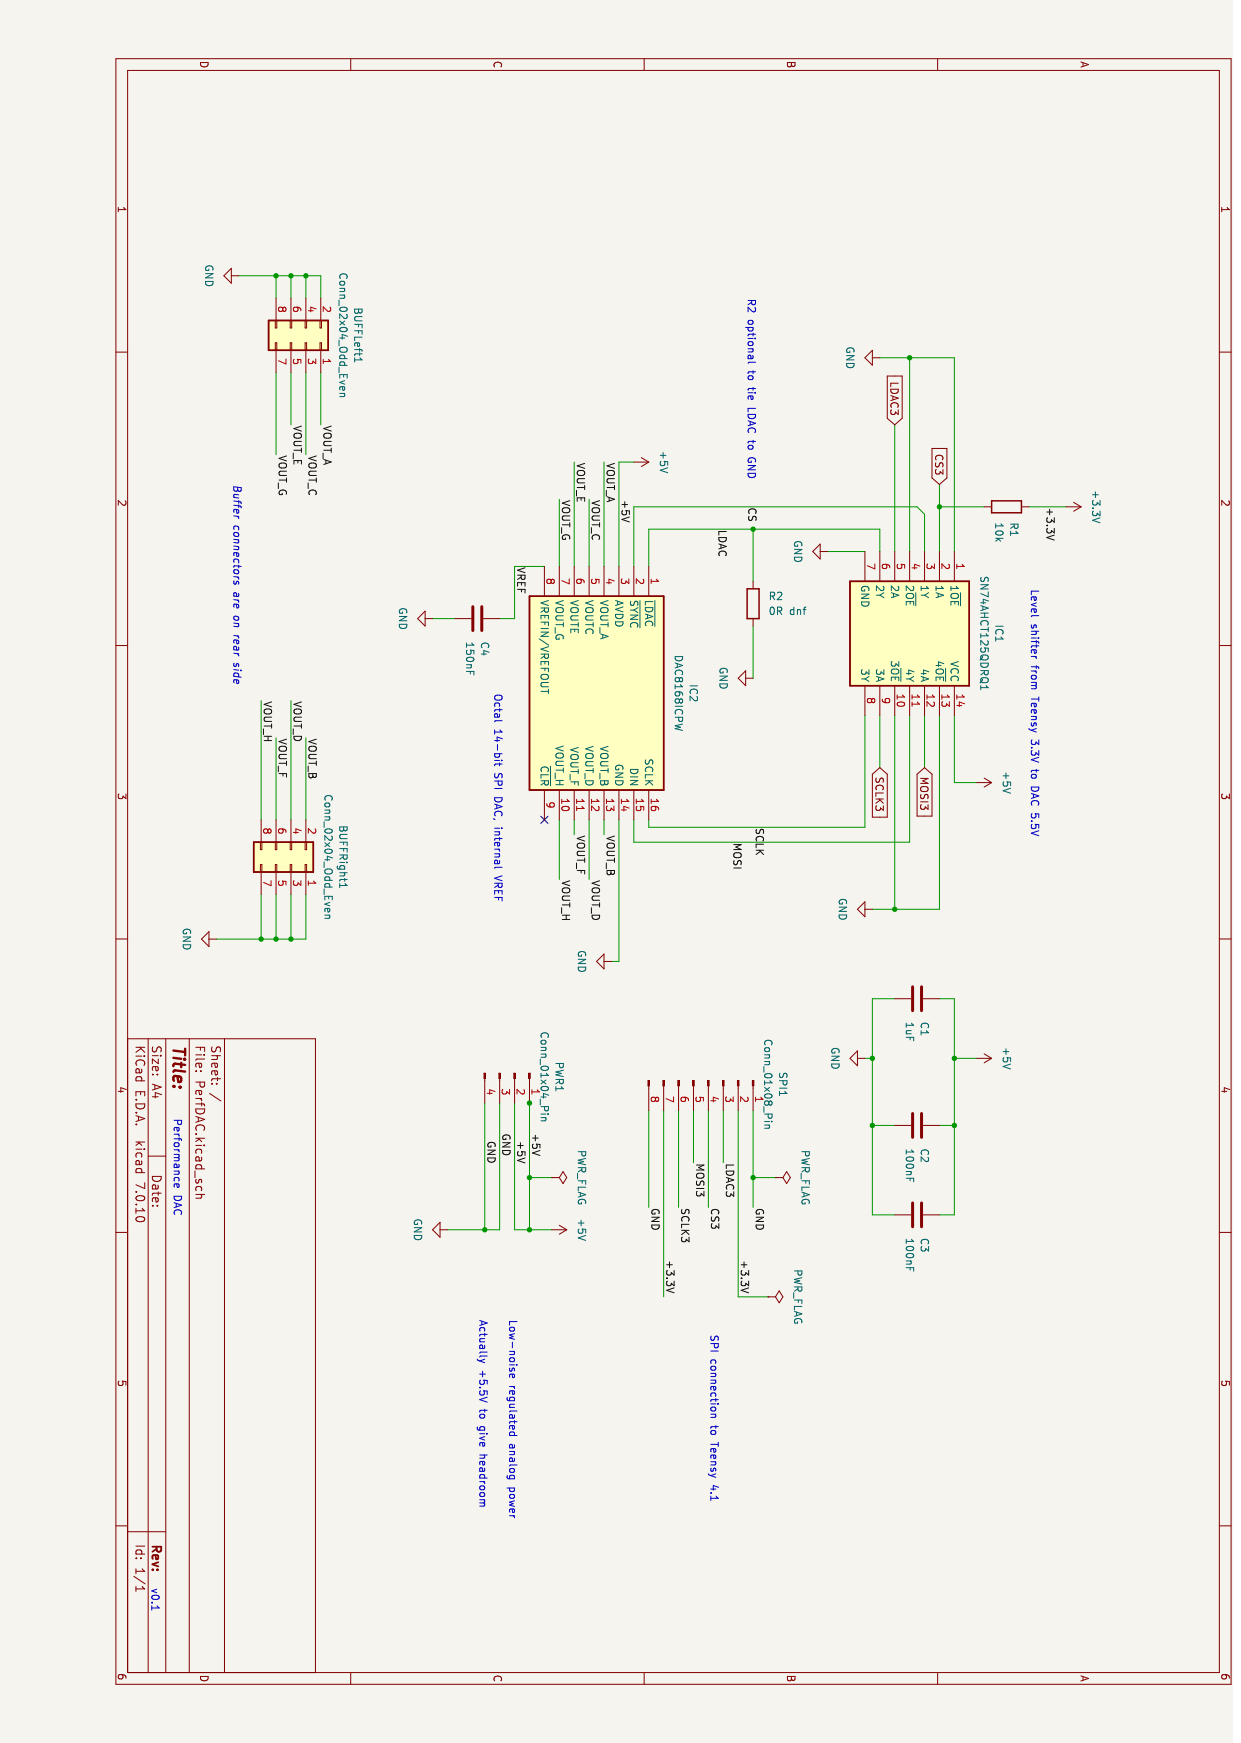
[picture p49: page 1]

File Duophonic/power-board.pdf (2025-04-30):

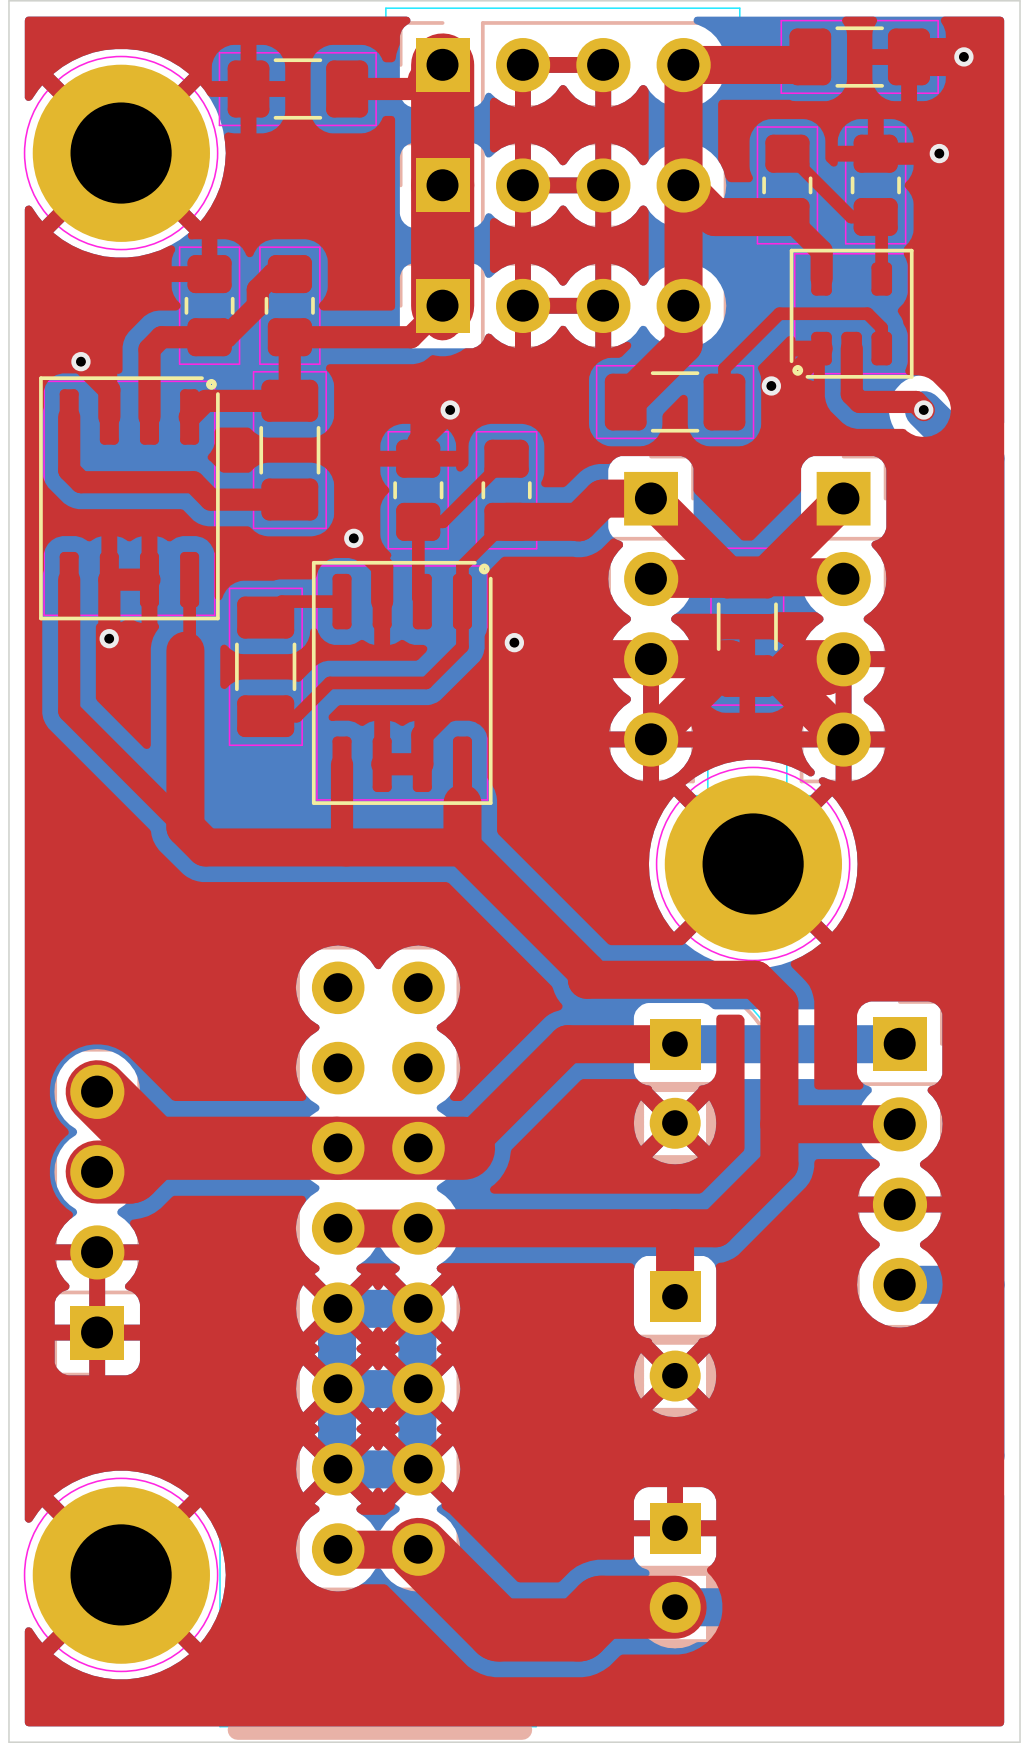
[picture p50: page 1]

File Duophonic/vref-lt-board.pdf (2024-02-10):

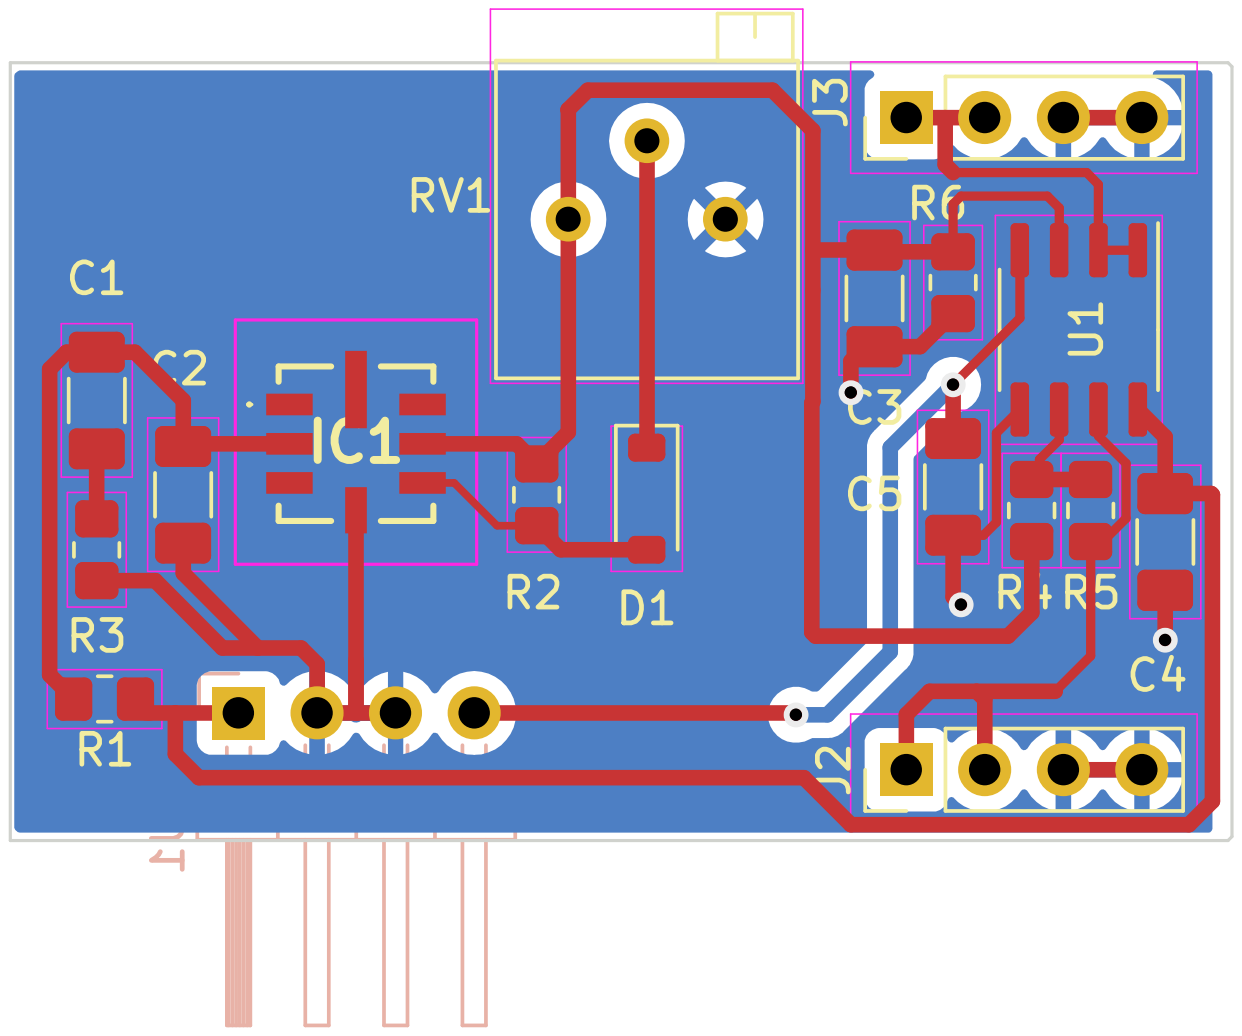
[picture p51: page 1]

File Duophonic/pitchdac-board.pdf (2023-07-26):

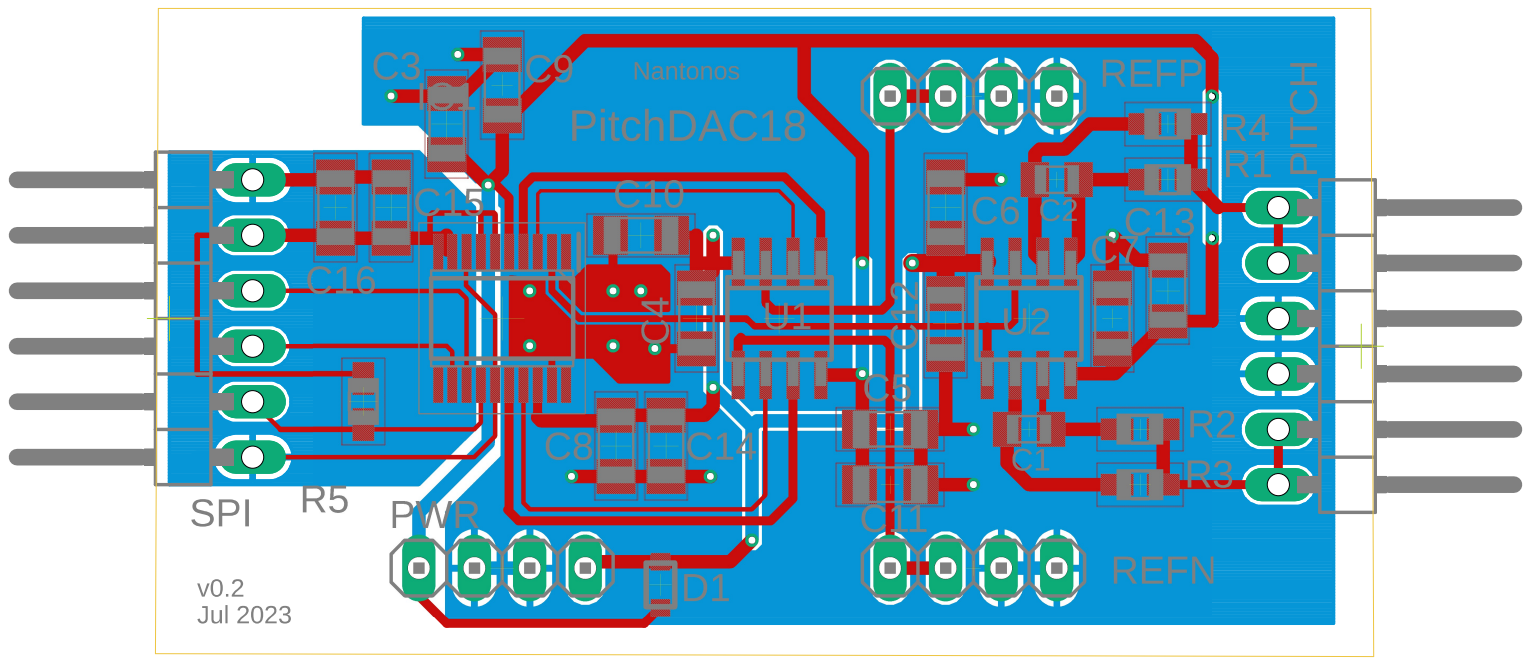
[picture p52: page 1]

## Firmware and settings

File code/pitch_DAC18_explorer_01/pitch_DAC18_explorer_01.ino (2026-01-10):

// Control AD5781 bipolar 18bit DAC for Pitch CV output
// VRefPos = +5V, VRefNeg = -5V
// Just test +Vref, 4V, 0V, -4V, -Vref
// Teensy 4.1 using SPI
// See https://wiki.analog.com/resources/quick-start/ad5791

#include <SPI.h>

// CS1 10
// CS2 8
// SCLK 13
// MOSI 11
#define CS1 10

// Comment out this line for normal operation, 
// uncomment for serial-over-USB debug
#define DEBUG

#define vals 5
const float volts[vals] = {-5.0, -4.0, 0.0, 4.0, 5.0};

uint32_t volts_to_code (float volts) {
  // trap out of range inputs
  // offset binary, not 2s complement
  if (volts < -5.0) {
    return 0; // gives Vref_N
  }
  else if (volts > 5.0) {
    return 262143; // gives Vref_P
  }
  else {
    // first convert from -5 .. 5 to 0 .. 10
    float abs_volts = volts + 5.0;
    // now generate 18-bitcode value
    const float maxval = 262143.0; // 2^18 -1
    float code = abs_volts * maxval / 10.0;
    return static_cast<uint32_t>(round(code));
  }
}

SPISettings AD5781(4000000, MSBFIRST, SPI_MODE1); // max 35MHz, start at 4 MHz

void enable () {
  // See datasheet Table 11. Control Register and Table 12. Control Register Functions
  uint8_t buffer[3];
  // remove ground clamp, remove tristate, use offset binary rather than 2's complement
  // see https://ez.analog.com/data_converters/precision_dacs/f/q-a/110156/spi-mode-of-ad5791
  buffer[2] = 0B00100000; // write to control register
  buffer[1] = 0;
  buffer[0] = 0B00010010; // OPGND to 0, 1 is the default. DACTRI to 0, 1 is default. Leave RBUF at 1. BIN/2sC to binary
  SPI.beginTransaction(AD5781);
  digitalWriteFast(CS1, LOW);
      // See https://ez.analog.com/data_converters/precision_dacs/f/q-a/27109/ad5781---not-working
  delayMicroseconds(50);
  SPI.transfer (buffer, 3); 
  digitalWriteFast(CS1, HIGH);
  SPI.endTransaction();

}

void send (uint32_t value) {
  // See datasheet Table 10. DAC Register
  // LDAC tied low, CLR, RESET tied high.
  // value is 18-bit value to send  to DAC
  uint8_t buffer[3];
  // pad to 20 bits
  value = value << 2;// //
  // MSB has R/W and Address bits
  // 0 0 0 1 = The DAC register is loaded with the clearcode register value, and the output is set accordingly
  buffer[2] = (value >> 16) | 0B00010000;
  buffer[1] = value >> 8;
  buffer[0] = value;
#ifdef DEBUG
    Serial.print("value ");
    Serial.println(value);
    Serial.println(value, HEX);
    Serial.println();
    Serial.print("buffer (hex) ");
    Serial.println(buffer[0], HEX);
    Serial.println(buffer[1], HEX);
    Serial.println(buffer[2], HEX);
    Serial.println();
#endif
  SPI.beginTransaction(AD5781);
  digitalWriteFast(CS1, LOW);
      // See https://ez.analog.com/data_converters/precision_dacs/f/q-a/27109/ad5781---not-working
  delayMicroseconds(50);
  SPI.transfer (buffer, 3); 
  digitalWriteFast(CS1, HIGH);
  SPI.endTransaction();
}


void setup() {
  pinMode(CS1, OUTPUT);
  digitalWrite(CS1, HIGH);
#ifdef DEBUG
  while (!Serial);
#endif
  delay(2000);
  SPI.begin();
  enable();
}

void loop() {
  // 5 steps
  uint32_t val;
  //for (int i=0; i<vals; i++) {
#ifdef DEBUG
    //Serial.print("volts ");
    //Serial.println(volts[i]);
    //Serial.println();
#endif
    //val = volts_to_code(volts[i]);
    // send(val);

    // just send a hardcoded value for +4V
    // which is 9/10 along the -5V to +5V range
    // 262,143 × 9 ÷ 10 = 235,928.7
    val = 235929;
    send(val);
#ifdef DEBUG
    //Serial.print("val ");
    //Serial.println(val);
    //Serial.println(val, HEX);
    //Serial.println();
#endif
    delay(10000);   
  // }

}

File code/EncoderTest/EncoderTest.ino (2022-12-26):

// working 02 Mar 2018
// Sparkfun RGB encoder
// 10k from A, B pins to output
// 50nF from output to 0V
// C pin to 0V
// no pullup (library uses internal pullup)
// "+" pin on breakout seems to be an (unconnected) 0V
// so connect to Teensy 0V

#include <Encoder.h> 
#include <Bounce.h>

Encoder enc(0,1); // create an encoder object

const int switchPin = 2;
Bounce pushbutton = Bounce(switchPin, 5);  // 5 ms debounce

int32_t current_value; // current read
int32_t previous_value = -999; // previous read

byte previousState = HIGH;         // what state was the button last time
unsigned int count = 0;            // how many times has it changed to low
unsigned long countAt = 0;         // when count changed
unsigned int countPrinted = 0;     // last count printed

void setup() {
  pinMode(switchPin, INPUT_PULLUP);
  Serial.begin(57600); // open serial port
  while(!Serial);
}

void loop() {
   
  current_value = enc.read(); // read the value of the encoder
  
  if (current_value != previous_value) { // compare to previous reading
    Serial.println(current_value); // if it's changed, print to serial port
    previous_value = current_value; // store the reading for next comparison
  }
  if (pushbutton.update()) {
    if (pushbutton.fallingEdge()) {
      count = count + 1;
      countAt = millis();
      current_value = 0;  
      enc.write(current_value); // reset
      Serial.println(current_value); 
      previous_value = current_value; // store the reading for next comparison
    }
  } else {
    if (count != countPrinted) {
      unsigned long nowMillis = millis();
      if (nowMillis - countAt > 100) {
        Serial.print("count: ");
        Serial.println(count);
        countPrinted = count;
      }
    }
  }
}

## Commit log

2017-12-09 Add power considerations, minor updates
2018-01-06 split out pitch dac
2018-01-24 add boards list, more test results
2018-01-26 mention resistor tolerances
2018-02-17 split out calibration
2018-02-20 pitch dac
2018-03-04 encoder test done
2018-05-16 select pitch op-amp
2018-06-03 update list of boards
2018-11-25 Dixie2 oscillator data, etc
    [Dixie2 frequency linearity.xlsx, dixie-2-sq.csv, dixie2.ods]
2018-11-27 L-1 THAT-2180 oscillator
    [L-1.csv]
2018-11-28 L-1 changes
    [L-1.csv]
2020-01-04 lower limit of f
    [L-1.csv]
2020-05-15 current limit
2021-01-31 start work on the microcontroller board
2022-12-26 cumulative offline updates
    [L-1.csv, Tona.csv, dixie-2-sq.csv]
2023-01-14 Duophonic pitch
2023-01-16 Duophonic pitch DAC
2023-01-21 Supply-chain updates
2023-02-13 pcb dimensions
2023-02-20 schematic & board
2023-02-20 board updates
2023-02-22 pitch dac layout
2023-02-27 connector sizes
2023-02-28 resistor array
2023-03-05 LEDs are hard
2023-03-12 more BOM
2023-03-18 Negative regulator
2023-04-02 v0.1 boards ordered
2023-04-19 LED stuff
2023-06-24 duophonic calibration
2023-06-27 start perfdac board
2023-07-16 update boards, few improvements
2023-07-16 Add Eagle files
    [Vref.brd, Vref.sch, pitchdac.brd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]
2023-07-18 tune-in circuitry
2023-07-22 Add Teensy. Getting cramped!
2023-07-24 Mounting holes
2023-07-26 v.01 board was wrong
2023-08-31 T4.x power consumption
2023-10-05 Update BOM
2023-10-12 Update old schematics
2023-10-14 need for calibration measurements in code
2023-10-14 correct stupid error
    [pitchdac.brd, pitchdac.sch]
2023-10-15 re-ordered board
2023-10-18 second vref sample
2023-10-21 RC filtering works
2023-11-04 better resistors
2023-12-02 more MPU board, update panel mockup
    [MPU-pinout.xlsx]
2023-12-12 Better encoder knob
2023-12-28 PerfDAC schematic, board
2023-12-29 Add KiCad schematic and board
2023-12-29 Add board connectors
2023-12-31 NEW SCHEMATIC
2023-12-31 board laid out
2024-01-01 prefdac connectors
2024-01-04 spi advice
2024-01-05 Alternate voltage reference
2024-01-09 More on SPI
2024-02-03 more on LED
2024-02-03 pwm stuff
2024-02-05 update pins for timer usage
    [MPU-pinout.xlsx]
2024-02-05 More on timers
2024-02-10 update lt1236 vref schematic
2024-02-10 ordered vref lt1236 board
2024-02-29 Link to working multi-device config
2024-05-08 display connections
    [MPU-pinout.xlsx]
2024-05-08 better pinout
    [MPU-pinout.xlsx]
2024-05-13 update MPU board
2024-07-03 link to KiCad socketed MPU
2024-07-06 detect device
2024-07-15 ADC input caps
2024-08-03 tune input filtering
2024-08-05 tune circuitry, rise setup
2024-08-13 temperature effect on calibration
2024-08-22 alternative low-tempco resistors
2024-09-04 Better buttons
2024-09-04 encoder knobs
2024-09-10 encoder, led updates
2024-09-15 DataPro USB connectors
2024-09-16 More usb connector stuff
2024-10-07 NeoPixel LEDs
2024-10-18 Tune-in board
    [Tune-in.kicad_pcb, Tune-in.kicad_sch]
2024-11-03 panel twak for encoder knob, relocate power
2024-11-03 tune-in details
    [Tune-in.kicad_pcb, Tune-in.kicad_sch]
2024-12-30 Host current limit
2025-01-09 major refactor as perfdac board was too tall
2025-02-13 logic shifter allowed current
2025-03-18 USB Host current limits
2025-03-18 beefy cables
2025-03-18 more on USB Host power
2025-03-28 Power board v0.1
2025-03-28 more on power
2025-03-28 remove old power components from MPU board
2025-04-08 power board
2025-04-10 Power BOM
2025-04-30 through-hole done
2025-04-30 exports from KiCad
2025-05-02 power measurements
2025-05-02 power up testing done
2025-05-05 actual buffer circuit
2025-05-15 buffer bom
2025-05-15 shoehorning tiny pcbs
    [MPU-pinout.xlsx]
2025-05-16 rough positioning of dac, buffers, jack board and power
2025-05-21 buffer to other dac board
2025-05-27 clean up EDA
    [Tune-in.kicad_pcb, Tune-in.kicad_sch, Vref.brd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]
2025-06-13 KiCad for PitchDAC v0.3
    [PitchDAC.kicad_pcb, PitchDAC.kicad_sch, pitchdac.brd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]
2025-06-30 Vishay board
2025-07-15 linkfix, Arduino broke their docs
2025-07-15 sample sketch
2025-07-16 KiCad projects
    [PerfDAC.kicad_pcb, PerfDAC.kicad_sch, PerfDAC_buffers.kicad_pcb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]
2025-07-21 cleanup kicad by removing old backups
2025-08-15 first results from board 2
2025-08-26 power consumption
2025-08-27 finish PerfDAC v0.2 board
    [PerfDAC.kicad_pcb, PerfDac_v02_extbuf.kicad_pcb, PerfDac_v02_extbuf.kicad_sch]
2025-08-27 SPI pinouts
2025-08-27 power requirements
2025-08-29 better layout
    [MPU-test.kicad_pcb, MPU-test.kicad_sch]
2025-09-06 MIDI tester board
2025-09-28 Added worst-case option if AD5781 can't be got working
2025-09-28 Update KiCad files
    [MPU-Display.kicad_sch, MPU-test.kicad_sch]
2025-10-05 vref board 2 results
2025-10-06 board 2 resistor matching
2025-10-15 final long-term board 2 negative ref results
2025-10-15 board 1 ppm as well
2025-10-16 pitchdac board 2 photo
2025-11-21 don't cross the grounds!
2025-12-29 Add prototype DIN MIDI input board
2025-12-30 Next steps to debug SPI
2026-01-10 More SPI tweaking
2026-01-12 More SPI stuff
2026-02-09 third board
2026-02-18 perfdac board ordered
2026-04-11 boards arrived from OSH
2026-11-06 Started integration testing, MPU & Power & PitchDAC
